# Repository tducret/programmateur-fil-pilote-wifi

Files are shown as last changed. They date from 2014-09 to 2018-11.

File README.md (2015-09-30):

Le programmateur fil pilote WiFi open source
============================================

Principe
--------
Avec de simples requêtes HTTP, vous allez pouvoir :
- **Contrôler vos chauffages électriques** (7 zones / 4 ordres fil pilote)
- **Récupérer votre consommation électrique** (et toutes les informations du compteur électrique)

Avantages :
- **Pas de serveur dédié nécessaire**
- **Intégration facile dans le tableau électrique**
- **Connexion WiFi** (pas de câble Ethernet à connecter)

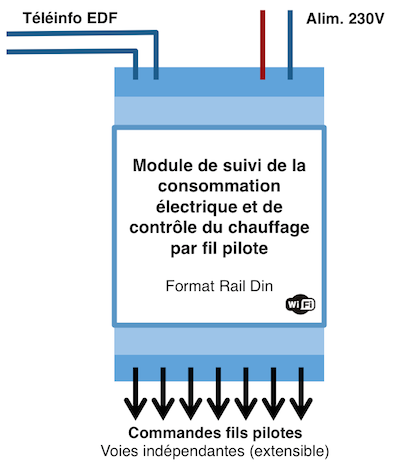
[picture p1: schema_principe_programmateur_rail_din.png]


Idées d'applications
--------------------
- Contrôle de la température de chaque pièce via votre box domotique
- Coupure du chauffage automatique en cas de consommation électrique trop importante (délestage)
- Lancement du chauffage en partant du travail à partir de votre smartphone
- Et bien d'autres...

Licence
-------
Les codes sources sont distribués sous la licence MIT
Les autres éléments sont distribués sous la licence [Creative Commons Attribution-NonCommercial-ShareAlike 4.0](https://creativecommons.org/licenses/by-nc-sa/4.0/)

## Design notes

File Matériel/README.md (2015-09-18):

Liste matériel 
==============

BOM File
--------
Vous trouverez la liste du matériel en fonction de la version à l'adresse [suivante][1] (google doc)

[1]: https://docs.google.com/spreadsheets/d/1HEebySHMIzUFYeRYVwTHakMmaWHZ26DxMvw0GtgDD7c

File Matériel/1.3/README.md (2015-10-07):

Version matérielle 1.3
=======================

Modifications
-------------
Cette version reprend toutes les caractéristiques de la version [initiale][1] en y ajoutant les fonctionnalités suivantes :

- Ajout d'un contrôleur d'entrées sortie I2C [MCP23017][10] pour libérer les I/O du Spark Core
- Possibilité de mettre deux types de relais dont un [avec contact NO + NF][5]
- Possibilité de mettre un emetteur récepteur sans fil de type [RFM12B][6], [RFM69CW][7], [RFM69HW][8] ou [RFM69CW][9] 433Mhz ou 868MHz
- Possibilité de mettre un [récepteur 433MHz][4] pour récupérer par exemple les trames des capteurs de température Orégon Scientific
- Ajout d'un connecteur I2C ET SPI pour des afficheurs OLED de type [I2C][2] ou [SPI][3]
- Ajout d'un connecteur de type Grove I2C
- Ajout d'une LED 3mm (déportable ou non) sur le boitier 
- Ajout de pin out disponibles sur toutes les pattes du Spark Core

Changements apportés dans la révision 1.3 vs 1.2 
- Ajout d'un étage a MOSFET pour la téléinfo, pour une meilleure compatibilité di signal téléinfo
- Ajout d'une RGB LED pour ESP8266
- Ajout d'un pont diviseur sur le recepteur 433MHZ pour transformer sa sortie 5V en 3V3 pour l'ESP8266
- Possibilité de mettre une base ESP8266 (NodeMCU) via cet [adaptateur][11]

Description Détaillée
=====================

**Schematic**  
schematic

**Boards**  
board&nbsp;
top&nbsp;
bottom

[1]: https://github.com/thibdct/programmateur-fil-pilote-wifi/blob/master/README.md
[2]: http://www.ebay.com/itm/291216700457
[3]: http://www.ebay.com/itm/141371873602
[4]: http://www.ebay.com/itm/290935235157
[5]: http://www.seeedstudio.com/depot/index.php?main_page=opl_info&opl_id=136

[6]: http://www.anarduino.com/details.jsp?pid=142
[7]: http://www.anarduino.com/details.jsp?pid=145
[8]: http://www.anarduino.com/details.jsp?pid=136
[9]: http://www.anarduino.com/details.jsp?pid=122
[10]: http://www.adafruit.com/product/732
[11]: https://github.com/hallard/Particle2NodeMCU

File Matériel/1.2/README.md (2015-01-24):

Version matérielle 1.2c
=======================

Modifications
-------------
Cette version reprend toutes les caractéristiques de la version [initiale][1] en y ajoutant les fonctionnalités suivantes :

- Ajout d'un contrôleur d'entrées sortie I2C [MCP23017][10] pour libérer les I/O du Spark Core
- Possibilité de mettre deux types de relais dont un [avec contact NO + NF][5]
- Possibilité de mettre un emetteur récepteur sans fil de type [RFM12B][6], [RFM69CW][7], [RFM69HW][8] ou [RFM69CW][9] 433Mhz ou 868MHz
- Possibilité de mettre un [récepteur 433MHz][4] pour récupérer par exemple les trames des capteurs de température Orégon Scientific
- Ajout d'un connecteur I2C ET SPI pour des afficheurs OLED de type [I2C][2] ou [SPI][3]
- Ajout d'un connecteur de type Grove I2C
- Ajout d'une LED 3mm (déportable ou non) sur le boitier 
- Ajout de pin out disponibles sur toutes les pattes du Spark Core

Changements apportés dans la révision 1.2c 
- Correction informations du silk au niveau du connecteur grove
- Déplacement connecteur grove pour ne pas géner en cas d'insertion un module grove
- Déplacement de la LED pour qu'elle ne soit plus située sous le LCD
- Agrandissement des PAD des optos pour une soudure plus aisée
- Inversion des plots 3.3V et GND afin de pouvoir souder un double plot uniquement (5V+GND), les triples étant moins facile à trouver et je suis pas certain que le 3.3V soit utilisé (mais il reste disponible)

Attention, deux erreurs étaient présentes sur le PCB 1.2 original (corrigées dans la revision 1.2c) :
- le dessin sur le PCB du connecteur grove est inversé, donc si vous souhaitez le souder, il faut le faire dans le sens inversé par rapport au dessin du PCB (mais toujours à souder sur le dessus).
- la diode D14 est inversée, il faut donc la souder dans le sens inverse de ce qui est indiqué sur le PCB

Description Détaillée
=====================

**Schematic**  
schematic

**Boards**  
board&nbsp;
top&nbsp;
bottom

[1]: https://github.com/thibdct/programmateur-fil-pilote-wifi/blob/master/README.md
[2]: http://www.ebay.com/itm/291216700457
[3]: http://www.ebay.com/itm/141371873602
[4]: http://www.ebay.com/itm/290935235157
[5]: http://www.seeedstudio.com/depot/index.php?main_page=opl_info&opl_id=136

[6]: http://www.anarduino.com/details.jsp?pid=142
[7]: http://www.anarduino.com/details.jsp?pid=145
[8]: http://www.anarduino.com/details.jsp?pid=136
[9]: http://www.anarduino.com/details.jsp?pid=122
[10]: http://www.adafruit.com/product/732

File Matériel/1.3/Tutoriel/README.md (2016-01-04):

# Tutoriel d'assemblage de Remora v1.3

<!--Liste de toutes les images utilisées-->
[Schéma implantation]: ../ProgrammateurFilPilote_1.3_Schematic.png
[PCB face avant]: ../ProgrammateurFilPilote_1.3_Recto.png
[PCB face arrière]: ../ProgrammateurFilPilote_1.3_Verso.png
[Le contenu du kit]: Images/Le_contenu_du_kit.jpg
[Outillage]: Images/Outillage.jpg

## Remora

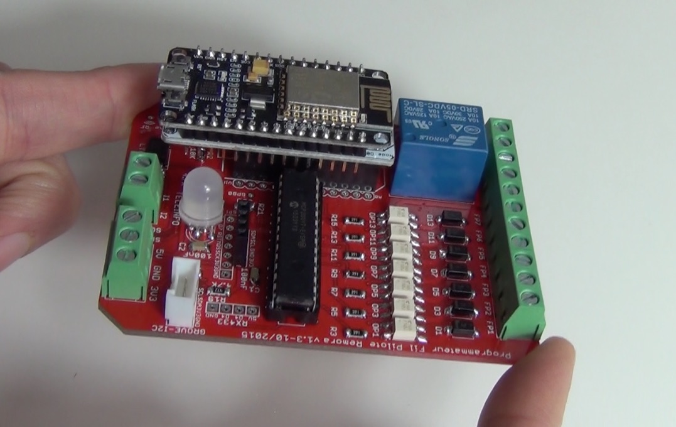
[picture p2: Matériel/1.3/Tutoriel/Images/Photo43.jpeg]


Remora, c'est un programmateur de chauffages par fils pilotes.

- Il peut contrôler 7 zones et un chauffe-eau (via 1 relais)
- Il se commande via des requêtes HTTP en WiFi
- Il est open source et open hardware

## Contenu du kit
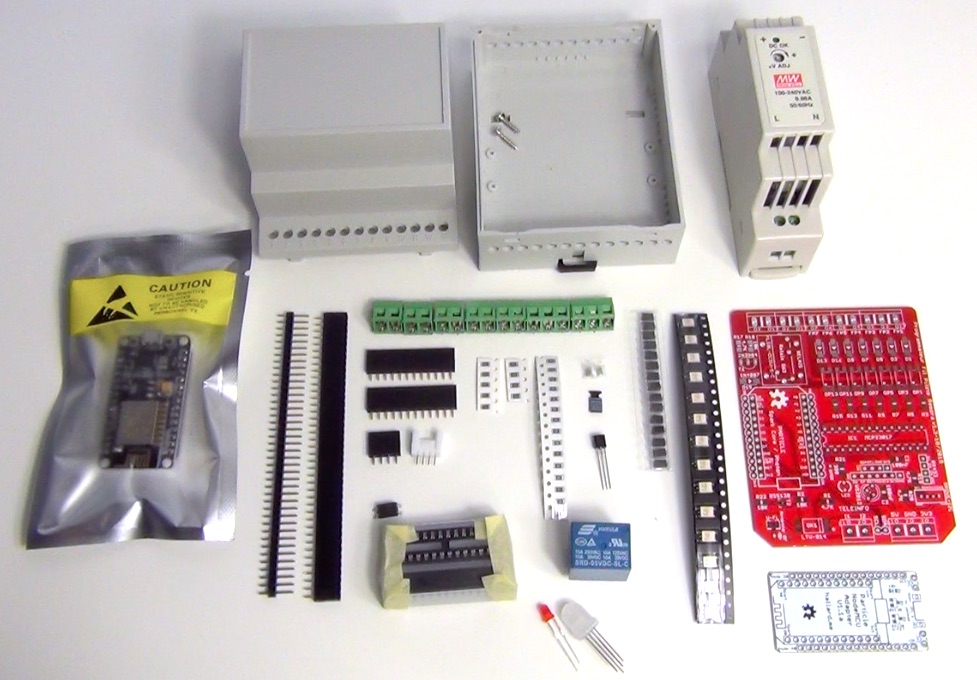
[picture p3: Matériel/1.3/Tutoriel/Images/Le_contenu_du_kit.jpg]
Le contenu du kit


- 1 NodeMCU
- 1 Boîtier RAIL DIN (4U : 71 x 90 x 58 mm)
- 1 Circuit imprimé Remora (v1.3)
- 1 Circuit imprimé Adaptateur NodeMCU->Remora (v1.1a)
- 1 Alimentation 5V RAIL DIN (1U - 12W)
- 14 Optotriacs
- 15 Diodes
- 1 MCP23017
- 1 Support MCP23017
- 2 Connecteur 1x12pt femelle Remora->NodeMCU
- 1 Barrette 40 pins male
- 1 Barrette 40 pins femelle
- 1 LED rouge 3mm
- 1 Transistors NPN
- 1 Led RGB 5mm
- 1 Relais
- 2 Borniers 3pts
- 5 Borniers 2 pts
- 1 Optocoupleur Teleinfo
- 1 Transistor BSS138
- 4 Resistance 10KΩ (format 1206)
- 5 Resistance 4.7KΩ (format 1206)
- 15 Resistance 390Ω (format 1206)
- 2 Condensateur 100nF (format 1206)
- 1 Connecteur 1x4pt OLED femelle
- 1 Connecteur Grove

## Outillage

Pour réaliser le module, vous aurez besoin de :

- 1 Fer à souder à pointe fine [^1]
[^1]: J'utilise un Antex XS25.
- 1 Bobine de fil d'étain (de préférence 0,5 mm)
- 1 Multimètre (pour vérifier les soudures)
- 1 Pince coupante
- 1 Petite pince (ou brucelle)
- 1 troisième main (facultatif mais bien utile) 

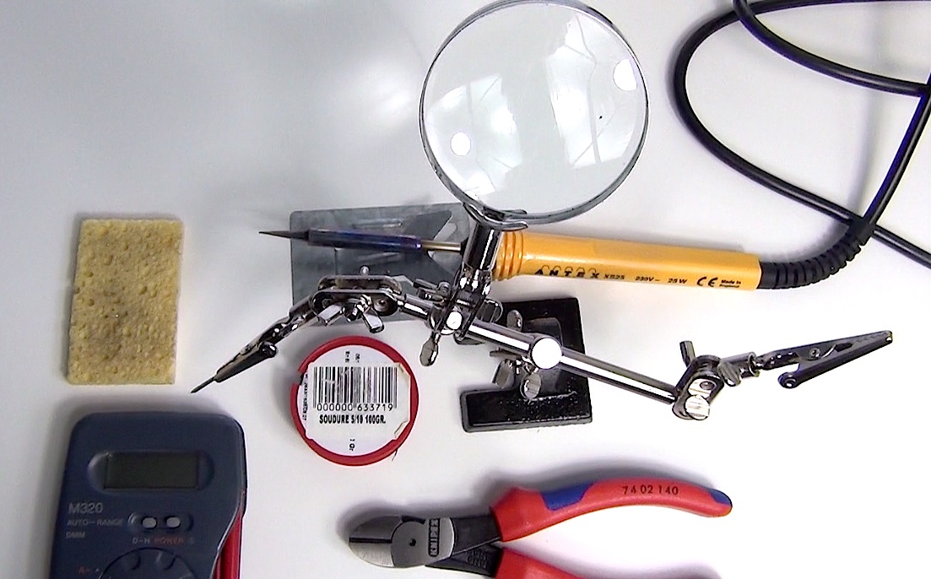
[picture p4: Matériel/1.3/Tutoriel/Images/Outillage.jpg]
Outillage


## Schéma d'implantation

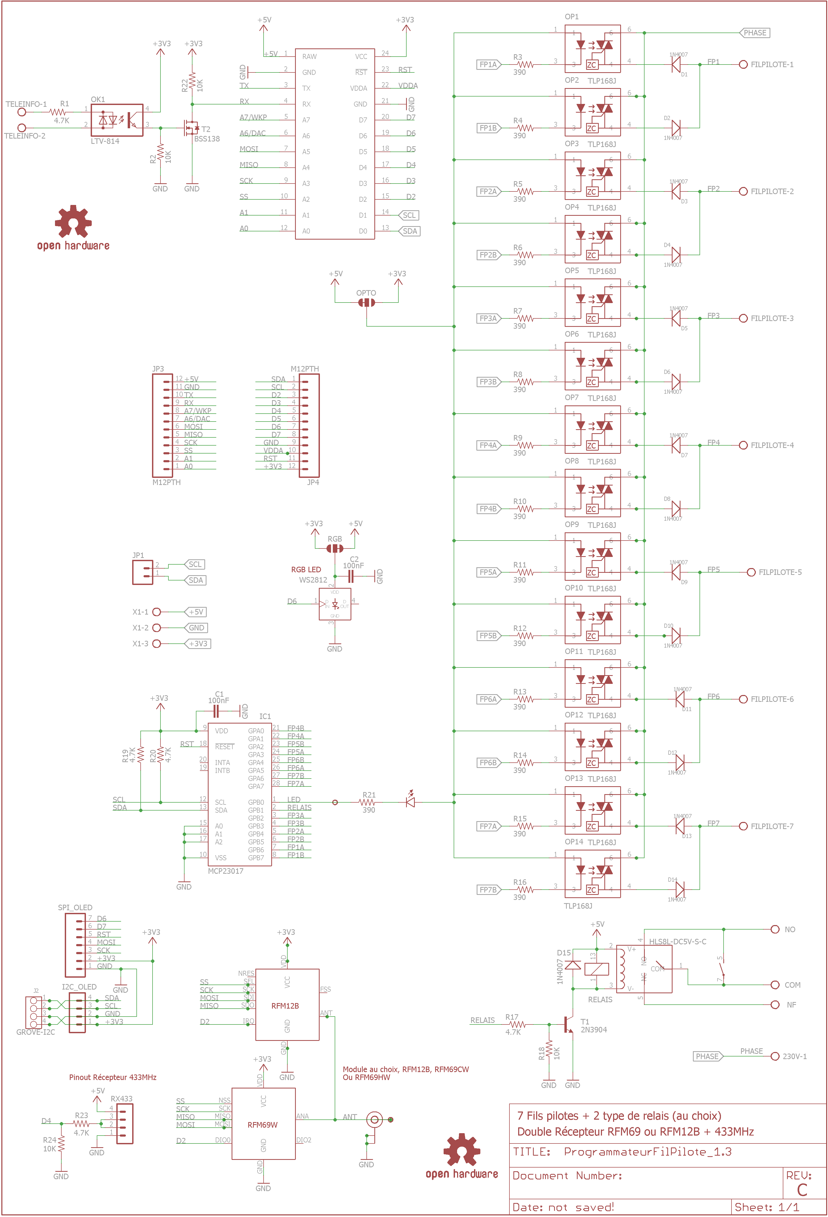
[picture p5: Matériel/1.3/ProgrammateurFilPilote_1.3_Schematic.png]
Schéma implantation


*Nota : Il est bien utile d'avoir un exemplaire imprimé du schéma d'implantation près de soi lorsque l'on fait les soudures*

## Le circuit imprimé

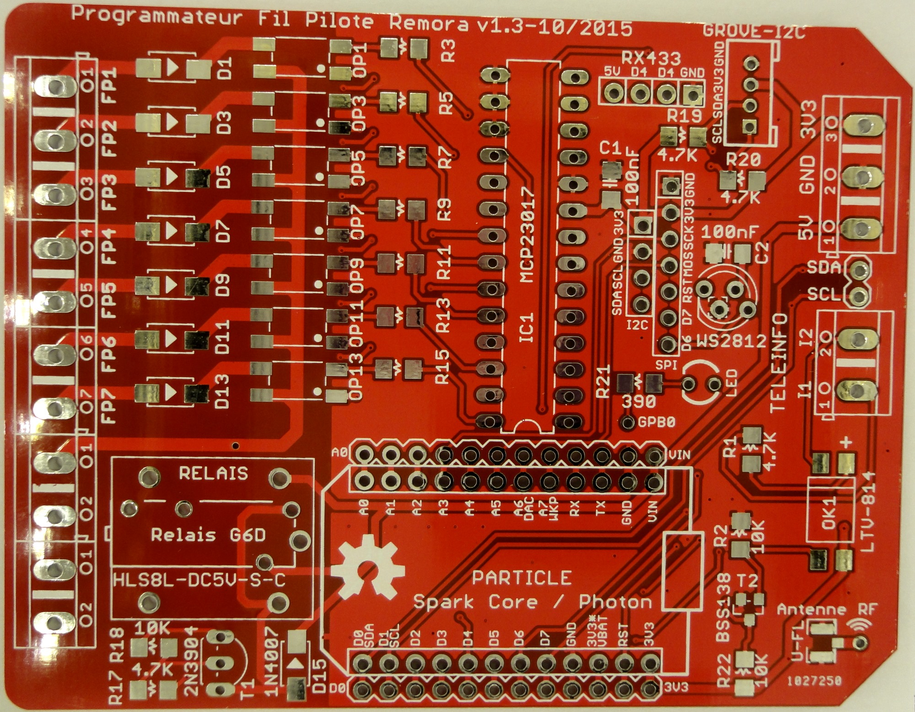
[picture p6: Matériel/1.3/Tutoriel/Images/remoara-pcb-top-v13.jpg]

**Face avant**

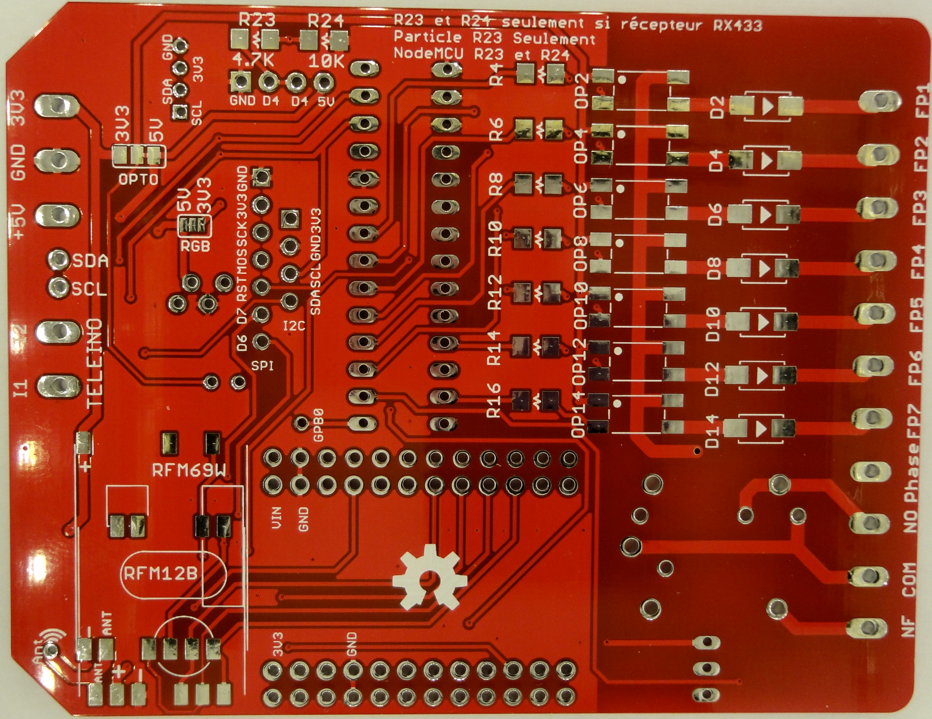
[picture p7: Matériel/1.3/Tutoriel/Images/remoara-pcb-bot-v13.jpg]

**Face arrière**

Identifiant du composant	| Description
--------------------------	| -----------------------------
R1, R17, R19, R20			| Résistance de 4,7KΩ
R2, R18, R22				| Résistances de 10KΩ
R3 à R16, R21				| Résistances de 390Ω
D1 à D15					| Diodes de redressement
T1							| Transistor NPN (2N3904)
T2							| Transistor Opto BSS138
OP1 à OP14					| Optotriacs
C1, C2						| Condesateurs 100nF
IC1							| MCP23017
OK1							| Optocoupleur LTV-814S

Non utilisés dans le kit : R23, R24

## Soudure

L'objectif est de souder les composants dans un ordre nous permettant de ne pas être gêné.  
La stratégie est simple : **on va souder les petits composants avant les gros, en commençant par la face avant, puis la face arrière.**

### Face avant

----------

##### Soudure des diodes D1, D3, D5, D7, D9, D11 et D13
'M7' est indiqué sur chacune des diodes. La barre à gauche du 'M' indique la cathode.  
**Il faut souder chaque diode de cette face en mettant la barre du côté de D1, D3...**
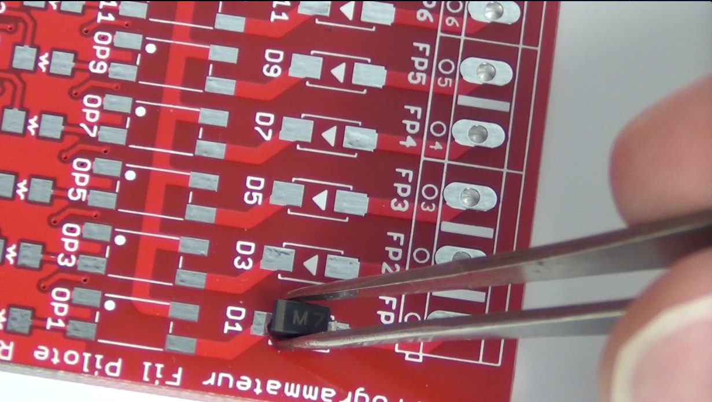
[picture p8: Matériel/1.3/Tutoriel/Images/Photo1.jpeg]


**Astuce de soudure CMS**
J'utilise ma "troisième main" et une simple pointe pour maintenir les composants de petite taille
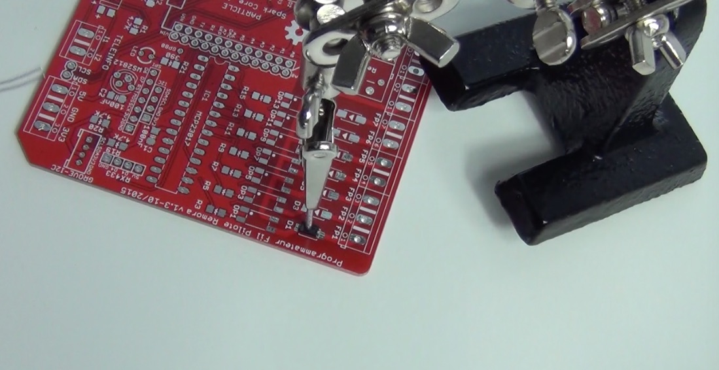
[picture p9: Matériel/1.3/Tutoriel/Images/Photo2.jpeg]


*Autre astuce, la favorite de Charles qui n'a pas de 3eme main*
Regardez cette [video][3] à 1M50 c'est beaucoup plus clair que mes explications (pas besoin de flux au pinceau, pas d'inquiètude) et très bien détaillé. 
Attenton contraitement à la vidéo, pour souder le 2eme pad il vaut mieux chauffer le pad plutôt que mettre la soudure sur la panne du fer (sauf si vous avez du flux).

Donc en résumé :
- Soudure dans une main, fer dans l'autre et on met un peu de soudure sur une pastille du PCB de chaque composant à placer
- Pince + composant dans une main, fer dans l'autre et on les place en chauffaut la soudure dejà placée
- Soudure dans une main, fer dans l'autre et on soude les autres pastilles des composants déjà placés.

Voici ce que ça donne de plus près, retour à la méthode de Thibault
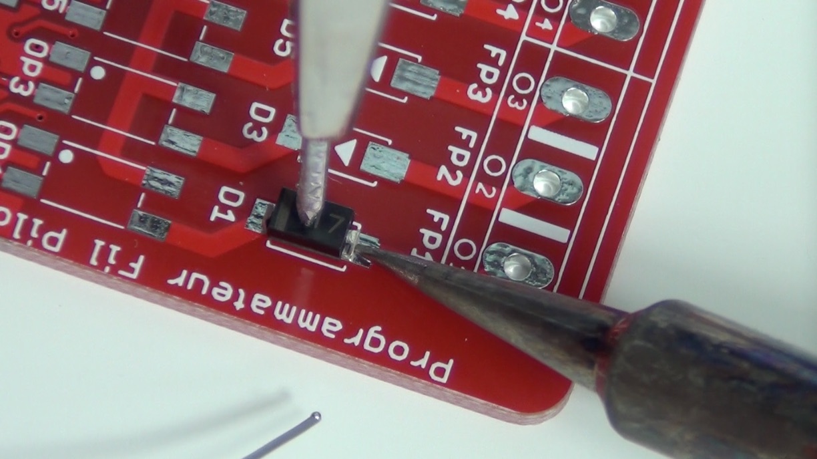
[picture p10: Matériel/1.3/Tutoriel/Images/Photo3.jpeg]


Et une fois les 7 diodes terminées

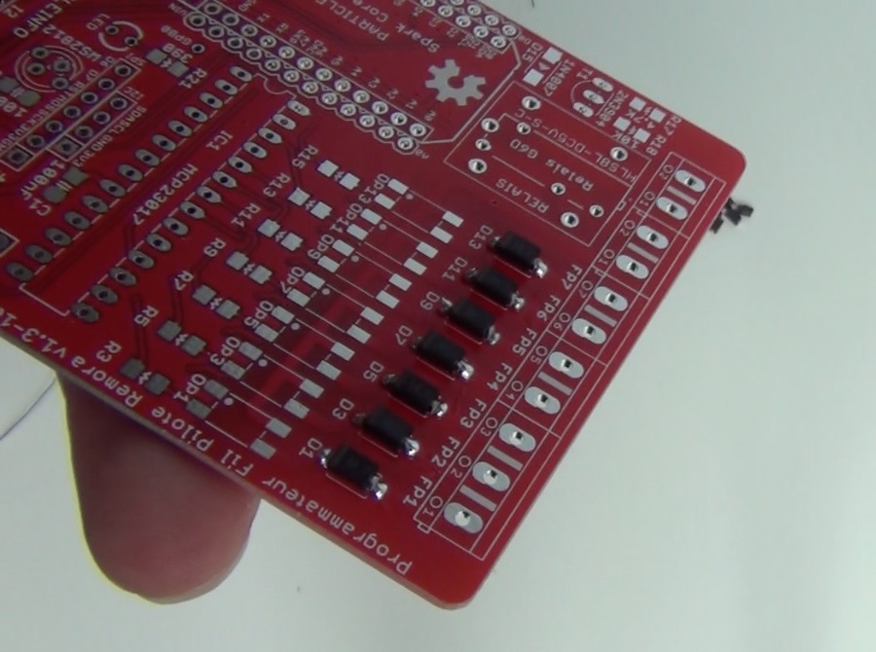
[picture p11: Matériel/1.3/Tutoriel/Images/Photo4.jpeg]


----------

##### Soudure des optotriacs OP1, OP3, OP5, OP7, OP9, OP11 et OP13
Il existe 2 sortes d'optotriacs. Leur fonctionnement et soudure sont indentiques.

Vous verrez 'P168J' (le composant est jaune)
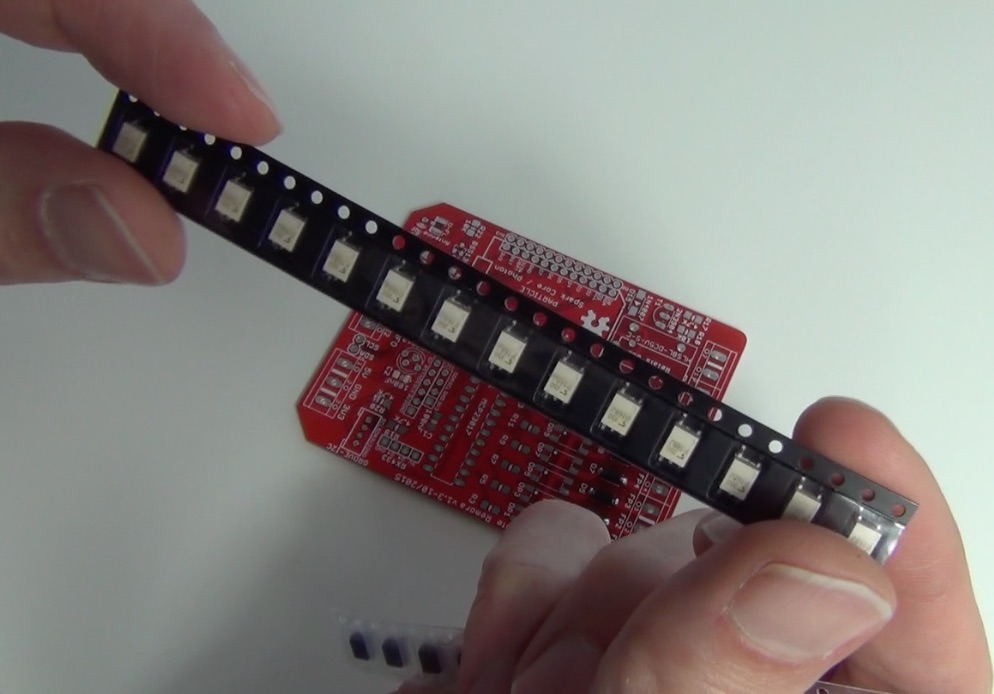
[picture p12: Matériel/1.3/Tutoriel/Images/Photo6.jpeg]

ou 'SF22S4' (le composant est noir)
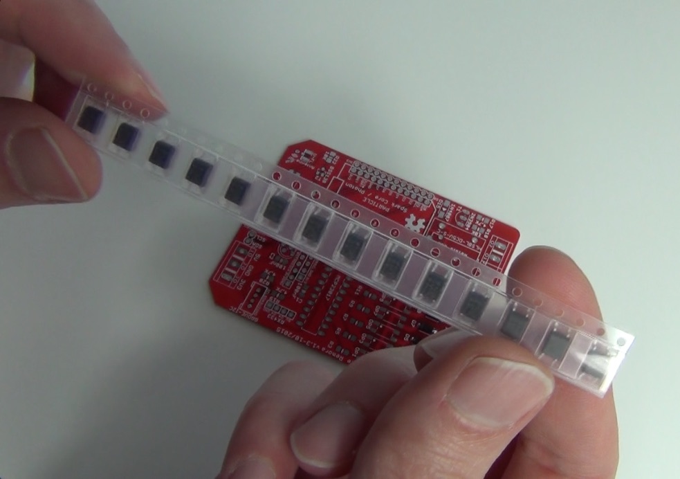
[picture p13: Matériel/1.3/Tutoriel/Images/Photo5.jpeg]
.

Pour les 2 sortes, un point est présent sur le coin en bas à gauche du composant.  
**Il faut bien s'assurer que le point du composant correspond au point sur le circuit imprimé**

On procède à la soudure comme précédemment
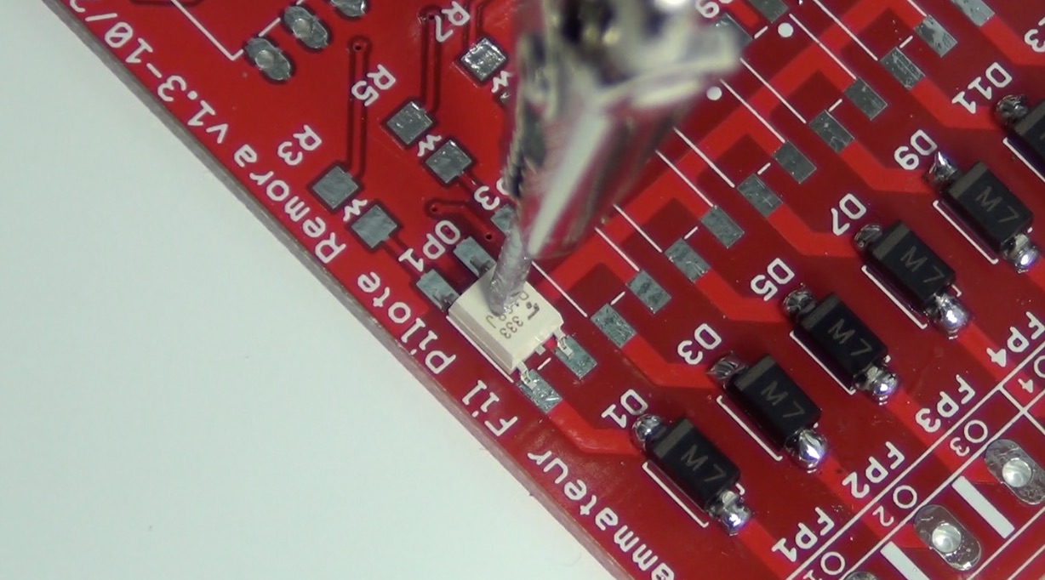
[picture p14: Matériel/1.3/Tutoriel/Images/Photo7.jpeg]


Ce qui nous donne
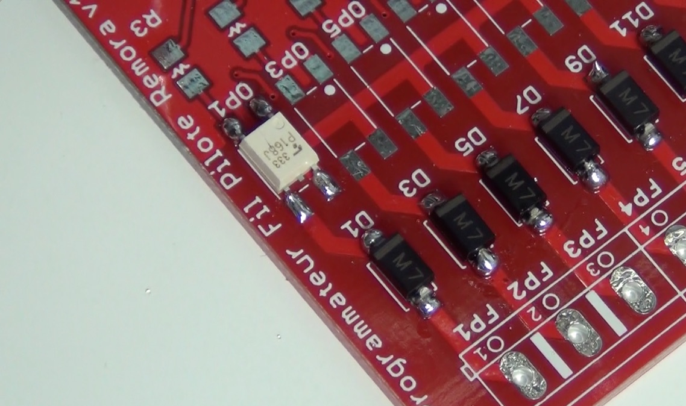
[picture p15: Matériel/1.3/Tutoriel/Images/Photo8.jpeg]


Et une fois les 7 optotriacs terminés
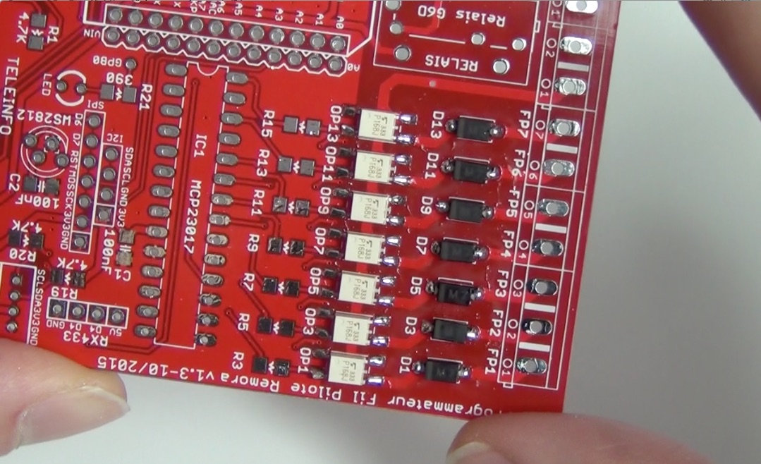
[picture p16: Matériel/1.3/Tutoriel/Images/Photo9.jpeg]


----------

##### Soudure des résistances R3, R5, R7, R9, R11, R13 et R15 (390Ω)
Il est indiqué '391' dessus (comme 39x10^1=390Ω). Pas de sens à respecter.
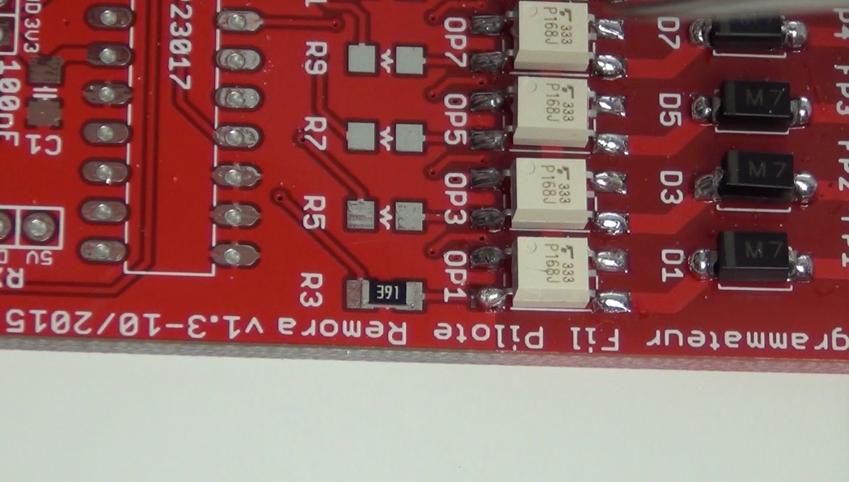
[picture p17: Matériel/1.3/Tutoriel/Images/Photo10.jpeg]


Et une fois les 7 résistances terminées
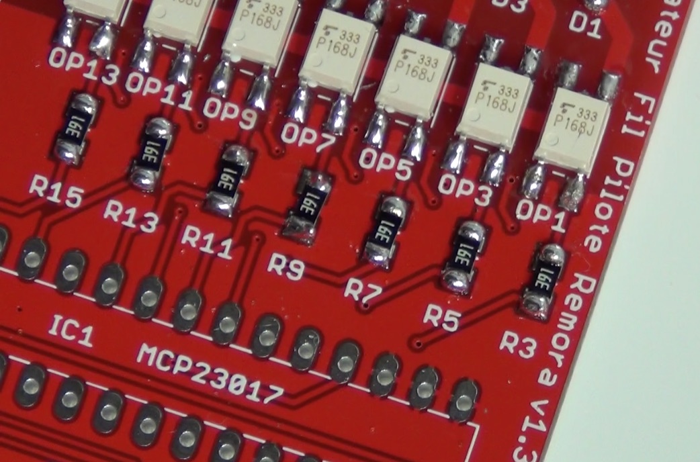
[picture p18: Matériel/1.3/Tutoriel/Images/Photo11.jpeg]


----------

De la même manière, procédez aux soudures suivantes :

Soudure de la résistance R18 (10KΩ) : Il est indiqué '103' dessus 

Soudure de la résistance R17 (4,7KΩ) : Il est indiqué '472' dessus 

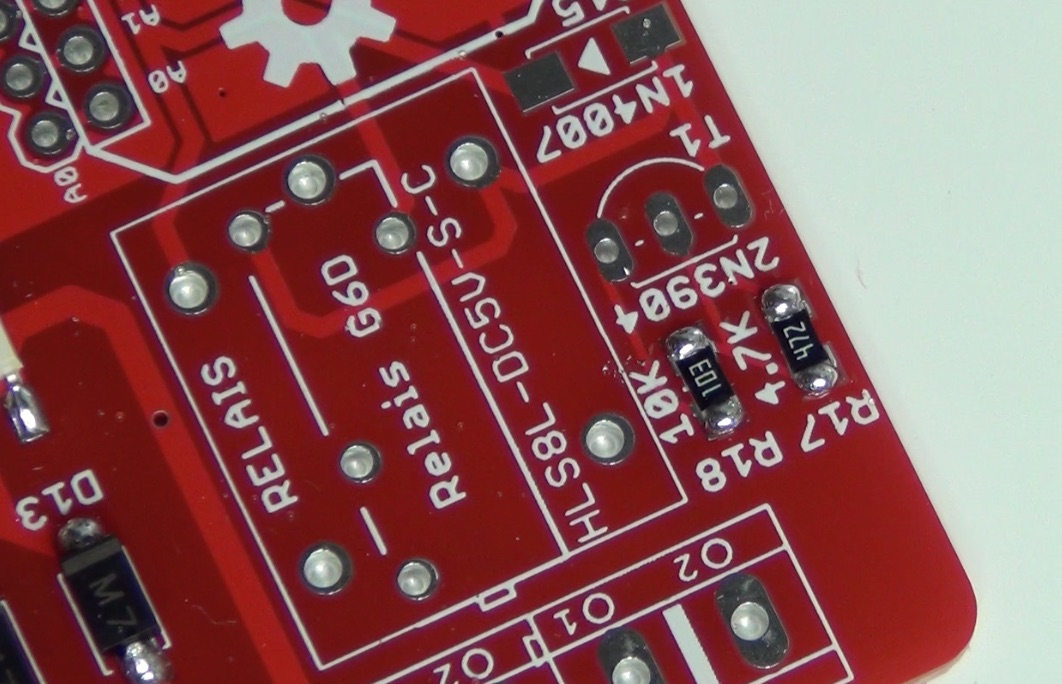
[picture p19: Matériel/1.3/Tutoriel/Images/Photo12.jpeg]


----------

##### Soudure de la diode D15
'M7' est indiqué dessus. La barre à gauche du 'M' indique la cathode.  
**Il faut souder la diode en mettant la barre du côté du '7' de '1N4007**
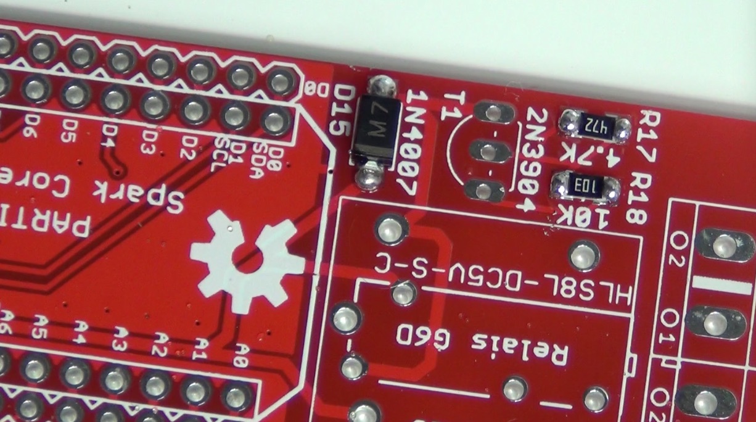
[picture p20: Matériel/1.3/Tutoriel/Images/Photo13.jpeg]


----------

Soudure de la résistance R2 (10KΩ) : Il est indiqué '103' dessus

Soudure du transistor T2 (**Très petit. Attention de bien mettre ses pattes sur la carte**)

Soudure de la résistance R22 (10KΩ) : Il est indiqué '103' dessus 

Soudure de la résistance R1 (4,7KΩ) : Il est indiqué '472' dessus 

Soudure de la résistance R21 (390Ω) : Il est indiqué '391' dessus
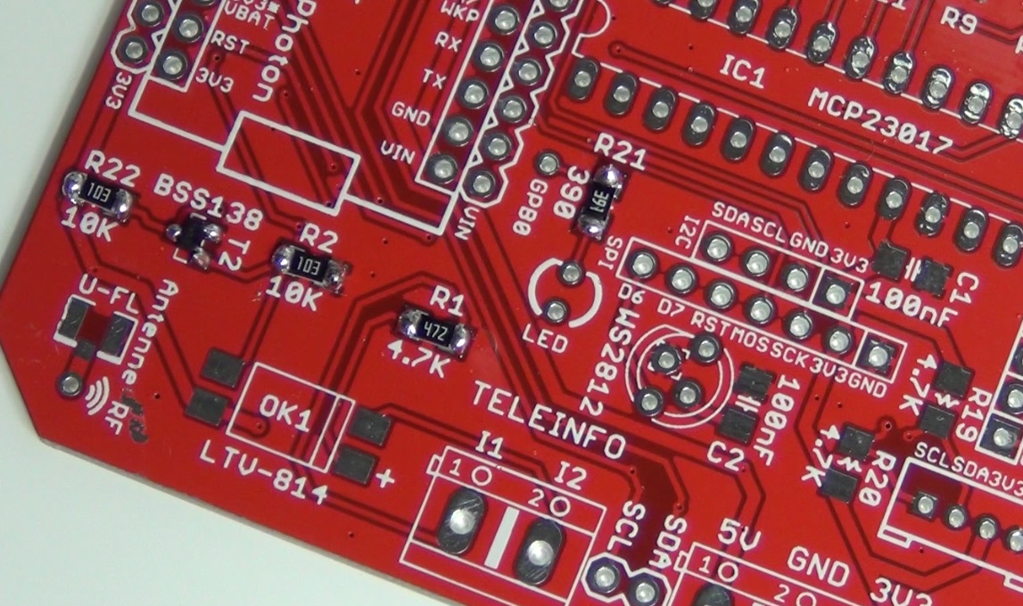
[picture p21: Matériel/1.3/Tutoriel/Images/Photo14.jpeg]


----------

Soudure des condensateurs C1 et C2 : Pas de sens particulier
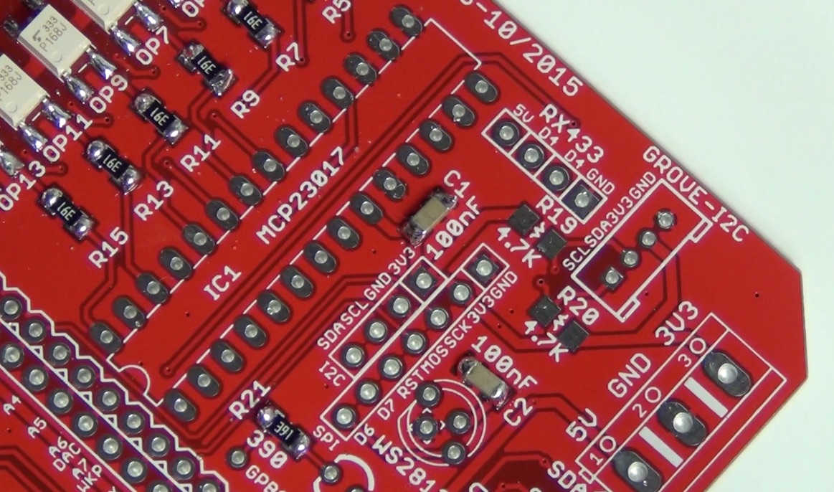
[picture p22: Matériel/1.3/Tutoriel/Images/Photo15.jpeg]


----------

Soudure des résistances R19 et R20 (4,7KΩ) : Il est indiqué '472' dessus  
*Pas de photo*

### Face arrière

##### Soudure des diodes D2, D4, D6, D8, D10, D12, D14  
'M7' est indiqué sur chacune des diodes. La barre à gauche du 'M' indique la cathode. **Attention : Pour cette face, il faut souder chaque diode en mettant la barre du côté des borniers FP1, FP2...**

##### Soudure des optotriacs OP2, OP4, OP6, OP8, OP10, OP12, OP14 
**Il faut bien s'assurer que le point du composant correspond au point sur le circuit imprimé**

Soudure des résistances R4, R6, R8, R10, R12, R14, R16 (390Ω) : Il est indiqué '391' dessus 
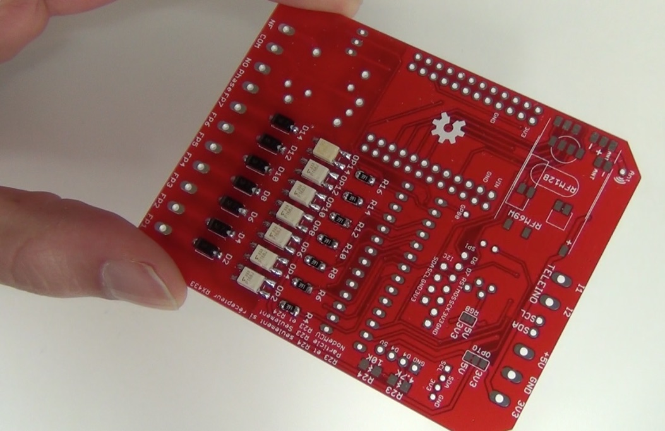
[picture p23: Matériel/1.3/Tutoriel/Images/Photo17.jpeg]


----------

Soudure du support pour IC1
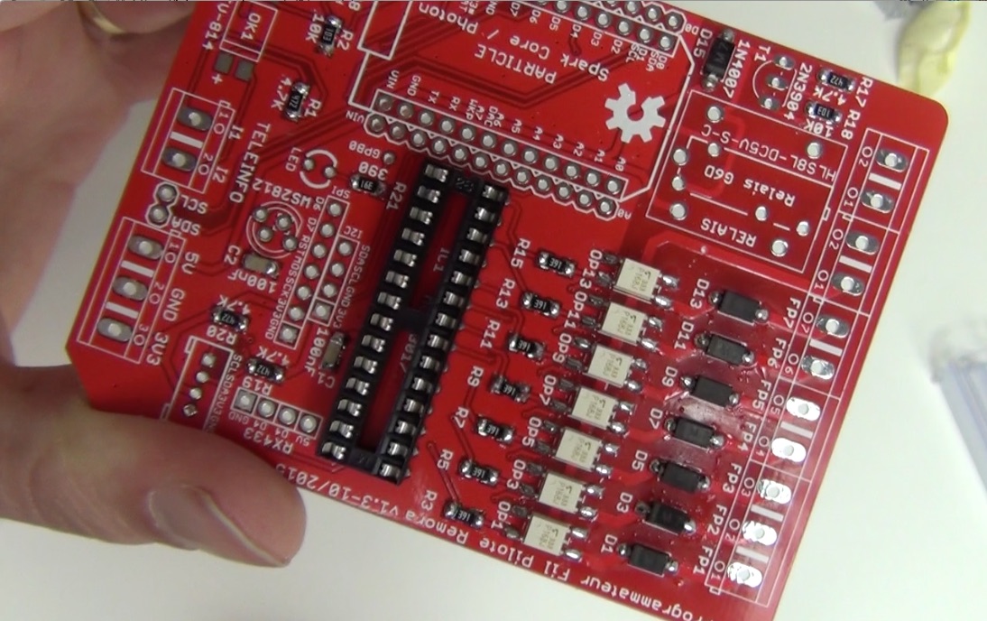
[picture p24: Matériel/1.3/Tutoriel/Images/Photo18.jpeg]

Et de l'autre côté
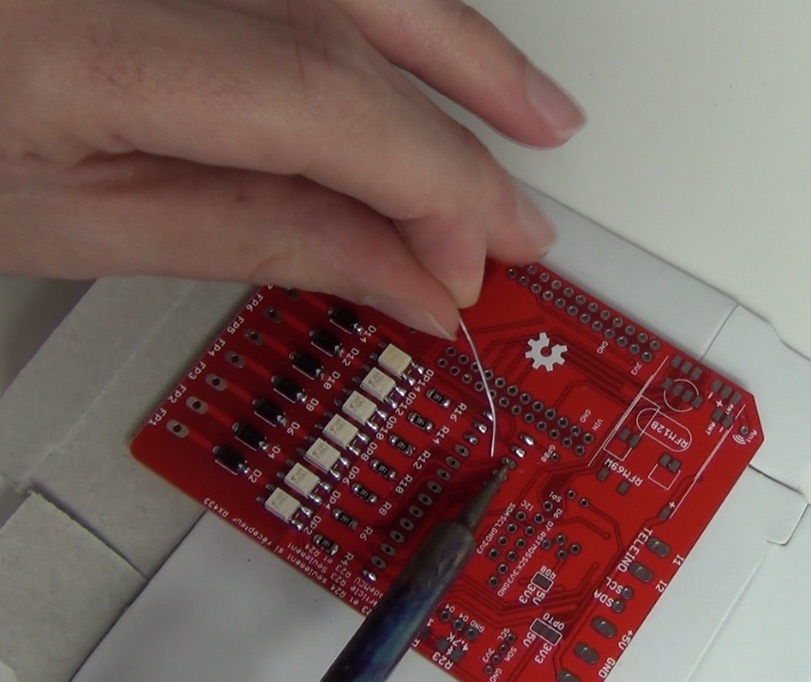
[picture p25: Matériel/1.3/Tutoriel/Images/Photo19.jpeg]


----------

Soudure du transistor T1 (** Attention à la polarité : il faut repérer la forme arrondie du composant **)


On soude les pattes du transistor de l'autre côté, puis on coupe les bouts qui dépassent. 

**On garde un bout de patte pour la suite**

### Zoom sur l'adaptateur NodeMCU vers Particle Photon/Spark Core

On soude le bout de patte de transistor coupé pour faire un pont sur JP2


On découpe un bout de barrette male pour faire 2 barrettes de 12 pins chacune.  
Puis, on les insère dans les barrettes femelles de 12 pins.


On insère ces barrettes dans l'adaptateur (**En veillant au côté de l'adaptateur choisi**)


On insère le tout sur la carte Remora


On soude les 24 pins


Pui, on retourne la carte avec précaution


Et on soude les 24 pins du dessous


Une fois les soudures sèches, on retire l'adaptateur de la carte Remora.  
On insère le NodeMCU sur l'adaptateur


On retourne l'adaptateur


On soude les 32 pins


### Retour sur la carte Remora

Soudure du connecteur OLED


----------

Soudure du connecteur Grove


----------

On assemble 1 bornier de 3 points + 4 borniers de 2 points


Puis on les soude



On soude ensuite le bornier de 3 points (5V, GND, 3V3) ainsi que le bornier de 2 points (I1, I2)

----------

Soudure du relais


----------

Soudure de la petite LED rouge (**Observez bien le sens : la patte la plus longue est du côté des borniers I1, I2**)


----------

Soudure de la grosse LED RGB (multicolore)
** Faire bien attention aux pins de cette LED **


On coupe ensuite les pattes qui dépassent des 2 LEDs


### Retour sur la face avant

Soudure de l'optocoupleur OK1 (**Attention à la polarité : le point sur le composant est en face du + sur la carte **)


## Rendu final

### Face avant


### Face arrière


### Test des soudures

### Montage dans le tableau électrique

TODO

## Programmation du NodeMCU

Le logiciel à flasher dans le NodeMCU se trouve sur ce [repo github][1], c'est maintenant le nouveau repo officiel, l'ancien est toujours [disponible][2] pour historique.

## Test du module complet

Si vous recontrez des soucis de commande des fils pilotes (tout est ok mais l'état du radiateur ne correspond pas à l'état indiqué dans le logiciel) avec des Optocoupleurs blancs voici la [procédure][4] pour les passer en 3.3V.

TODO

[1]: https://github.com/hallard/remora_soft
[2]: https://github.com/thibdct/programmateur-fil-pilote-wifi/tree/master/Logiciel/remora
[3]: http://youtu.be/3NN7UGWYmBY
[4]: https://community.hallard.me/topic/103/

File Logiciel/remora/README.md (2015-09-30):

Version Logicielle pour toutes les versions du matériel
=======================================================

Cette version logicielle est compatible avec la version matérielle [1.2][1] ainsi que les anciennes versions des cartes electroniques. Elle est aussi compatible avec les cartes à base d'ESP8266 via un [adaptateur][5]

Installation (Particle)
-----------------------

- Télécharger l'environnement de développement [Particle-Dev][2] puis lancer l'IDE.
- Télécharger l'archive du repo logiciel [github][3] et le copier sur votre disque dur puis le décompresser
- Une fois l'IDE ouvert, menu File/Open et ouvrir le dossier programmateur-fil-pilote-wifi-master\Logiciel\remora
- Dans le menu Particle/Log in to Particle Cloud, entrez vos identifiants Particle pour vous connecter
- Dans le menu Particle/Select Device selectionnez votre Spark Core ou Particle Photon
- Ouvrir ensuite depuis l'IDE les fichers remora.ino et remora.h
- Selectionner la version de carte utilisé dans le fichier remora.h (les defines REMORA_BOARD_Vxx)
- Selectionner les modules utilisés dans le fichier remora.h (les defines MOD_xxxx)
- Selectionner l'onglet remora.ino
- Lancer la compilation+upload (icone éclair en haut à gauche)
- Si vous avez une erreur de type "App code was invalid" durant la compilation, supprimer le ficher README.md du dossier

Installation (Arduino ESP8266)
------------------------------

- Suivre la procédure détaillée [ici](https://github.com/esp8266/Arduino)
- Ouvrir ensuite depuis l'IDE le ficher remora.ino
- Selectionner la version de carte utilisé dans le fichier remora.h (les defines REMORA_BOARD_Vxx)
- Selectionner les modules utilisés dans le fichier remora.h (les defines MOD_xxxx)
- choisir la carte NodeMCU 1.0 (ESP12E-Module) ainsi que le bon serial port
- Lancer la compilation + upload 
- La procédure OTA sera détaillée ultérieurement

API Exposée
-----------

Description complète bientôt

A faire
-------

- Mettre des icones plus sympas sur l'afficheur
- Gérer les retour de sondes RF, pour le moment seules les trames sont affichées sur la serial, rien n'est encore fait
- Gérer le RF des sondes Oregon Scientific
- pour le moment seul les [OLED][4] I2C sont gérés
- tout autre idée est bienvenue

Historiques des Modifications
-----------------------------
16/02/2015 : Ajout délestage cascadocyclique / Possibilité de ne récupérer l'état que d'un seul fil pilote

14/04/2015 : Ajout d'une variable spark pour la teleinfo. Passage en un seul appel pour script jeedom. Les variables d'origine restent utilisables.

30/09/2015 : voir le post [dédié][6].   

Exemple
-------

Pour les photos la téléinfo n'était pas branchée sur la carte, c'est pour celà que les compteurs et le bargraphe sont à 0

Top&nbsp;
Bottom
<br>

Avec la téléinfo branchée sur la carte, le bargraph indique la puissance instantanée par rapport au contrat souscrit, ici soit 11% car on consomme 5A sur un contrat de 45A. Nous sommes en heures pleines (affichage sur fond blanc)
Bottom

[1]: https://github.com/thibdct/programmateur-fil-pilote-wifi/tree/master/Mat%C3%A9riel/1.2
[2]: https://www.particle.io/dev
[3]: https://github.com/thibdct/programmateur-fil-pilote-wifi/archive/master.zip
[4]: http://www.ebay.com/itm/291216700457
[5]: https://github.com/hallard/Particle2NodeMCU/blob/master/README.md
[6]: https://community.hallard.me/topic/92/nouvelle-version-remora-compatible-esp8266

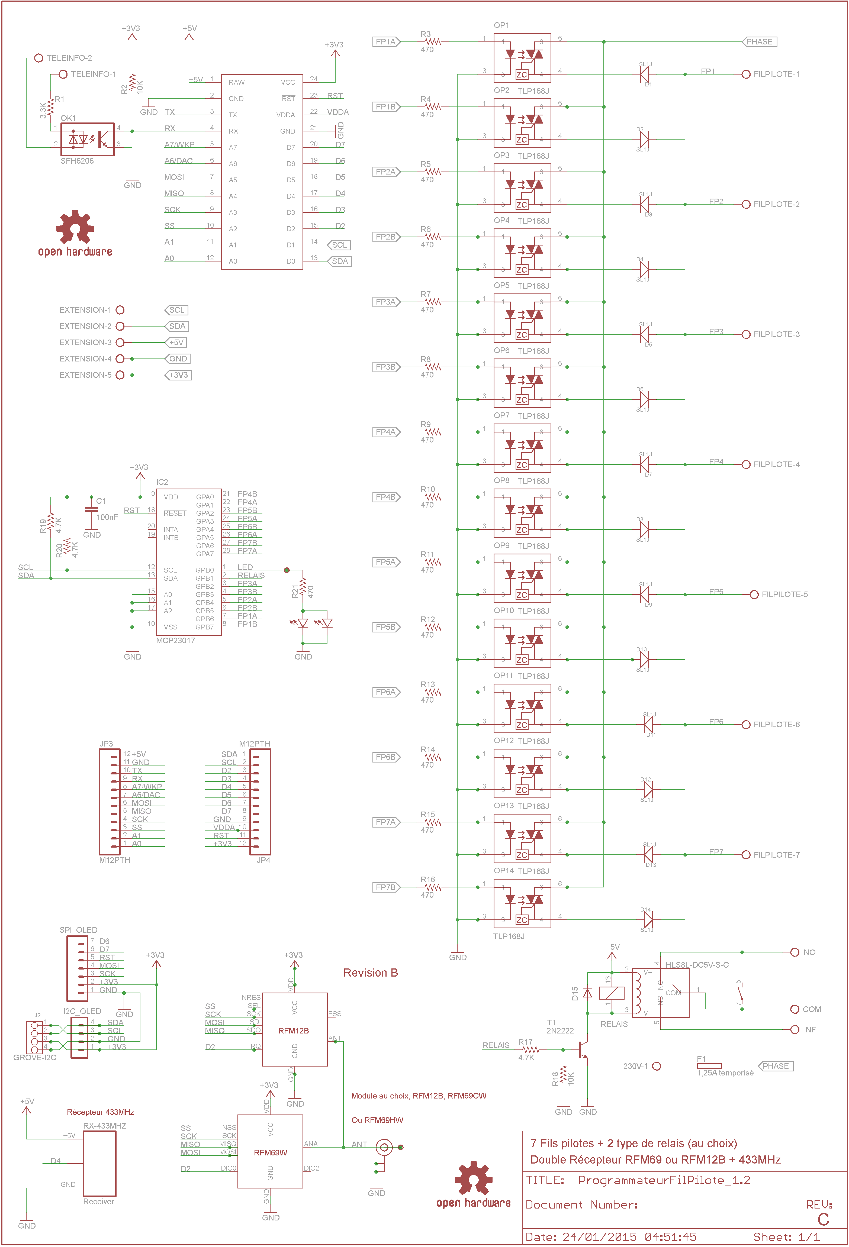
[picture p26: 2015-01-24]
Matériel/1.2/ProgrammateurFilPilote_1.2_Schematic.png

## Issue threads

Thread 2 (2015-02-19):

Amélioration

Vebryn, 2015-02-19:
Bonsoir,

Excellent projet ! Bravo !

Un transistor NPN pour la commande des optocoupleurs sécuriserait les ports GPIO du MIC, je sais pas ce que t'en pense ?

Vebryn

hallard, 2015-02-19:
Bonjour Vebryn,

Dans la version Hard 1.2, les optos sont commandés par un MCP23017, le courant de commande est d'environ (3.3V-1.4V) soit 1.9V / 470 ohm soit 4 mA
les ports du MCP sont limités à 25mA/port avec une conso maximale du MCP limité à 125mA
Si les 14 optos sont actifs nous sommes a 56mA donc largement dans la plage de fonctionnement.
Je viens dans le doute de vérifier sur la Version 1, les pins du core sont au max 20mA/pin et un total de 150mA pour le core, donc pour moi aucun soucis.
Ceci dit, j'ai peut-être raté quelque chose, si c'est le cas je veux bien savoir, au contraire.

Vebryn, 2015-02-19:
Autant pour moi, merci pour tes lumières! Je réfléchi à adapter ton bébé à un Raspberry Pi. L'essentiel est là!

hallard, 2015-02-19:
Rendons à César ce qui est à César, ce n'est pas mon bébé mais celui de Thibault ;-)
J'ai juste participé aux nouvelles fonctionnalités de la V1.2

Ceci dit tu n'es pas le 1er à vouloir commander les fils pilotes avec un Pi.
- Soit il faut développer un shield spécifique
- Soit tu attaques le Remora avec des requêtes HTTP depuis un Pi, comme çà toute l'interface est gérée par le PI (ce qui serait une excellente idée pour l'IHM). En plus si t'as un PI tu peux se passer du cloud Spark et tout faire en cloud local avec le Pi (in premise comment ils disent) ;-)

Closed 2015-02-19.

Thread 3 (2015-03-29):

Compilation impossible sur V1.1.1

ooii, 2015-03-29:
Bonjour,

J'ai la version 1.1.1 du programmateur. J'essaie de compiler le code en utilisant l'IDE Spark mais je rencontre l'erreur suivante :
`pilotes.cpp: FP7 was not declared in this scope`
En effet, quand je regarde `pilotes.h`, il semblerait que FP7 ne soit déclaré que pour la version 1.0. Est-ce vraiment le cas ?
Merci encore pour ce projet et merci d'avance pour vos réponses.

thibdct, 2015-03-29:
Bonjour,
Pour la v1.1.1, on suppose que le relais est utilisé plutôt que le FP7. Le
code peut être modifié si besoin.

Le dim. 29 mars 2015 11:32, ooii <notifications@github.com> a écrit :

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

ooii, 2015-03-29:
OK, merci.
J'ai donc commenté la partie qui teste si c'est la 1.0 pour setter le FP7 et je le sette à A0,A1. C'est bien ça ?
Merci encore.

ooii, 2015-03-30:
Tout marche parfaitement. Merci encore.

Closed 2015-03-30.

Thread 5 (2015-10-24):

Y aurait-il une quelconque interface ?

ooii, 2015-10-24:
Bonjour à tous,

À part Jeedom (que je n'ai pas), je n'ai rien trouvé pour contrôler facilement mes chauffages en utilisant le boîtier. J'ai bien fait une petite page web mais elle est moche :)

thibdct, 2015-10-24:
Salut!

J'ai pas mal utilisé http://jflasher.github.io/spark-helper/ pour commencer.

A+

ooii, 2015-10-24:
Merci.
Mais c'est pas pratique à utiliser tous les jours pour allumer et éteindre telle ou telle zone.
J'ai fait quelque chose qui ressemble à ça et je cherche quelque chose dans le même esprit mais plus performant et un peu plus esthétique ;)
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

hallard, 2015-10-24:
@ooii
Je cherche depuis des lustres une interface WEB de programmation de thermostat simple, jolie, efficace, j'avoue que je n'ai jamais rien trouvé de satisfaisant

J'étais tombé sur ça à une époque, qui ressemblait à peut prêt à mes besoins
https://harizanov.com/2015/02/wifi-thermostat-with-weekly-scheduler/

ooii, 2015-10-24:
Merci beaucoup. Je vais y jeter un oeil. Je suis en train de voir si je peux faire une petite interface plus sympa que ce que j'avais (et qui marche très bien pour l'instant).

hallard, 2015-10-24:
Je la trouve cool ton interface :-)

ooii, 2015-10-28:
Bon, j'ai dû apprendre à utiliser Bootstrap et handlebars ces derniers jours pour faire une petite appli en nodejs. Elle est dispo là : https://github.com/ooii/Chauffage-nodejs/blob/nodejs/Server.js
On peut la merger au projet si ça vous intéresse.

@hallard Je viens de voir ton message. Sinon, je n'aurais pas passé du temps à faire une nouvelle version (plus rapide et un peu plus esthétique) ;)

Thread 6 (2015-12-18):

Conseils pour montage non centralisé

gabriel-robert, 2015-12-18:
Bonjour,

Je suis dans un logement équipé de radiateurs électriques récents, mais malheureusement non cablés avec un fil pilote. L'ancienneté des gaines ne me permet pas sans risques d'en faire passer un. Néanmoins je souhaite pouvoir les contrôler via leur entrée fil pilote ( soit un contrôleur par radiateur ).

J'ai actuellement pensé utiliser un arduino et son ESP8266 ( voir un Adafruit Feather Huzzah ) pour programmer la chauffe. Mon soucis est que je ne suis pas sûr de moi quand il s'agit de manipuler de telles tensions.

En regardant votre montage je me dit qu'il y a moyen de bricoler quelque chose de sympa à base d'optotriacs.

J'ai un doute sur la manière dont je devrais relier tout ça : prendre en dérivation l'arrivée 220v de mon radiateur et de le faire passer dans ce circuit? Avec une protection par fusible? Ne serait-ce pas plus simple pour moi d'utiliser un relais, voir un un double relais afin de gérer les 6 ordres?

Merci d'avance, et bravo pour ce montage très propre!

thibdct, 2016-01-01:
Bonjour,

Un NodeMCU par radiateur paraît peut-être surdimensionné. Néanmoins, il pourrait être sympa de créer un petit module spécifique. Basé sur la techno sans fil ULPNode par exemple. Bonne idée Charles @hallard ?

En attendant, as-tu pensé aux Qubino? (http://www.maison-et-domotique.com/50104-piloter-son-radiateur-electrique-fil-pilote-avec-un-module-z-wave-qubino-zmnhja2/)?

gabriel-robert, 2016-01-05:
C'est surdimensionné mais malheureusement, pas trop le choix.
Une autre solution, c'est le courant porteur, mais rien du tout pour les hobbyist... bien trop cher.

J'ai regardé les Qubino et consorts, mais la facture grimpe vite, car il faut également rajouter un boîtier de commande pour tout ça. L'avantage d'un module Wifi, au delà du coup dérisoire de nos jours, c'est que j'ai déjà du matériel qui tourne pour pouvoir le contrôler. Et ça rajoute un côté DIY qui m'intéresse vachement.

Le hic dans tout ça, c'est que je pars du principe que si je ne suis pas sûr de ce que je fais en touchant au 220v ( et à la sécurité de ma maison et de ses occupants ), je ne fais rien.

Ou sinon il me reste les WeMo switch avec un firmware cracké..

sosandroid, 2016-01-05:
Hello

Effectivement pas beaucoup de choix pour ce cas. Il faut déporter la
génération des signaux de fil pilote à partir de l'alim des radiateurs.

Le NodeMCU/Huzzah est un option wifi (attention lors d'un changement de
fournisseur d'accès. Il faudra tous les reprogrammer pour assurer la
connexion.
     - Avantage : on gère tout depuis le réseau TCP/IP
     - Aucun mode autonome puisque tout passe par le "serveur"

Une autre option est le Moteino qui fonctionne sur du 433 ou 868 MHz.
C'est donc hors Wifi. Il faut donc ajouter une "passerelle" ethernet
vers radio pour assurer le contrôle.
     - un mode autonome est possible puisque la "passerelle" peut
écouter et émettre. Les capteurs peuvent donc lui parler directement
     - en cas de panne wifi, cela continue donc à fonctionner et c'est
indépendant du provider de box (ethernet)
     - Un peu plus cher à mettre en oeuvre

Pour le 230v, cela se manipule avec des optitriacs ou des relais comme
Remora. Faut juste un boitier correct pour mettre tout cela en sécurité
et un fusible en entrée de 0,5A (largement suffisant normalement)

gabriel-robert, 2016-01-07:
Merci pour les conseils. Je vais regarder de près les schematics et me lancer !
Je vous tiendrais au courant du montage.

frco9, 2016-01-24:
Bonjour
Je suis également très intéressé par un montage décentralisé, avez-vous pu avancer sur le sujet @gabriel-robert  ?

gabriel-robert, 2016-01-27:
Bonjour @frco9
Non pas pour le moment, le temps de faire des travaux d'isolation plus urgents! Je me penche plus sérieusement sur le sujet courant février, je ne manquerais pas de vous tenir au courant!

Closed 2016-01-07.

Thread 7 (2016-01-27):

Mesure de la consommation électrique

GrmpCerber, 2016-01-27:
Petite idée d'amélioration : mesurer la consommation électrique du circuit du cumulus.

Autre amélioration possible, mais qui nécessiterai une évolution majeure du câblage, mesurer la consommation électrique des 7 lignes dédiées au chauffage (ce qui nécessiterai donc de brancher leurs phases en plus de leur FP.

fab33, 2016-05-26:
Peu utile à mon avis. Une carte openenergymonitor (emontx ou shield) permet de faire cela. De plus pour parler de mon cas je n'ai que 3 départs de chauffage pour 5 radiateurs.

Azema, 2016-05-27:
Salut @GrmpCerber,

En tant qu'électricien professionnel, je conseille de ne pas brancher directement le cumulus sur le relais de la carte Remora. Il vaut mieux passer par un contacteur modulaire.

Pour la consommation, tu as déjà la puissance apparente remontée par la télé-information (PAPP). Sinon, pour permettre de remonter les consommations pour chaque zone, ainsi que pour le relais, je pense que le mieux serait de pouvoir renseigner la puissance de chacun. Ensuite, il serait possible de retourner la consommation instantanée.
Mais le Remora ne dispose pas de mémoire pour stocker des informations, du moins pas pour des écritures répétées.

hallard, 2016-05-27:
Ah oui je confirme le relais de la carte c'est pas fait pour piloter les grosses charges genre cumulus, sinon il va pas aimer !!!!

fab33, 2016-05-27:
D'une part il ne va pas aimer et d'autre part il faut tout de même s'assurer de la présence d'un disjoncteur adapté sur la ligne. Le contacteur me semble obligatoire. Il faudrait ajouter un schéma de câblage car j'ai l'impression que l'erreur est courante.

Azema, 2016-05-28:
Allez, parce que vous êtes sympa, je vous ai fait un joli petit dessin :-)

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

GrmpCerber, 2016-05-28:
Bonjour à tous et merci de vos réponses !

Un peu de contexte : mon chauffe eau est un 1650W et mon installation de chauffage est électrique.
Donc utiliser la PAPP ne m'est pas d'un grand secours quand les chauffages sont en marche, d'où ma question sur une mesure de conso.
Concernant la carte openenergymonitor elle est relativement chère, se base sur des pinces qui fournissent une mesure grossière et ... elle m'oblige à "éventrer" mon tableau électrique pour glisser les pinces au milieu des cables.
Pour ma part je penchais plus vers un composant (ou un ensemble de composant) tel le [LTC2945](http://cds.linear.com/docs/en/datasheet/2945fb.pdf) qui permet de récupérer en I²C la conso d'un circuit ... 80V :( (je n'ai pas trouvé d'équivalent 250V et je n'arrive pas à trouver la puissance max tolérée par le LTC2945)

Concernant la présence d'un disjoncteur adapté (== dont la puissance max est inférieure à la capacité du circuit), je n'aurais pas fait sans ;)
Maintenant sur le circuit, 1650W=6.6A sous 250VAC et, si je ne me trompe pas ( @Azema ? ), 7.7A sous 220VAC (pire hypothèse).
Donc pour être en sécurité j'ajoute 10% ==> il me faut un circuit qui "coupe" à 8.5A.
Concernant le disjoncteur adapté ça va être difficile de trouver du 8.5A donc je pousse ma marge de sécurité à 10A.
La BOM pointe un relais [Omron](http://www.conrad.fr/ce/fr/product/503893/Relais-pour-circuits-imprims-Omron-G6D-1A-ASI-5DC-5-VDC-5-A-1-NO-T-1-pcs/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;43857;390&gclid=CjwKEAjwg6W6BRDn6v__7vzN9QkSJAC9l9C3PRAhiMjyKMdZ8HqBF9BJZ8oLUpdnkEX7JNu56MmZBxoCv8Pw_wcB) dont le maximum est 5A, ce n'est donc pas un bon candidat.
D'après le schéma du Remora (et c'est peut être là la source d'erreur de lecture) la board supporte un autre type de relai : le [HLS8L-DC5V-S-C](http://www.seeedstudio.com/depot/images/opl/datasheet/315030000.pdf) qui lui tolère les 10A.

NB je suis embêté par le manque de marge de sécurité entre les 10A du disjoncteur et les 10A du relais. Ma seule "sécurité" est donc le wattage max de mon cumulus actuel...
@Azema @hallard Y-a-t-il une erreur dans mon raisonnement ? cette solution est-elle viable ?

Azema, 2016-05-28:
As-tu déjà un contacteur jour/nuit dans ton tableau électrique, car tu peux le piloter avec le relais.
Pour le calibrage du disjoncteur, tu es bon avec un 10A.
Le Remora est la partie commande du système, pas la partie puissance. C'est pourquoi il faut passer par un contacteur. Cela permettra de ne pas fragiliser ton relais, car le cumulus va tirer dur et pendant un long moment.

fab33, 2016-05-28:
le pinces de mesure de courant ne sont pas imprécise mais au contraire très précises après calibration (à peine 2% par rapport au compteur). On trouve des sketch qui font même la différence entre puissance active/réactive et qui font du monitoring continu et non pas échantillonnage. Concernant le prix, le shield pour UNO ne coute que 11 livres ce qui ne me semble pas excessif. En prenant les pinces dur aliexpress on doit s'en sortir à un prix correct.
Pour le reste, laisser 7A dans un relais 10A pendant plusieurs heures, c'est pas top. Enfin sur le schéma il faut rajouter un disjoncteur 2A pour protéger le circuit de commande de la bobine et non pas la reprendre sur le 16A

Azema, 2016-05-28:
Effectivement, tu as raison @fab33, mais j'étais un peu flemmard ce matin, car c'est ce que je fais dans mes tableaux.

fab33, 2016-05-28:
tip top. Voila un bon schéma de référence !

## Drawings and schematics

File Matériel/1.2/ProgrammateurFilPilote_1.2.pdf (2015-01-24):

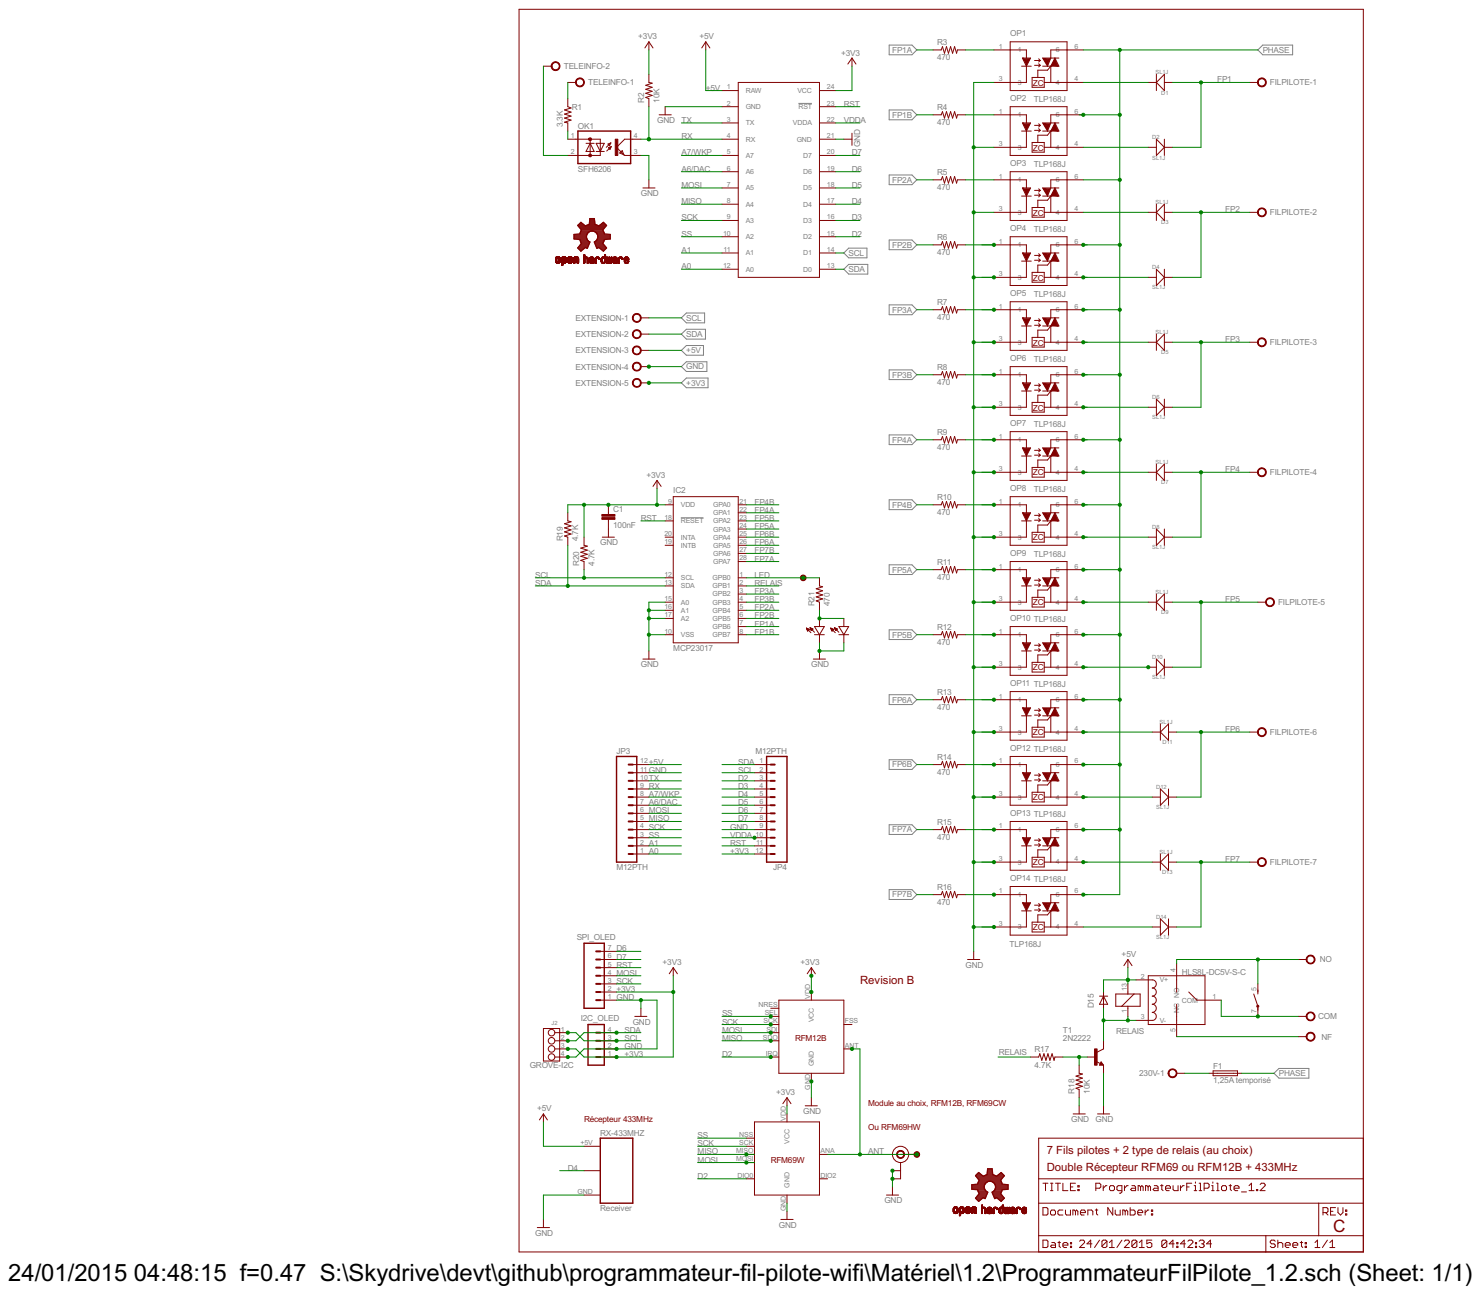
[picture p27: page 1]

EXTENSION-1 EXTENSION-2 EXTENSION-3 EXTENSION-4 EXTENSION-5

MISO MOSI SCK NSS

7 Fils pilotes + 2 type de relais (au choix)

24/01/2015 04:48:15 f=0.47 S:\Skydrive\devt\github\programmateur-fil-pilote-wifi\Matériel\1.2\ProgrammateurFilPilote_1.2.sch (Sheet: 1/1)

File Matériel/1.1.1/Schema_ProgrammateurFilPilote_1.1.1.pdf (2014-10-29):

OP11

OP21

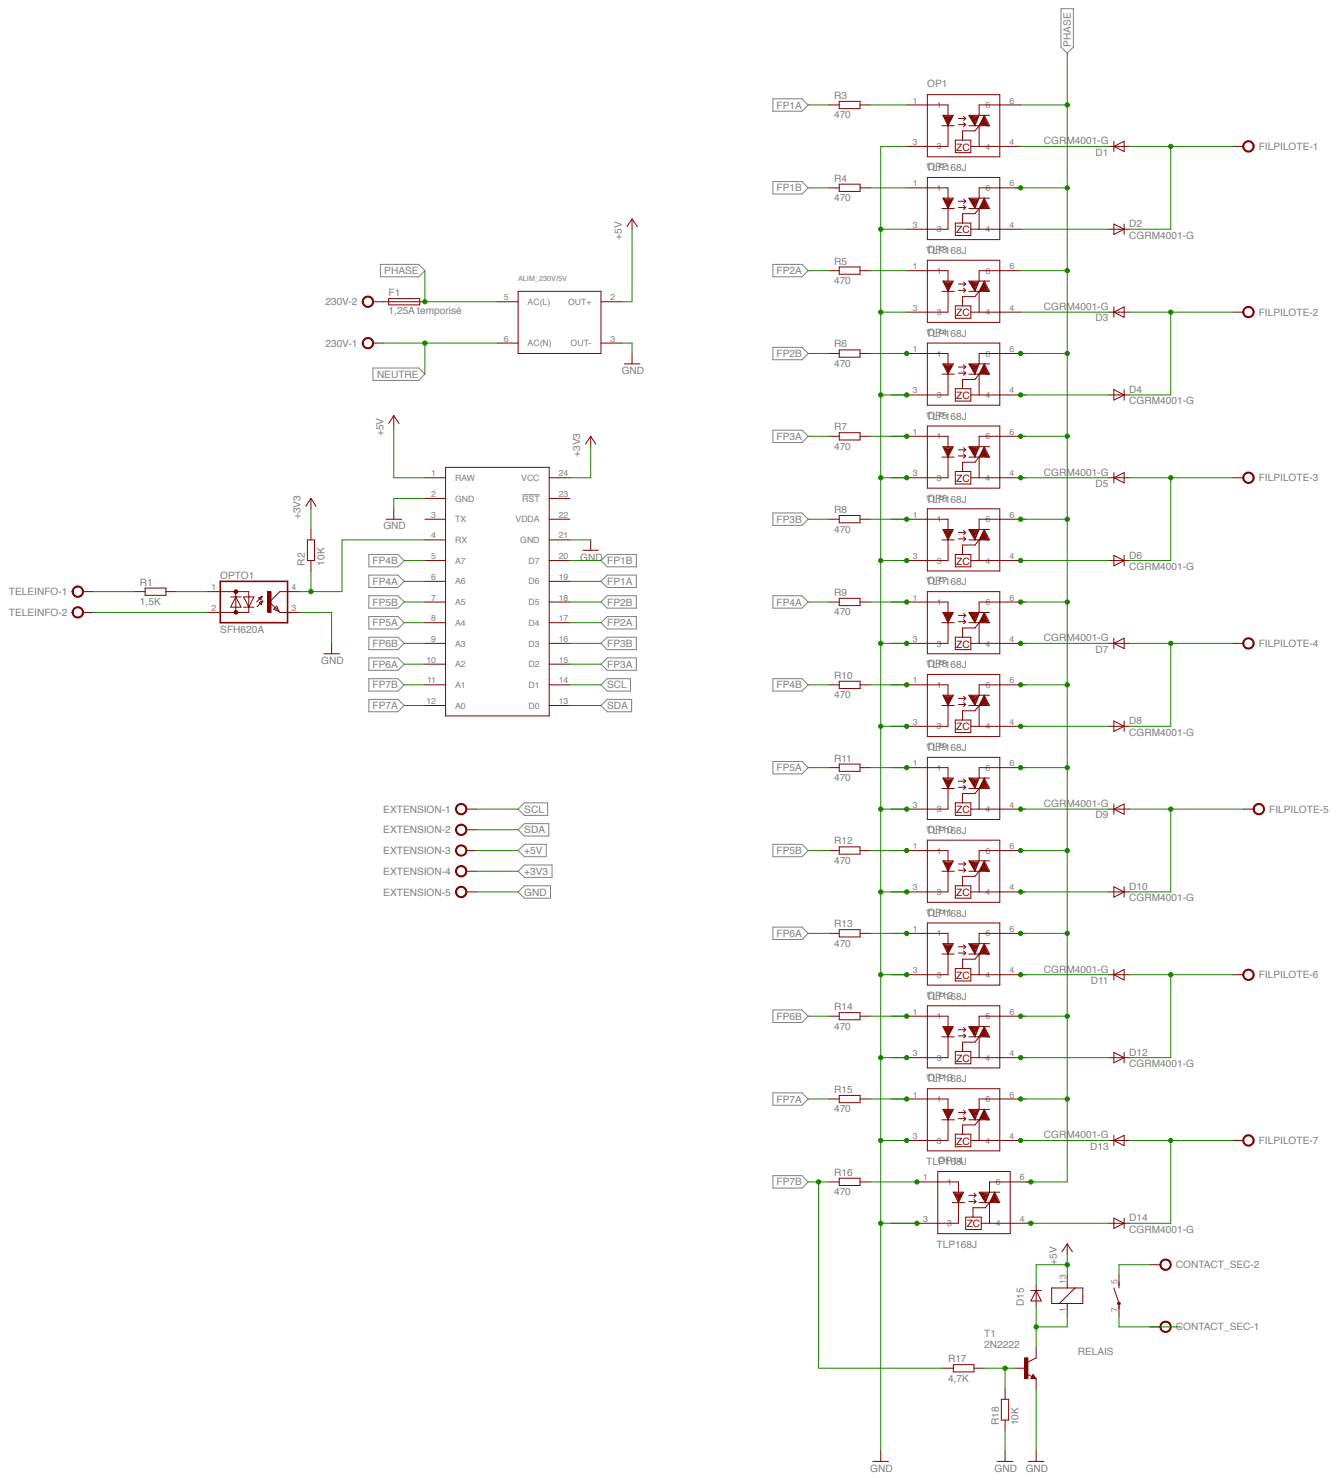
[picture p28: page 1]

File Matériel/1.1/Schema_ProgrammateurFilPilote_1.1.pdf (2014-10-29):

OP11

OP21

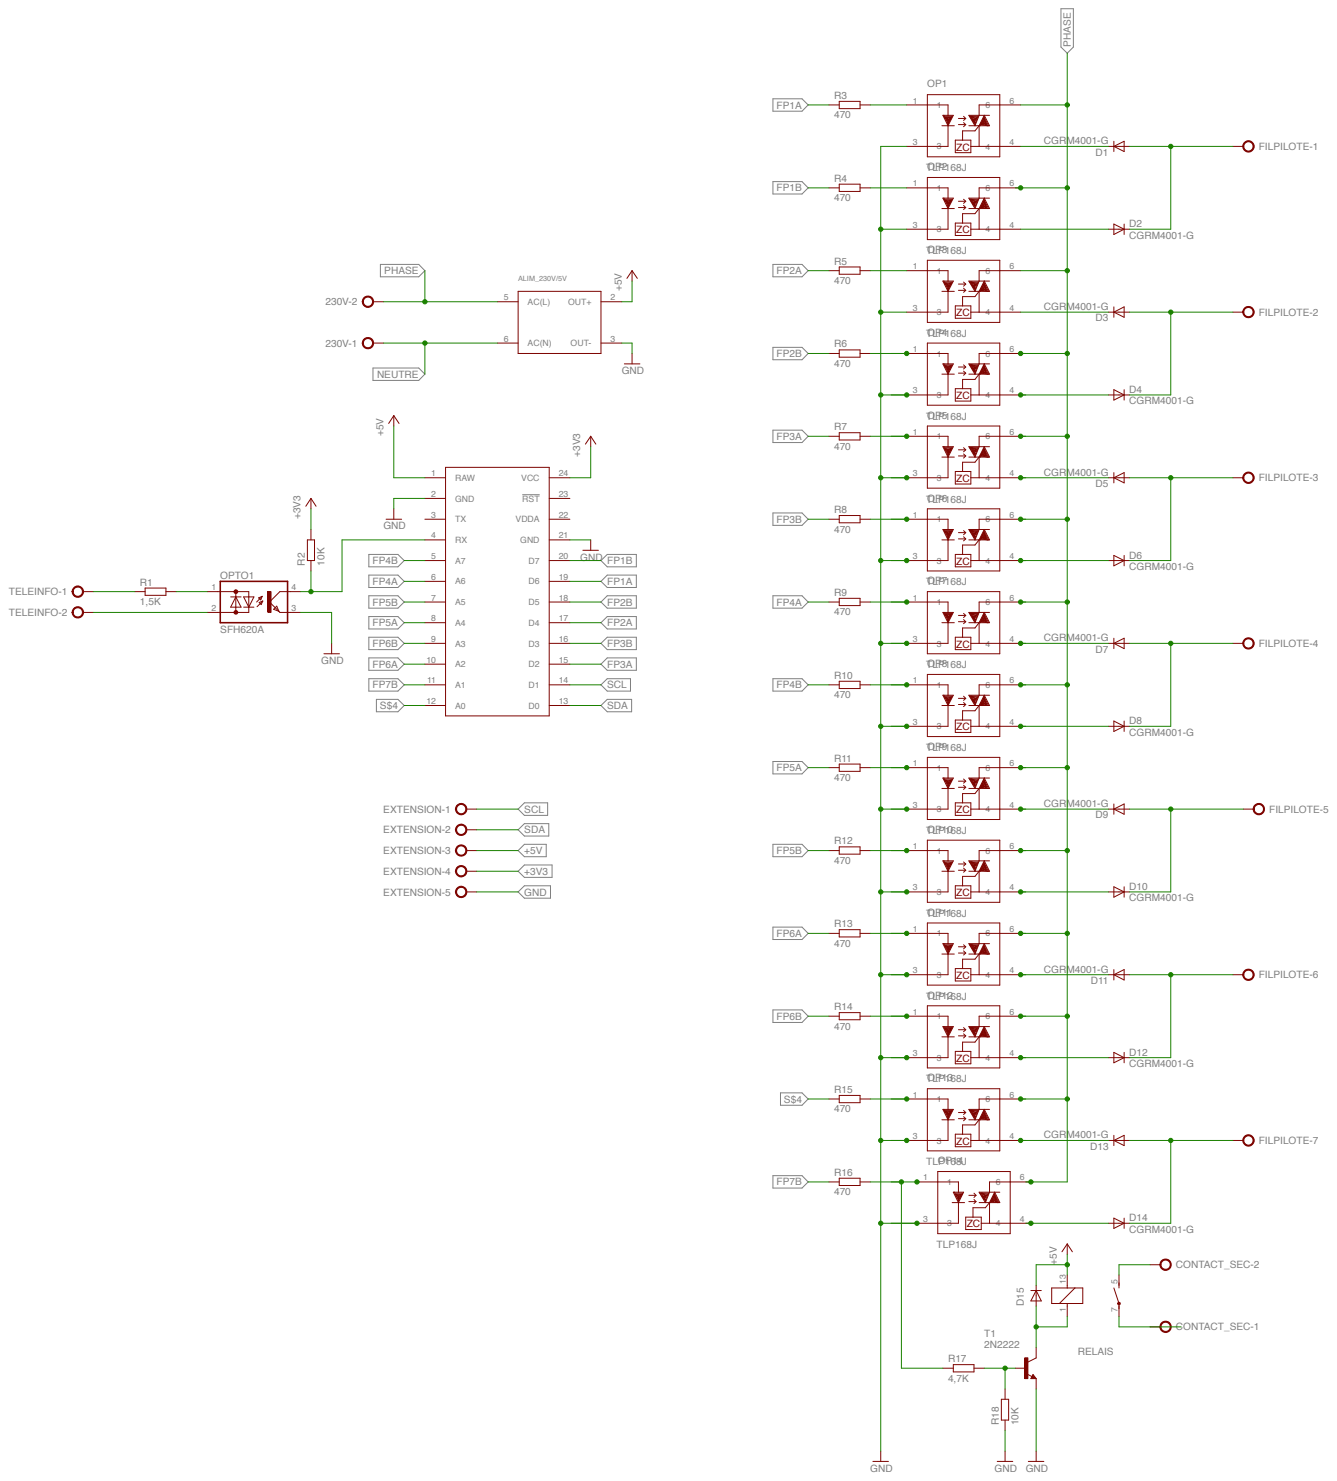
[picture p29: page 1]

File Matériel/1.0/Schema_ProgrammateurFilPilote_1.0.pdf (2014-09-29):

OP11

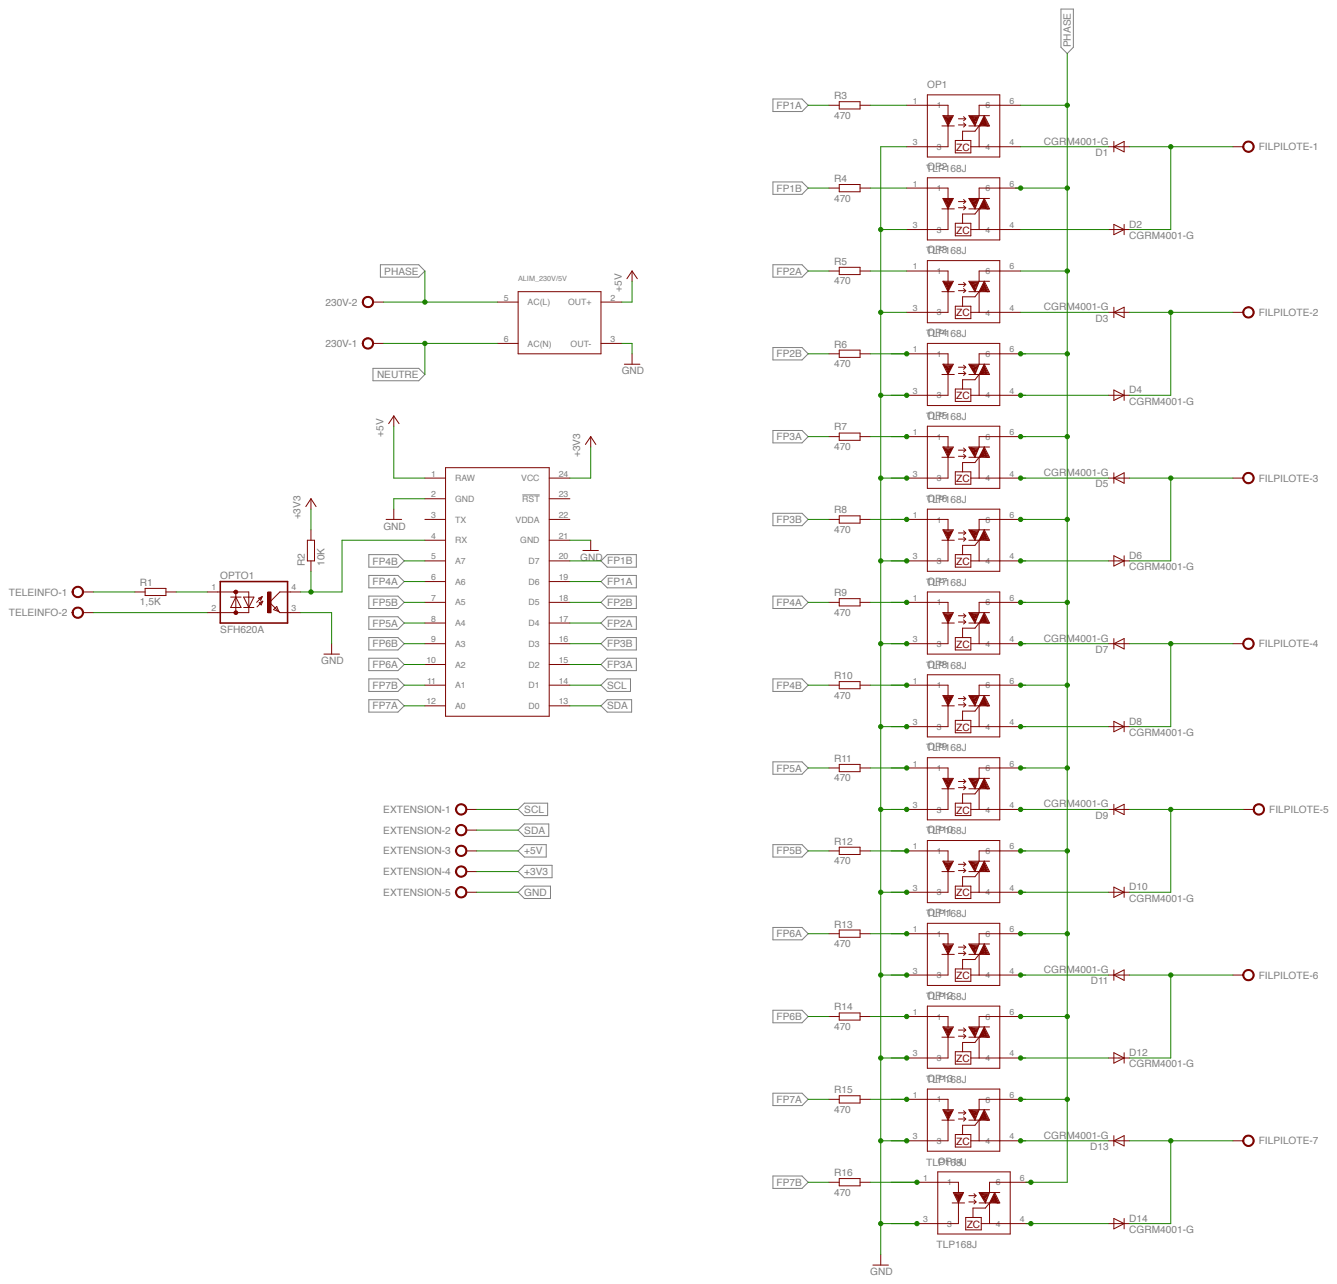
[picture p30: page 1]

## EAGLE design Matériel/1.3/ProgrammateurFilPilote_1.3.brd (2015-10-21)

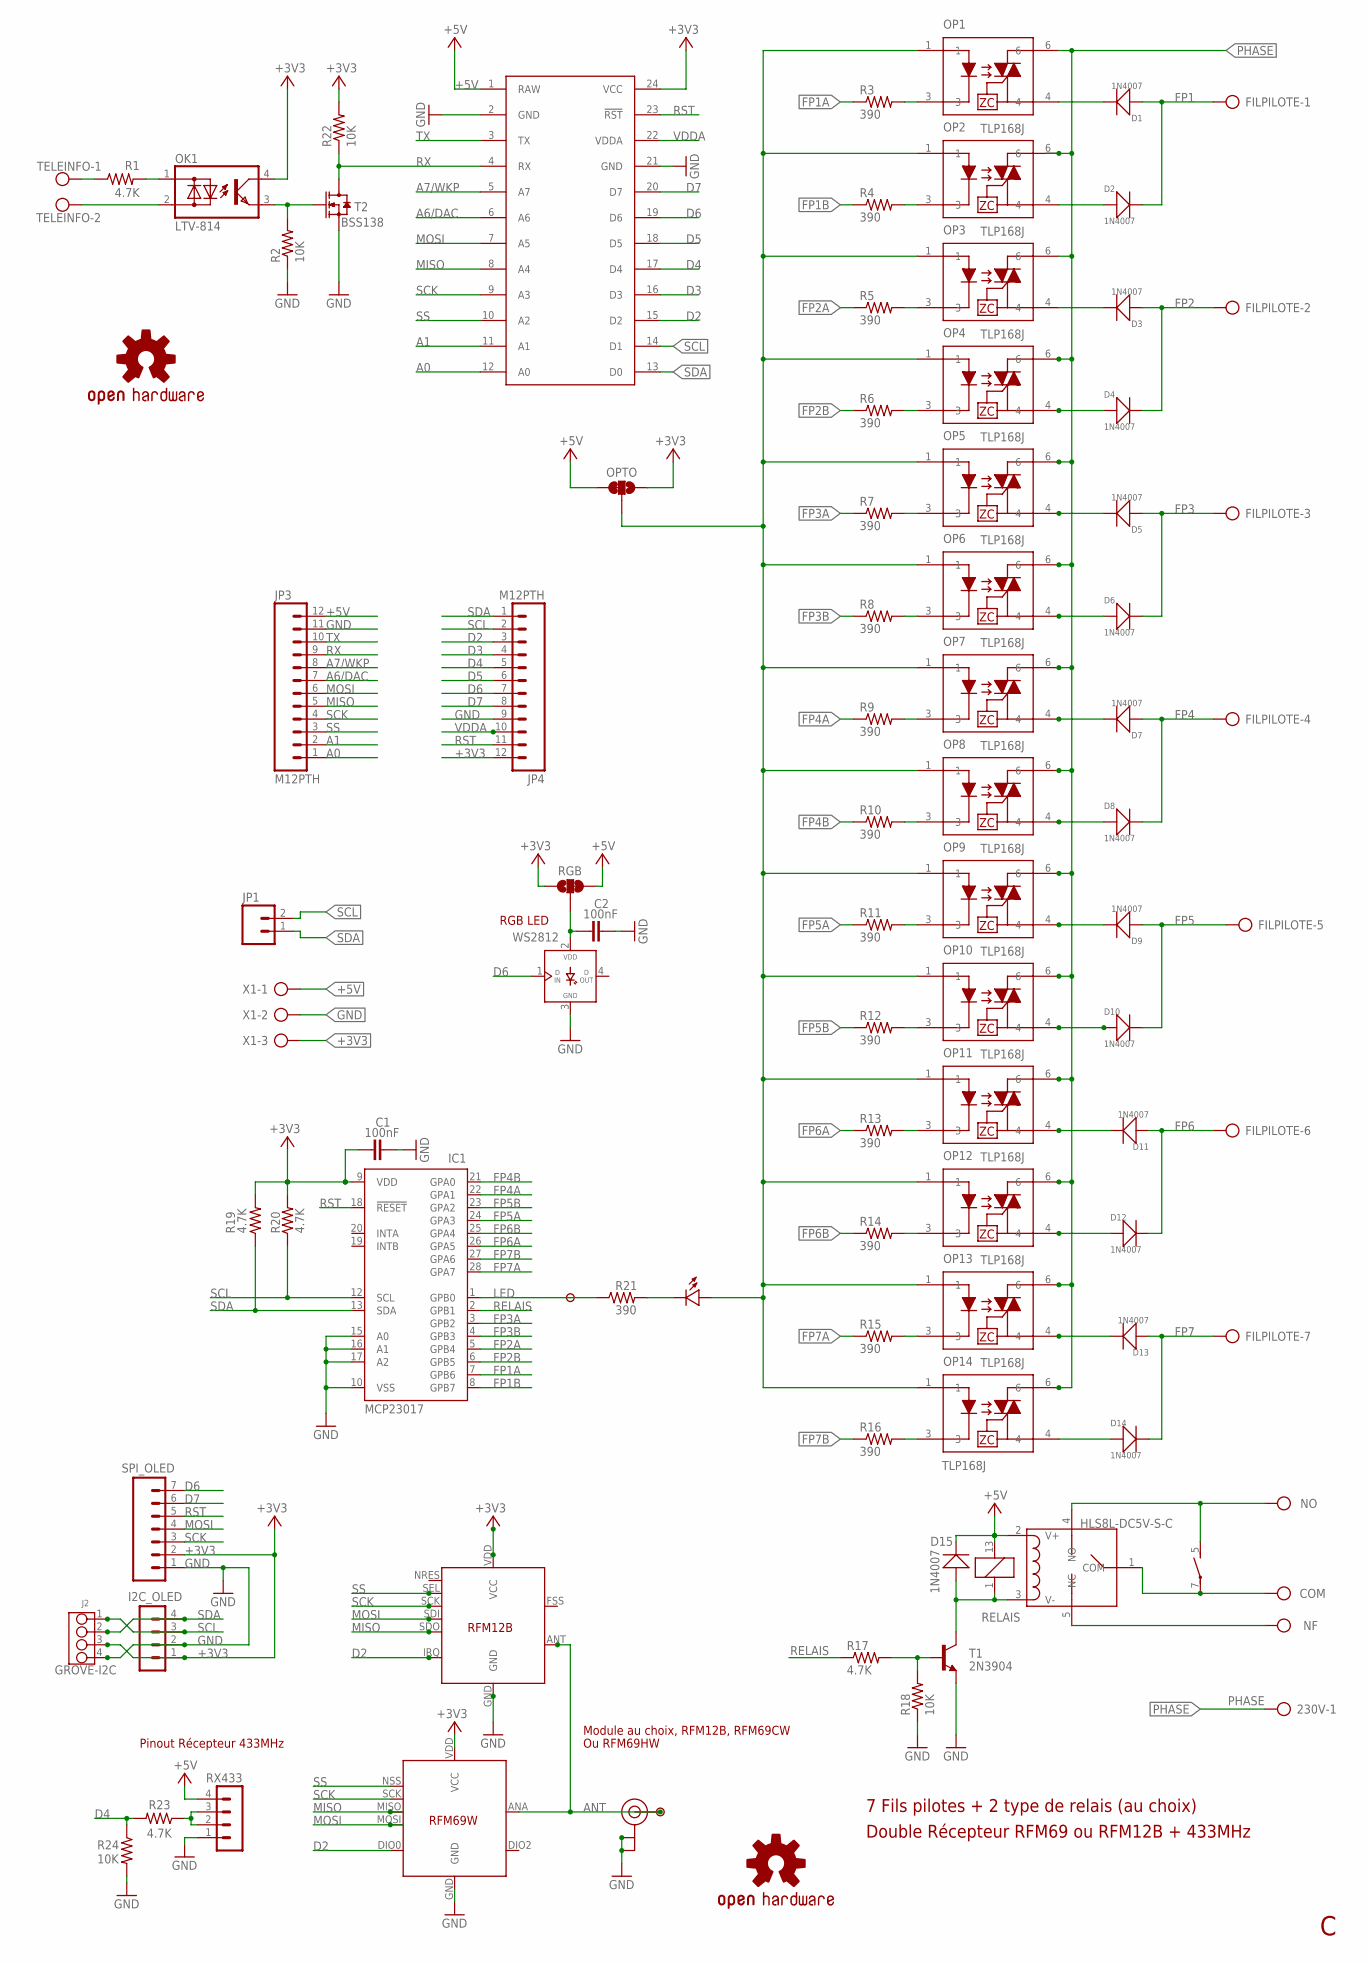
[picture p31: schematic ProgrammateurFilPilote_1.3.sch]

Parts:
230V: AK500/2
C1, C2: 100nF; 1206-CAP
D1, D2, D3, D4, D5, D6, D7, D8, D9, D10, D11, D12, D13, D14, D15: 1N4007; DO-214AC
FILPILOTE: AK500/7
I2C_OLED: CON_HEADER_1X04'SMALL''; M1X4
IC1: MCP23017; DIL28-3
J2: GROVE-I2C; 4P-2.0
JP1: M02PTH; 1X02
JP3, JP4: M12PTH; 1X12-SMALL-PADS
LED: LED3MM
LOGO1, LOGO2: OSHW-LOGOL; OSHW-LOGO-L
OK1: LTV-814; DIL4-SMD
OP1, OP2, OP3, OP4, OP5, OP6, OP7, OP8, OP9, OP10, OP11, OP12, OP13, OP14: TLP168J; MFSOP-4-HANDSOLDER
OPTO: JUMPER-PAD-3-2OF3_NC_BY_TRACE_LARGE; PAD-JUMPER-3-2OF3_NC_BY_TRACE_YES_SILK_LARGE
P1, P2: PADSMALL; PAD-SMALL
PARTICLE: Spark/Photon; SPARK_CORE
R1, R17, R19, R20, R23: 4.7K; 1206-RES
R2, R18, R22, R24: 10K; 1206-RES
R3, R4, R5, R6, R7, R8, R9, R10, R11, R12, R13, R14, R15, R16, R21: 390; 1206-RES
RELAIS: Relais G6D; G6D
RGB: JUMPER-PAD-3-2OF3_NC_BY_TRACE_SMALL; PAD-JUMPER-3-2OF3_NC_BY_TRACE_YES_SILK_FULL_BOX
RL: AK500/2
RX433: CON_HEADER_1X04'NO_LOCK'; 1X04_NO_LOCK
SPI_OLED: CON_HEADER_1X07'SMALL'; M1X7
SW1: HLS8L-DC5V-S-C; 5P-L19.0XW15.0XH15.0MM
T1: 2N3904; TO92-EBC
T2: BSS138; SOT23
TELEINFO: AK500/2
U$2: RFM12B; RFM12B-MINPADS
U$3: RFM69W; RFM69W-MINPADS
U-FL: U.FL
WS2812: RGB LED; WS2812-PTH
X1: AK500/3

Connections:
+3V3: C1.1, I2C_OLED.1, IC1.9 (VDD), J2.3, JP4.12, OK1.4 (C), OPTO.1, PARTICLE.24 (VCC), R19.2, R20.2, R22.2, RGB.1, SPI_OLED.2, U$2.VDD (VCC), U$3.VDD (VCC), X1.3
+5V: D15.2 (-), JP3.12, OPTO.3, PARTICLE.1 (RAW), RELAIS.13 (2), RGB.3, RX433.4, SW1.2 (V+), X1.1
A0: JP3.1, PARTICLE.12 (A0)
A1: JP3.2, PARTICLE.11 (A1)
A6/DAC: JP3.7, PARTICLE.6 (A6)
A7/WKP: JP3.8, PARTICLE.5 (A7)
ANT: P1.1, U$2.ANT, U$3.ANA (ANT), U-FL.3 (SIGNAL)
COM: RELAIS.7, RL.1, SW1.1 (COM)
D2: JP4.3, PARTICLE.15 (D2), U$2.IRQ, U$3.DIO0
D3: JP4.4, PARTICLE.16 (D3)
D4: JP4.5, PARTICLE.17 (D4), R23.2, R24.1
D5: JP4.6, PARTICLE.18 (D5)
D6: JP4.7, PARTICLE.19 (D6), SPI_OLED.7, WS2812.1 (DIN)
D7: JP4.8, PARTICLE.20 (D7), SPI_OLED.6
FP1: D1.1 (+), D2.2 (-), FILPILOTE.1
FP1A: IC1.7 (GPB6), R3.1
FP1B: IC1.8 (GPB7), R4.1
FP2: D3.1 (+), D4.2 (-), FILPILOTE.2
FP2A: IC1.5 (GPB4), R5.1
FP2B: IC1.6 (GPB5), R6.1
FP3: D5.1 (+), D6.2 (-), FILPILOTE.3
FP3A: IC1.3 (GPB2), R7.1
FP3B: IC1.4 (GPB3), R8.1
FP4: D7.1 (+), D8.2 (-), FILPILOTE.4
FP4A: IC1.22 (GPA1), R9.1
FP4B: IC1.21 (GPA0), R10.1
FP5: D9.1 (+), D10.2 (-), FILPILOTE.5
FP5A: IC1.24 (GPA3), R11.1
FP5B: IC1.23 (GPA2), R12.1
FP6: D11.1 (+), D12.2 (-), FILPILOTE.6
FP6A: IC1.26 (GPA5), R13.1
FP6B: IC1.25 (GPA4), R14.1
FP7: D13.1 (+), D14.2 (-), FILPILOTE.7
FP7A: IC1.28 (GPA7), R15.1
FP7B: IC1.27 (GPA6), R16.1
GND: C1.2, C2.2, I2C_OLED.2, IC1.10 (VSS), IC1.15 (A0), IC1.16 (A1), IC1.17 (A2), J2.4, JP3.11, JP4.9, PARTICLE.2 (GND), PARTICLE.21 (GND), R2.1, R18.1, R24.2, RX433.1, SPI_OLED.1, T1.E, T2.2 (S), U$2.GND, U$3.GND, U-FL.1 (GND), U-FL.2 (GND), WS2812.3 (GND), X1.2
LED: IC1.1 (GPB0), P2.1, R21.1
MISO: JP3.5, PARTICLE.8 (A4), U$2.SDO, U$3.MISO
MOSI: JP3.6, PARTICLE.7 (A5), SPI_OLED.4, U$2.SDI, U$3.MOSI
unnamed: D1.2 (-), OP1.4
unnamed: D2.1 (+), OP2.4
unnamed: OK1.2 (AC2), TELEINFO.2
unnamed: OK1.1 (AC1), R1.2
unnamed: R1.1, TELEINFO.1
unnamed: LED.MINUS, R21.2
unnamed: OP1.3, R3.2
unnamed: OP2.3, R4.2
unnamed: OP3.3, R5.2
unnamed: OP4.3, R6.2
unnamed: OP5.3, R7.2
unnamed: OP6.3, R8.2
unnamed: OP7.3, R9.2
unnamed: OP8.3, R10.2
unnamed: D15.1 (+), RELAIS.1, SW1.3 (V-), T1.C
unnamed: C2.1, RGB.2, WS2812.2 (VDD)
unnamed: OK1.3 (E), R2.2, T2.1 (G)
unnamed: OP9.3, R11.2
unnamed: LED.PLUS, OP1.1, OP2.1, OP3.1, OP4.1, OP5.1, OP6.1, OP7.1, OP8.1, OP9.1, OP10.1, OP11.1, OP12.1, OP13.1, OP14.1, OPTO.2
unnamed: R17.2, R18.2, T1.B
unnamed: D3.2 (-), OP3.4
unnamed: D5.2 (-), OP5.4
unnamed: D4.1 (+), OP4.4
unnamed: D7.2 (-), OP7.4
unnamed: D6.1 (+), OP6.4
unnamed: D8.1 (+), OP8.4
unnamed: OP10.3, R12.2
unnamed: OP14.3, R16.2
unnamed: D9.2 (-), OP9.4
unnamed: OP11.3, R13.2
unnamed: OP12.3, R14.2
unnamed: D10.1 (+), OP10.4
unnamed: D12.1 (+), OP12.4
NF: RL.2, SW1.5 (NC)
NO: 230V.2, RELAIS.5 (S), SW1.4 (NO)
PHASE: 230V.1, OP1.6, OP2.6, OP3.6, OP4.6, OP5.6, OP6.6, OP7.6, OP8.6, OP9.6, OP10.6, OP11.6, OP12.6, OP13.6, OP14.6
RELAIS: IC1.2 (GPB1), R17.1
RST: IC1.18 (!RESET), JP4.11, PARTICLE.23 (!RST), SPI_OLED.5
RX: JP3.9, PARTICLE.4 (RX), R22.1, T2.3 (D)
RX433: R23.1, RX433.2, RX433.3
S$1: D11.2 (-), OP11.4
S$3: D13.2 (-), OP13.4
S$5: OP13.3, R15.2
S$11: D14.1 (+), OP14.4
SCK: JP3.4, PARTICLE.9 (A3), SPI_OLED.3, U$2.SCK, U$3.SCK
SCL: I2C_OLED.3, IC1.12 (SCL), J2.1, JP1.2, JP4.2, PARTICLE.14 (D1), R20.1
SDA: I2C_OLED.4, IC1.13 (SDA), J2.2, JP1.1, JP4.1, PARTICLE.13 (D0), R19.1
SS: JP3.3, PARTICLE.10 (A2), U$2.SEL, U$3.NSS (SEL)
TX: JP3.10, PARTICLE.3 (TX)
VDDA: JP4.10, PARTICLE.22 (VDDA)

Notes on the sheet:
7 Fils pilotes + 2 type de relais (au choix)
Module au choix, RFM12B, RFM69CW
Ou RFM69HW
Pinout Récepteur 433MHz
Double Récepteur RFM69 ou RFM12B + 433MHz
RGB LED

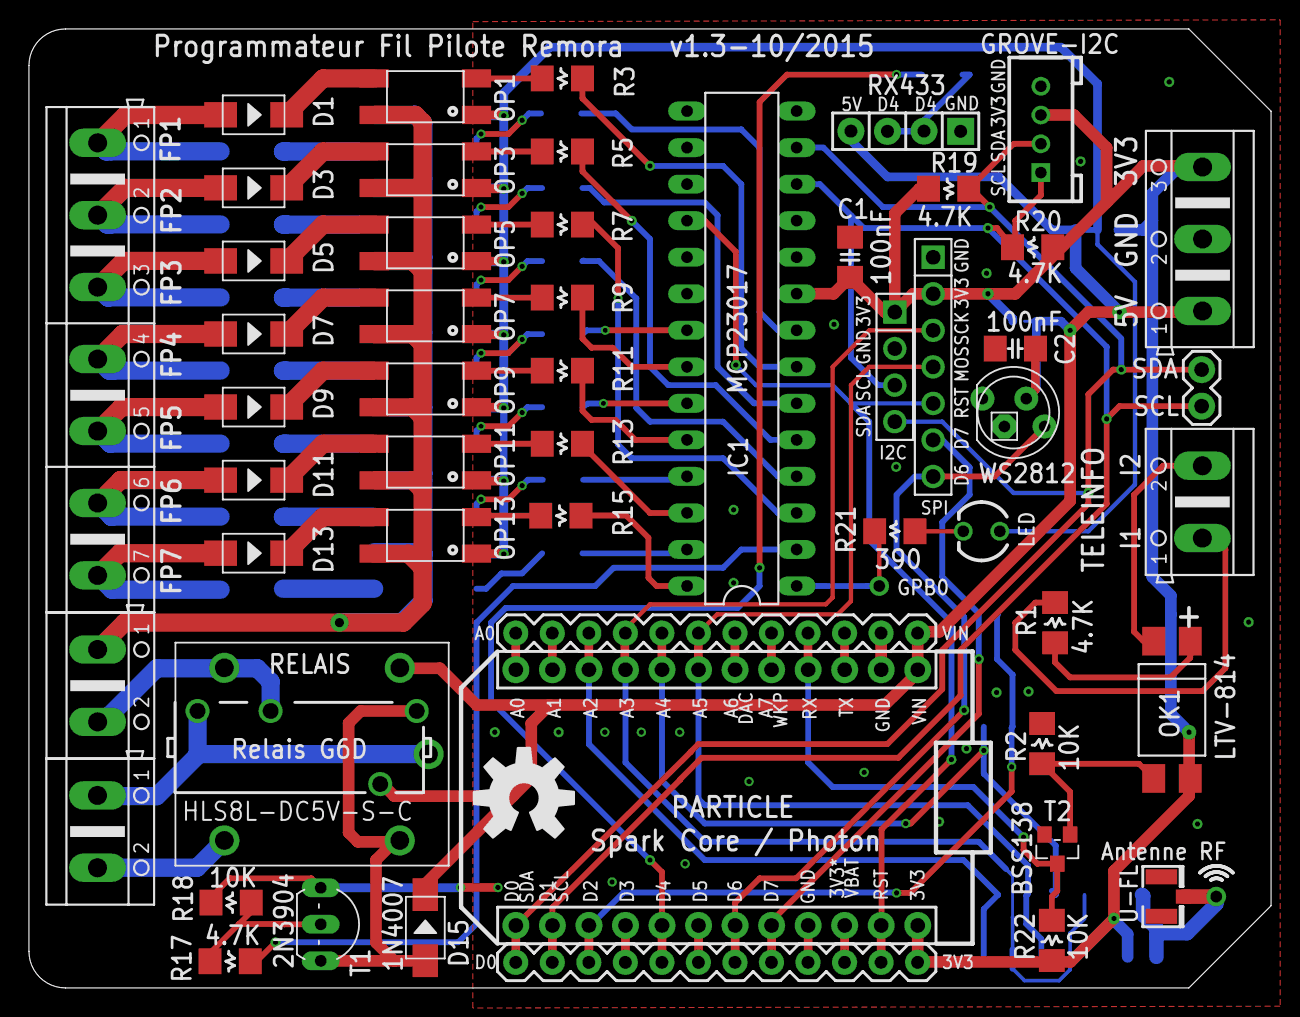
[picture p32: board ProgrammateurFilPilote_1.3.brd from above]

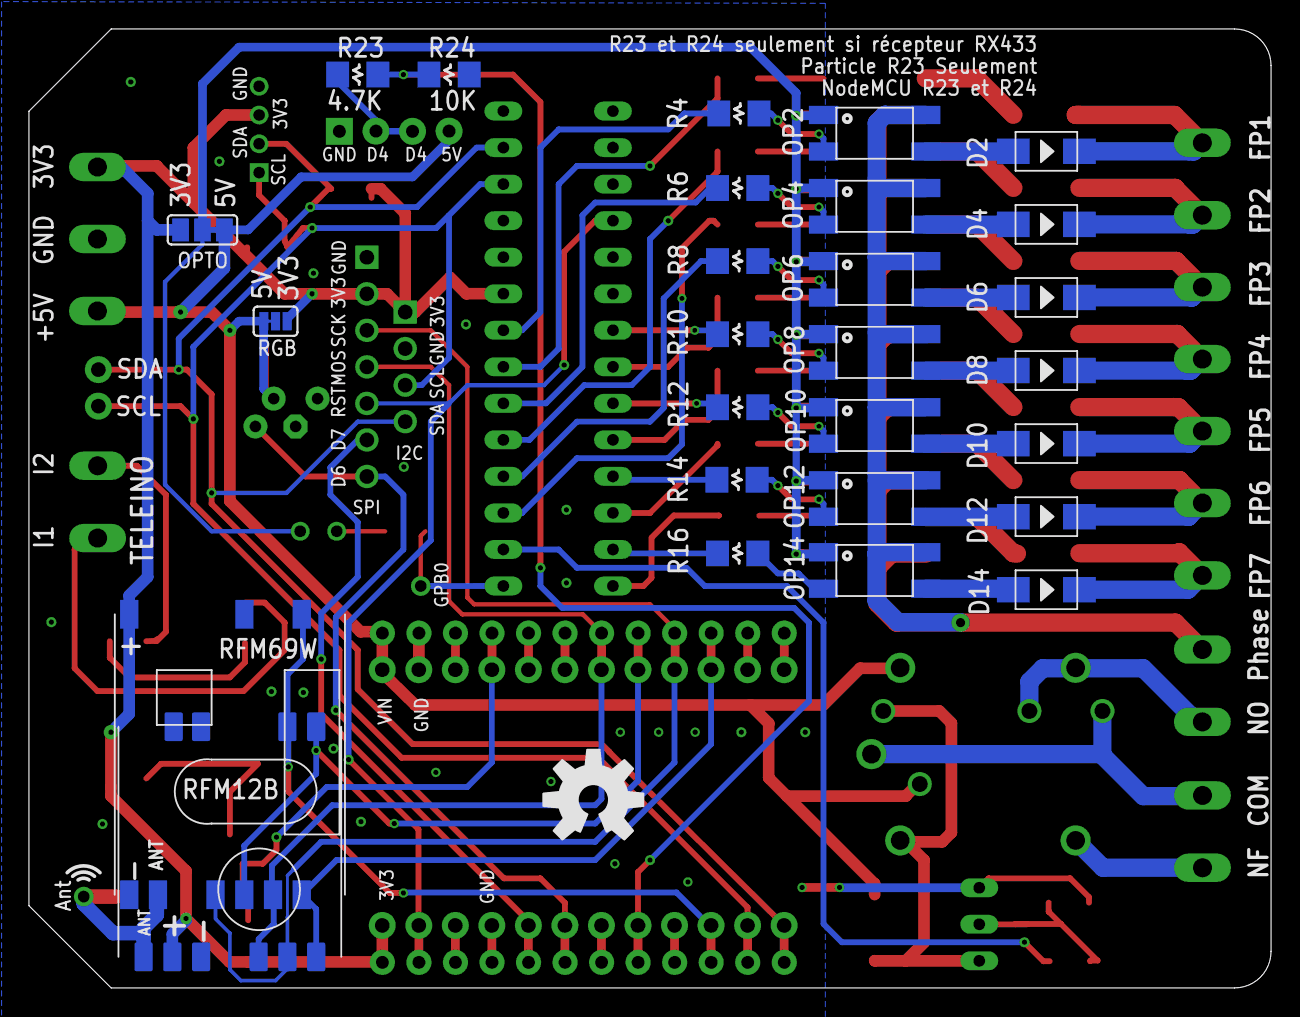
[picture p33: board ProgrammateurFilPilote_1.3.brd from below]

Board: 2 copper layers, 86.4 x 66.7 mm, 85 parts (28 on the bottom side), 89 nets.

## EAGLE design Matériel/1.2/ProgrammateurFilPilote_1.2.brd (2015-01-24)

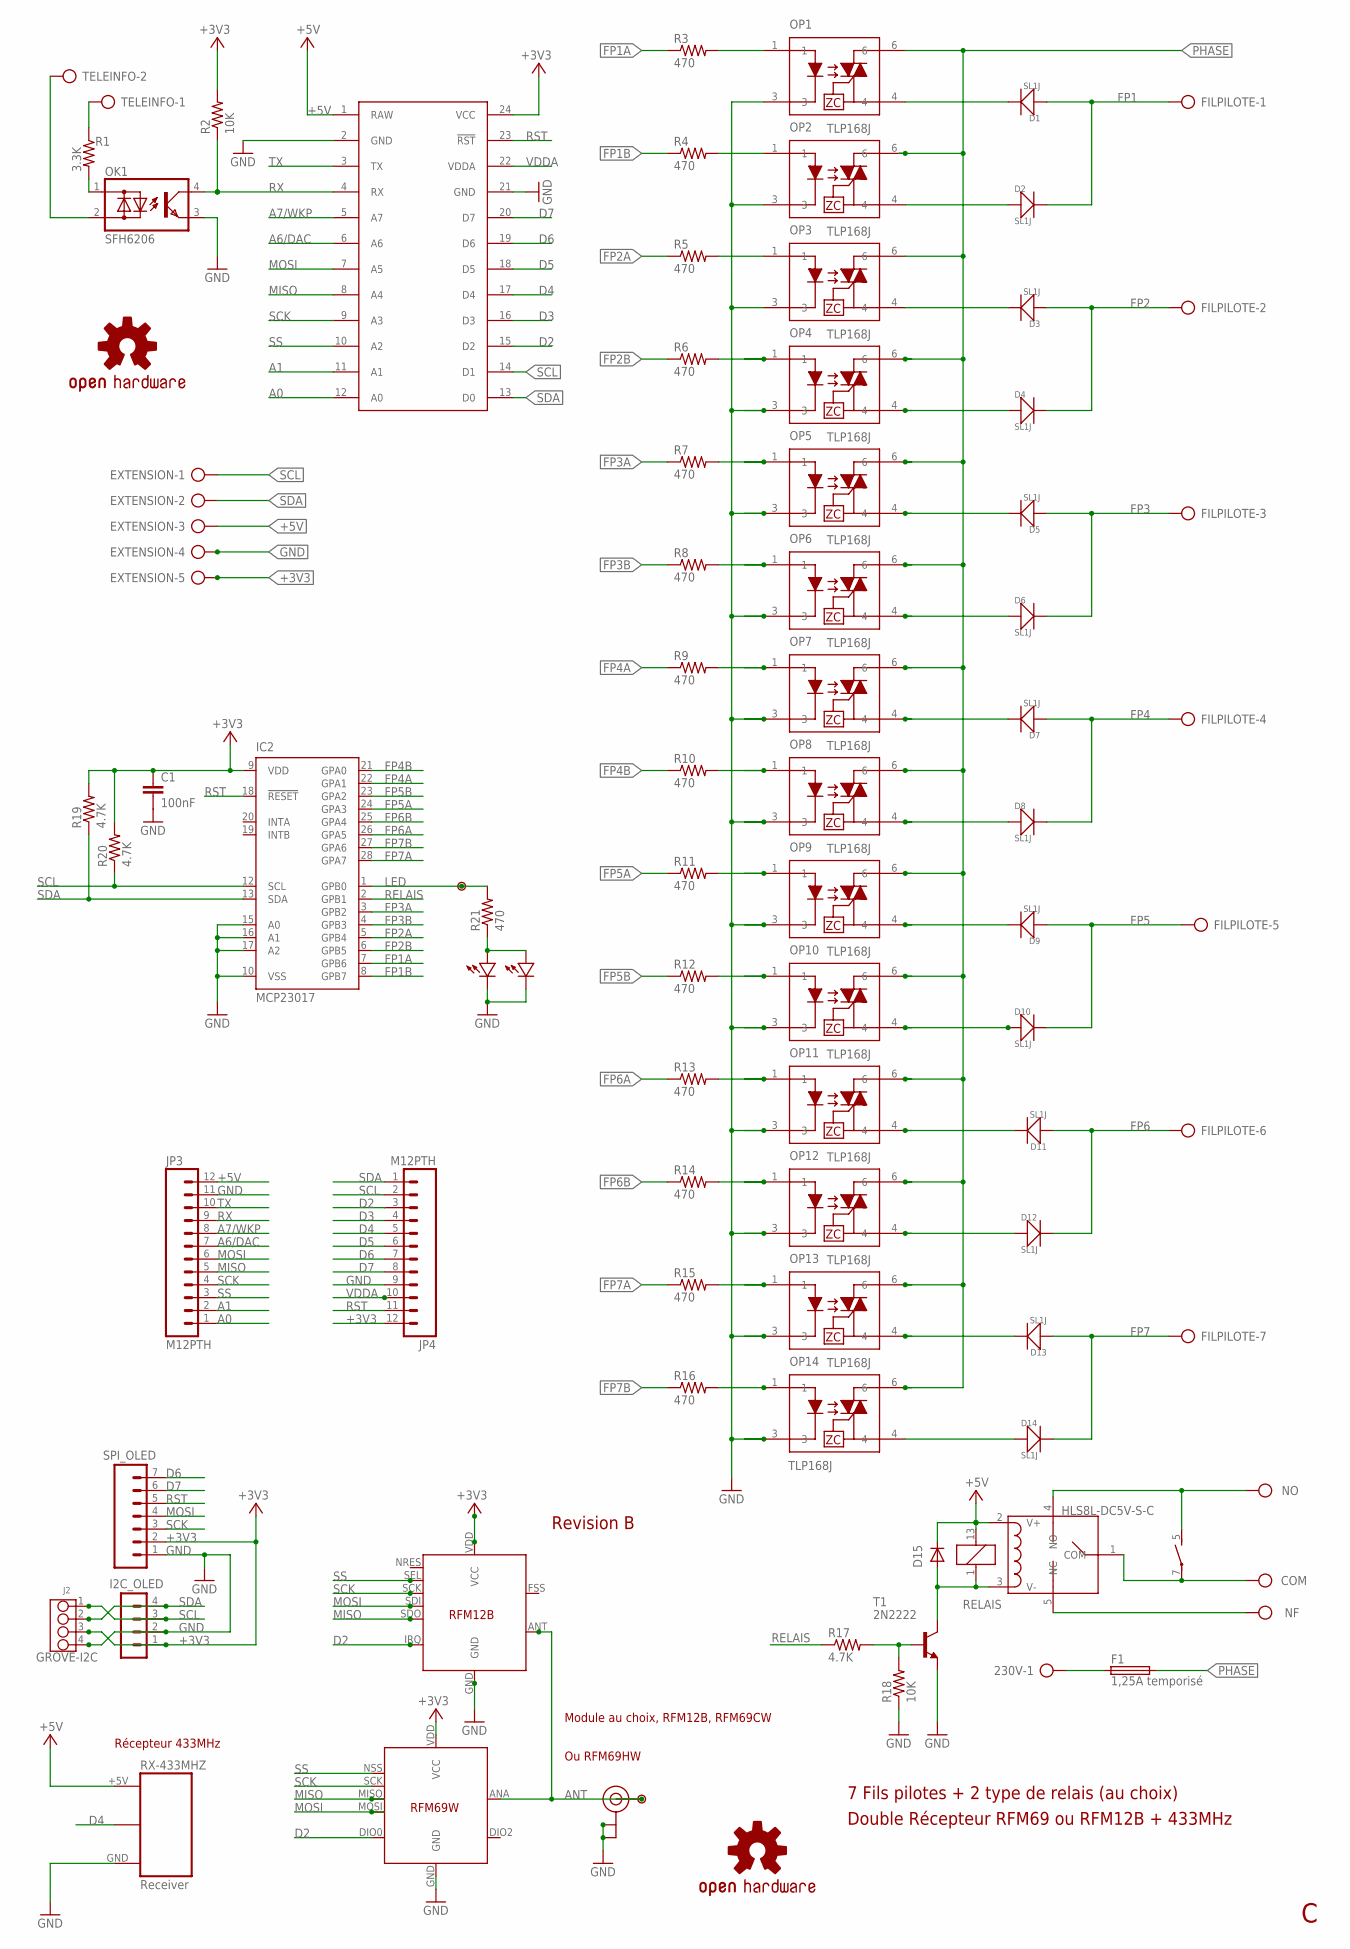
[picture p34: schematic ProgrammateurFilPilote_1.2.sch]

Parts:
230V: AK500/2
C1: 100nF; 1206-CAP
D1, D2, D3, D4, D5, D6, D7, D8, D9, D10, D11, D12, D13, D14: SL1J; DO-214AC
D15: CGRM4001-G; SOD-123_MINI-SMA
EXTENSION: AK500/5
F1: 1,25A temporisé; TE5
FILPILOTE: AK500/7
I2C_OLED: CON_HEADER_1X04'SMALL''; M1X4
IC2: MCP23017; DIL28-3
J2: GROVE-I2C; 4P-2.0
JP3, JP4: M12PTH; 1X12-SMALL-PADS
L: LED0805-LARGE; 0805-LED-LARGEPADS
LED: LED3MMNOSILK; LED3MM_NOSILK
LOGO1, LOGO2: OSHW-LOGOL; OSHW-LOGO-L
OK1: SFH6206; DIL4-SMD
OP1, OP2, OP3, OP4, OP5, OP6, OP7, OP8, OP9, OP10, OP11, OP12, OP13, OP14: TLP168J; MFSOP-4-HANDSOLDER
P1, P2: PADSMALL; PAD-SMALL
R1: 3.3K; 1206-RES
R2, R18: 10K; 1206-RES
R3, R4, R5, R6, R7, R8, R9, R10, R11, R12, R13, R14, R15, R16, R21: 470; 1206-RES
R17, R19, R20: 4.7K; 1206-RES
RELAIS: Relais G6D; G6D
RL: AK500/2
RX-433MHZ: Receiver; RF-LINK_RX
SPARKCORE: SPARK_CORECORE; SPARK_CORE
SPI_OLED: CON_HEADER_1X07'SMALL'; M1X7
SW1: HLS8L-DC5V-S-C; 5P-L19.0XW15.0XH15.0MM
T1: 2N2222; TO92-EBC
TELEINFO: AK500/2
U$2: RFM12B; RFM12B-MINPADS
U$3: RFM69W; RFM69W-MINPADS
U-FL: U.FL

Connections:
+3V3: C1.1, EXTENSION.5, I2C_OLED.1, IC2.9 (VDD), J2.3, JP4.12, R2.2, R19.2, R20.2, SPARKCORE.24 (VCC), SPI_OLED.2, U$2.VDD (VCC), U$3.VDD (VCC)
+5V: D15.C, EXTENSION.3, JP3.12, RELAIS.13 (2), RX-433MHZ.+5V, SPARKCORE.1 (RAW), SW1.2 (V+)
A0: JP3.1, SPARKCORE.12 (A0)
A1: JP3.2, SPARKCORE.11 (A1)
A6/DAC: JP3.7, SPARKCORE.6 (A6)
A7/WKP: JP3.8, SPARKCORE.5 (A7)
ANT: P1.1, U$2.ANT, U$3.ANA (ANT), U-FL.3 (SIGNAL)
COM: RELAIS.7, RL.1, SW1.1 (COM)
D2: JP4.3, SPARKCORE.15 (D2), U$2.IRQ, U$3.DIO0
D3: JP4.4, SPARKCORE.16 (D3)
D4: JP4.5, RX-433MHZ.DATA@1 (DATA), RX-433MHZ.DATA@2 (DATA), SPARKCORE.17 (D4)
D5: JP4.6, SPARKCORE.18 (D5)
D6: JP4.7, SPARKCORE.19 (D6), SPI_OLED.7
D7: JP4.8, SPARKCORE.20 (D7), SPI_OLED.6
FP1: D1.1 (+), D2.2 (-), FILPILOTE.1
FP1A: IC2.7 (GPB6), R3.1
FP1B: IC2.8 (GPB7), R4.1
FP2: D3.1 (+), D4.2 (-), FILPILOTE.2
FP2A: IC2.5 (GPB4), R5.1
FP2B: IC2.6 (GPB5), R6.1
FP3: D5.1 (+), D6.2 (-), FILPILOTE.3
FP3A: IC2.3 (GPB2), R7.1
FP3B: IC2.4 (GPB3), R8.1
FP4: D7.1 (+), D8.2 (-), FILPILOTE.4
FP4A: IC2.22 (GPA1), R9.1
FP4B: IC2.21 (GPA0), R10.1
FP5: D9.1 (+), D10.2 (-), FILPILOTE.5
FP5A: IC2.24 (GPA3), R11.1
FP5B: IC2.23 (GPA2), R12.1
FP6: D11.1 (+), D12.2 (-), FILPILOTE.6
FP6A: IC2.26 (GPA5), R13.1
FP6B: IC2.25 (GPA4), R14.1
FP7: D13.1 (+), D14.2 (-), FILPILOTE.7
FP7A: IC2.28 (GPA7), R15.1
FP7B: IC2.27 (GPA6), R16.1
GND: C1.2, EXTENSION.4, I2C_OLED.2, IC2.10 (VSS), IC2.15 (A0), IC2.16 (A1), IC2.17 (A2), J2.4, JP3.11, JP4.9, L.MINUS, LED.MINUS, OK1.3 (E), OP1.3, OP2.3, OP3.3, OP4.3, OP5.3, OP6.3, OP7.3, OP8.3, OP9.3, OP10.3, OP11.3, OP12.3, OP13.3, OP14.3, R18.1, RX-433MHZ.GND, SPARKCORE.2 (GND), SPARKCORE.21 (GND), SPI_OLED.1, T1.E, U$2.GND, U$3.GND, U-FL.1 (GND), U-FL.2 (GND)
LED: IC2.1 (GPB0), P2.1, R21.2
MISO: JP3.5, SPARKCORE.8 (A4), U$2.SDO, U$3.MISO
MOSI: JP3.6, SPARKCORE.7 (A5), SPI_OLED.4, U$2.SDI, U$3.MOSI
unnamed: D1.2 (-), OP1.4
unnamed: D2.1 (+), OP2.4
unnamed: OK1.2 (AC2), TELEINFO.2
unnamed: OK1.1 (AC1), R1.2
unnamed: R1.1, TELEINFO.1
unnamed: L.PLUS, LED.PLUS, R21.1
unnamed: OP1.1, R3.2
unnamed: OP2.1, R4.2
unnamed: OP3.1, R5.2
unnamed: OP4.1, R6.2
unnamed: OP5.1, R7.2
unnamed: OP6.1, R8.2
unnamed: OP7.1, R9.2
unnamed: OP8.1, R10.2
unnamed: D15.A, RELAIS.1, SW1.3 (V-), T1.C
unnamed: 230V.1, F1.1
unnamed: OP9.1, R11.2
unnamed: R17.2, R18.2, T1.B
unnamed: D3.2 (-), OP3.4
unnamed: D5.2 (-), OP5.4
unnamed: D4.1 (+), OP4.4
unnamed: D7.2 (-), OP7.4
unnamed: D6.1 (+), OP6.4
unnamed: D8.1 (+), OP8.4
unnamed: OP10.1, R12.2
unnamed: OP14.1, R16.2
unnamed: D9.2 (-), OP9.4
unnamed: OP11.1, R13.2
unnamed: OP12.1, R14.2
unnamed: D10.1 (+), OP10.4
unnamed: D12.1 (+), OP12.4
NF: RL.2, SW1.5 (NC)
NO: 230V.2, RELAIS.5 (S), SW1.4 (NO)
PHASE: F1.2, OP1.6, OP2.6, OP3.6, OP4.6, OP5.6, OP6.6, OP7.6, OP8.6, OP9.6, OP10.6, OP11.6, OP12.6, OP13.6, OP14.6
RELAIS: IC2.2 (GPB1), R17.1
RST: IC2.18 (!RESET), JP4.11, SPARKCORE.23 (!RST), SPI_OLED.5
RX: JP3.9, OK1.4 (C), R2.1, SPARKCORE.4 (RX)
S$1: D11.2 (-), OP11.4
S$3: D13.2 (-), OP13.4
S$5: OP13.1, R15.2
S$11: D14.1 (+), OP14.4
SCK: JP3.4, SPARKCORE.9 (A3), SPI_OLED.3, U$2.SCK, U$3.SCK
SCL: EXTENSION.1, I2C_OLED.3, IC2.12 (SCL), J2.1, JP4.2, R20.1, SPARKCORE.14 (D1)
SDA: EXTENSION.2, I2C_OLED.4, IC2.13 (SDA), J2.2, JP4.1, R19.1, SPARKCORE.13 (D0)
SS: JP3.3, SPARKCORE.10 (A2), U$2.SEL, U$3.NSS (SEL)
TX: JP3.10, SPARKCORE.3 (TX)
VDDA: JP4.10, SPARKCORE.22 (VDDA)

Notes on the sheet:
7 Fils pilotes + 2 type de relais (au choix)
Module au choix, RFM12B, RFM69CW
Ou RFM69HW
Récepteur 433MHz
Double Récepteur RFM69 ou RFM12B + 433MHz
Revision B

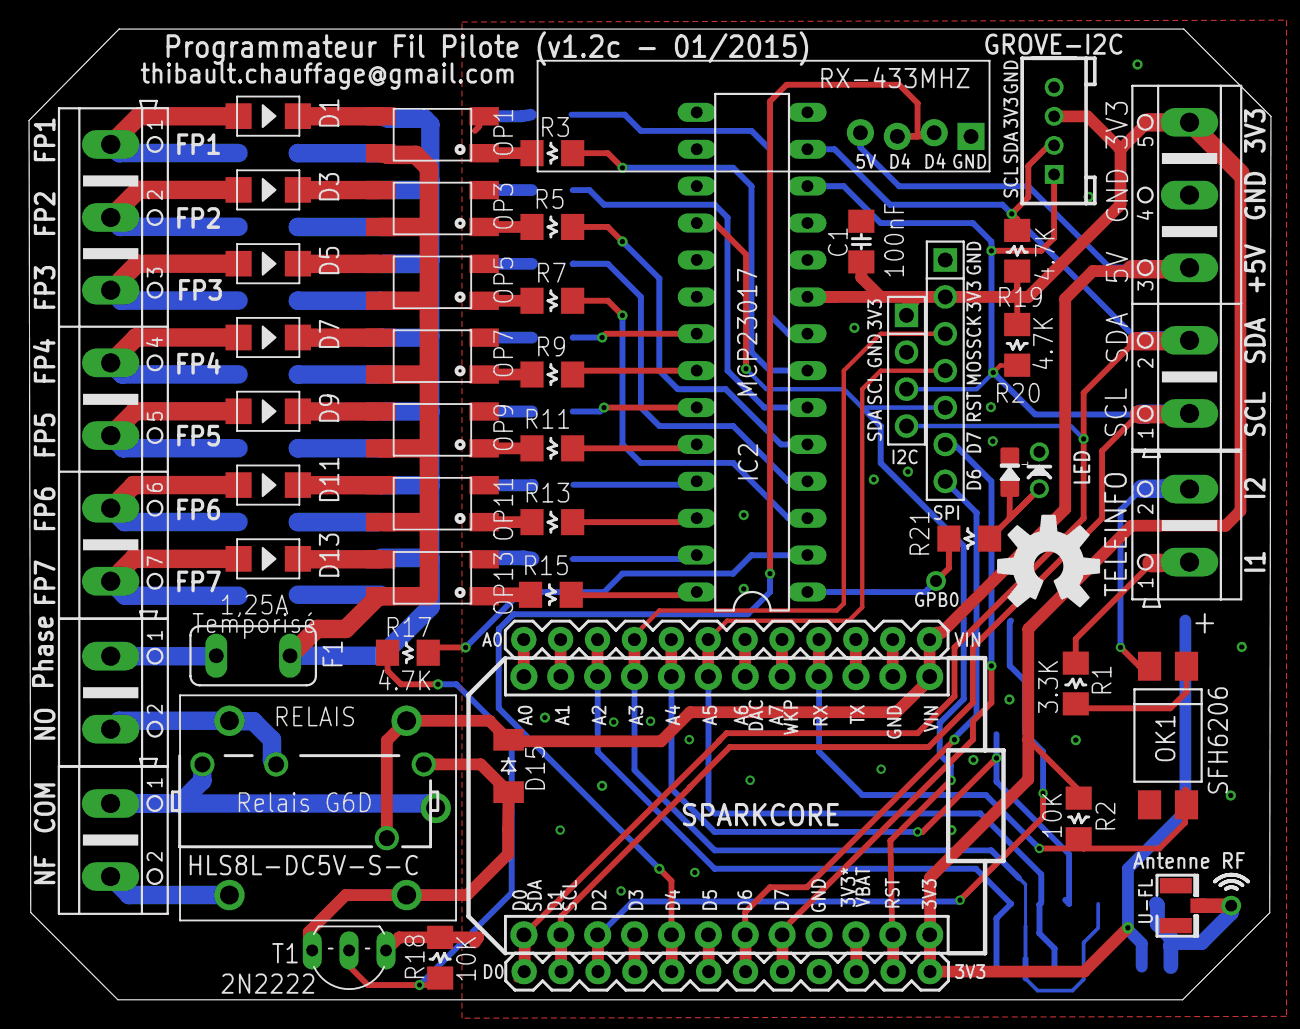
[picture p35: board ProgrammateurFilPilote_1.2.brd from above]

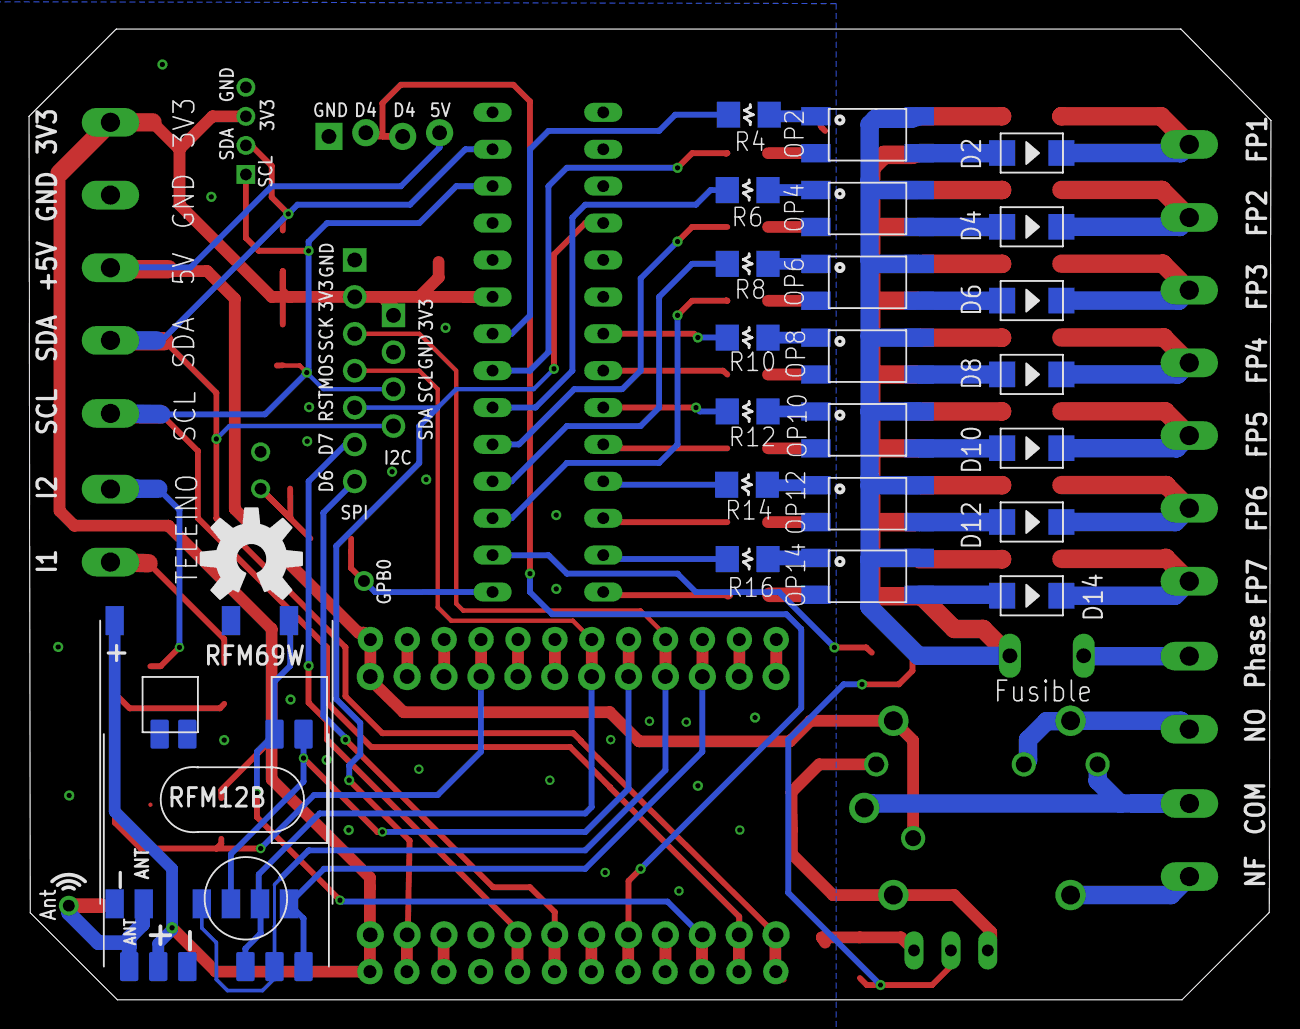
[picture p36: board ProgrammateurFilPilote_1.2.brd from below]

Board: 2 copper layers, 85.5 x 66.8 mm, 78 parts (24 on the bottom side), 86 nets.

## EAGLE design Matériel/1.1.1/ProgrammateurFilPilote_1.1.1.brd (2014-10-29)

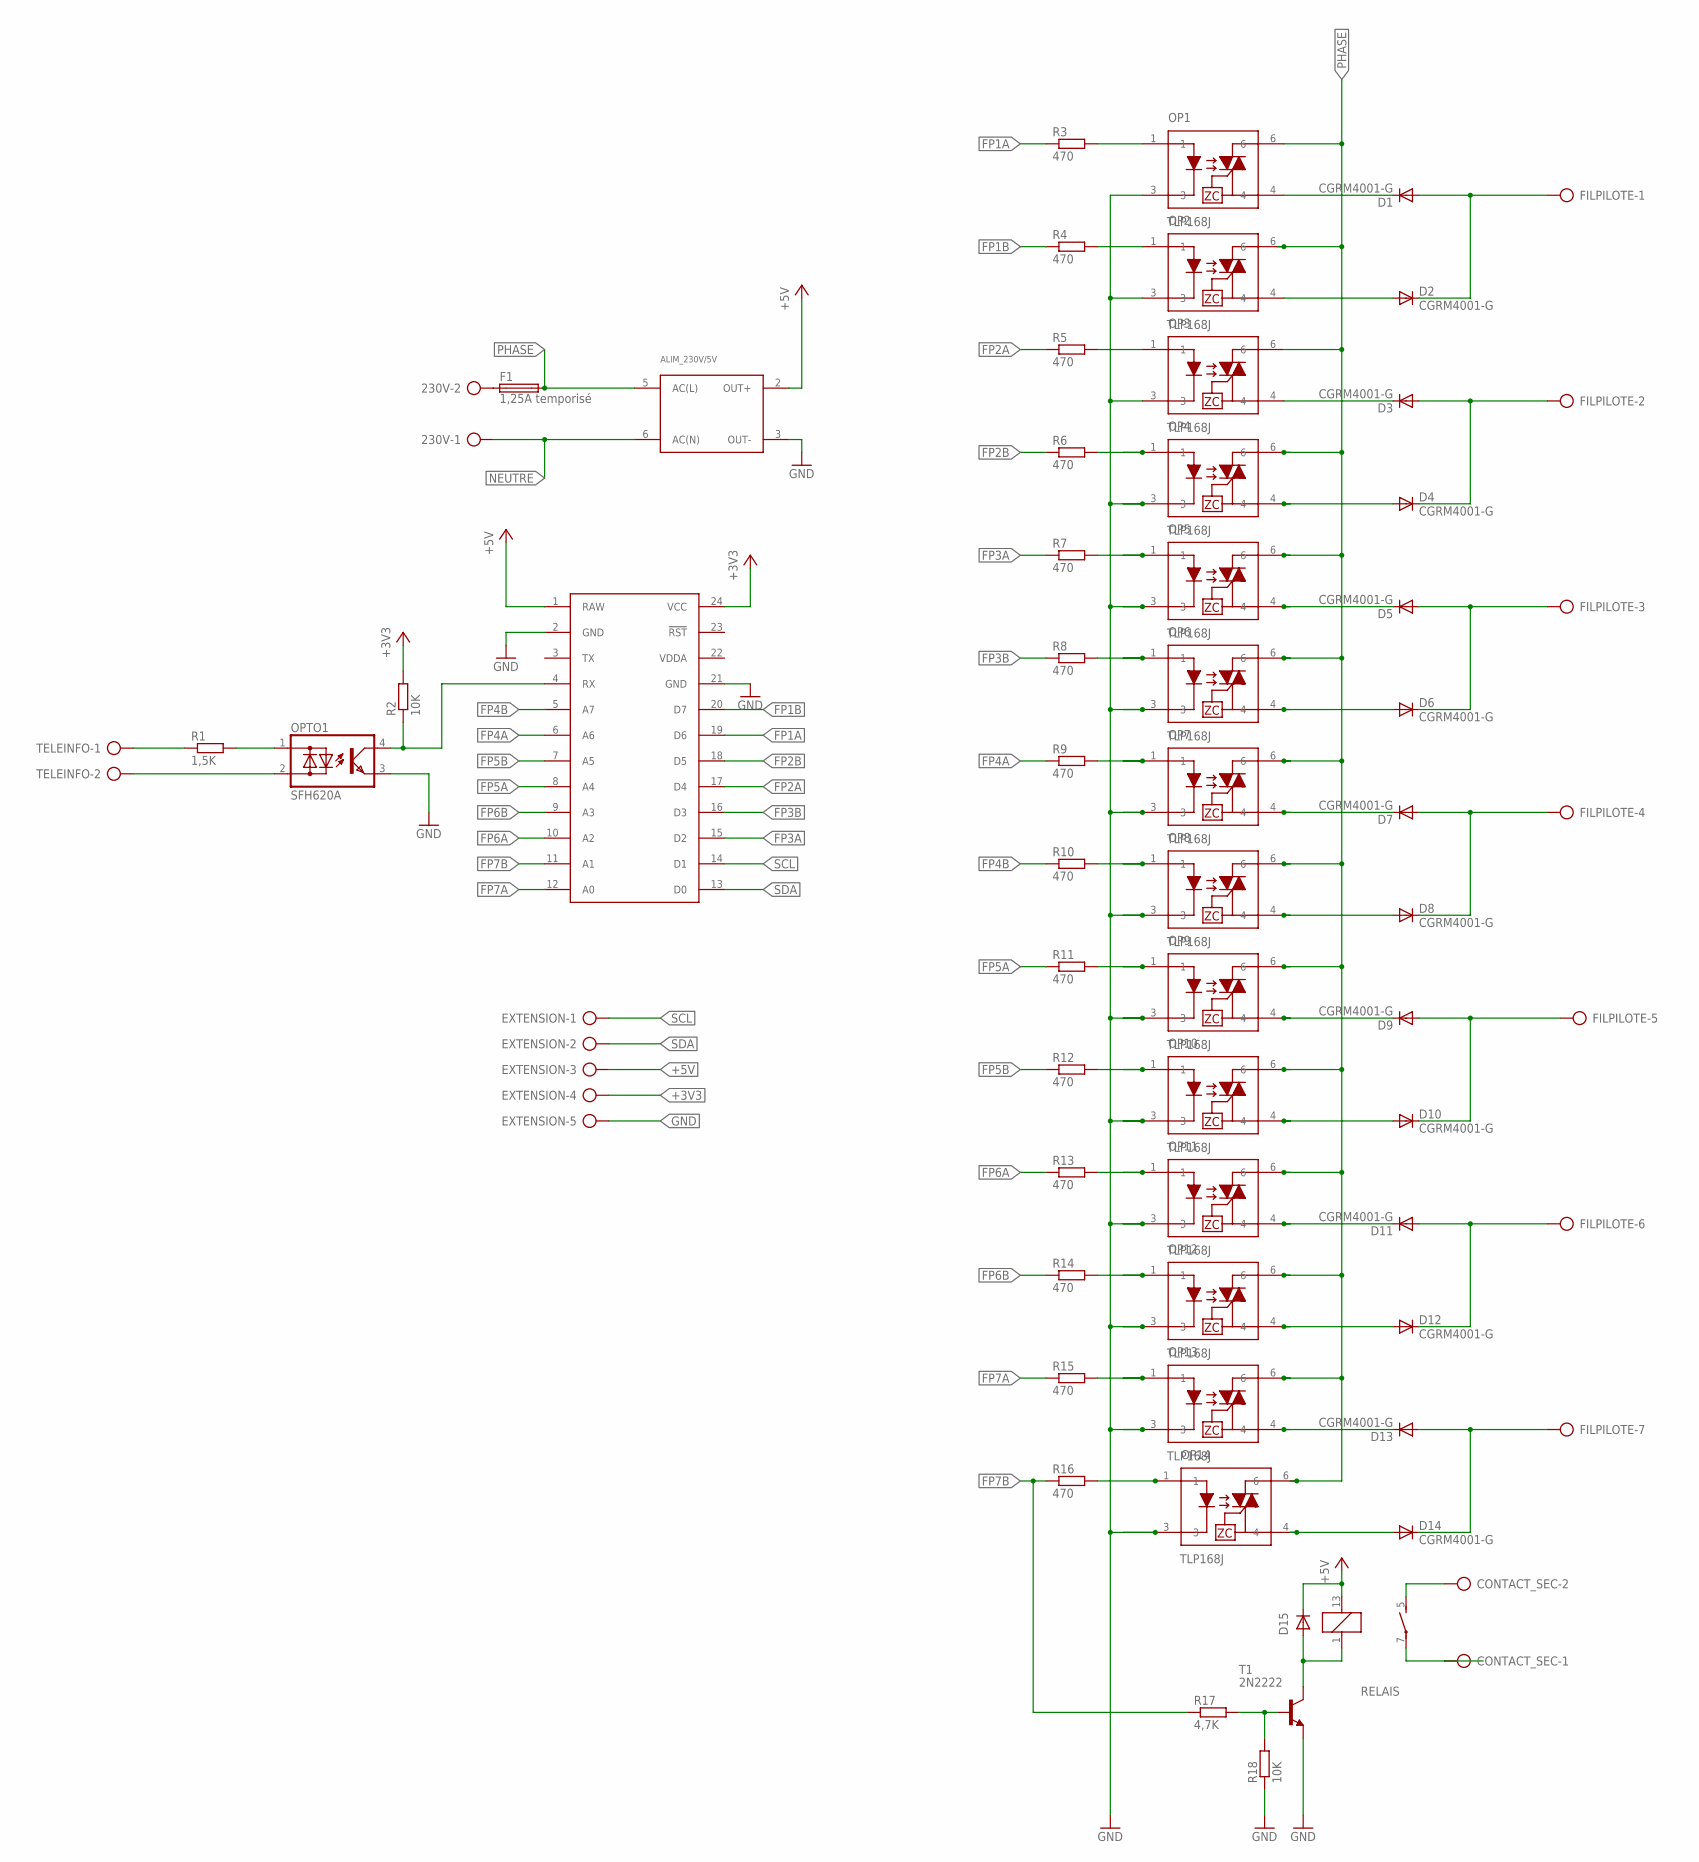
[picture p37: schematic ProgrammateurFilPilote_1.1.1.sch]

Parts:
230V: AK500/2
ALIM_230V/5V: TMLM04-SINGLE; TMLM04
CONTACT_SEC: AK500/2
D1, D2, D3, D4, D5, D6, D7, D8, D9, D10, D11, D12, D13, D14, D15: CGRM4001-G; SOD-123_MINI-SMA
EXTENSION: AK500/5
F1: 1,25A temporisé; TE5
FILPILOTE: AK500/7
OP1, OP2, OP3, OP4, OP5, OP6, OP7, OP8, OP9, OP10, OP11, OP12, OP13, OP14: TLP168J; MFSOP-4
OPTO1: SFH620A; DIL04
R1: 1,5K; R1206
R2, R18: 10K; R1206
R3, R4, R5, R6, R7, R8, R9, R10, R11, R12, R13, R14, R15, R16: 470; R1206
R17: 4,7K; R1206
RELAIS: Relais G6D; G6D
SPARKCORE: SPARK_CORECORE; SPARK_CORE
T1: 2N2222; TO92-EBC
TELEINFO: AK500/2

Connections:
+3V3: EXTENSION.4, R2.2, SPARKCORE.24 (VCC)
+5V: ALIM_230V/5V.2 (OUT+), D15.C, EXTENSION.3, RELAIS.13 (2), SPARKCORE.1 (RAW)
FP1A: R3.1, SPARKCORE.19 (D6)
FP1B: R4.1, SPARKCORE.20 (D7)
FP2A: R5.1, SPARKCORE.17 (D4)
FP2B: R6.1, SPARKCORE.18 (D5)
FP3A: R7.1, SPARKCORE.15 (D2)
FP3B: R8.1, SPARKCORE.16 (D3)
FP4A: R9.1, SPARKCORE.6 (A6)
FP4B: R10.1, SPARKCORE.5 (A7)
FP5A: R11.1, SPARKCORE.8 (A4)
FP5B: R12.1, SPARKCORE.7 (A5)
FP6A: R13.1, SPARKCORE.10 (A2)
FP6B: R14.1, SPARKCORE.9 (A3)
FP7A: R15.1, SPARKCORE.12 (A0)
FP7B: R16.1, R17.1, SPARKCORE.11 (A1)
GND: ALIM_230V/5V.3 (OUT-), EXTENSION.5, OP1.3, OP2.3, OP3.3, OP4.3, OP5.3, OP6.3, OP7.3, OP8.3, OP9.3, OP10.3, OP11.3, OP12.3, OP13.3, OP14.3, OPTO1.3 (E), R18.1, SPARKCORE.2 (GND), SPARKCORE.21 (GND), T1.E
unnamed: D1.C, OP1.4
unnamed: D2.A, OP2.4
unnamed: OPTO1.2 (AC2), TELEINFO.2
unnamed: OPTO1.1 (AC1), R1.2
unnamed: R1.1, TELEINFO.1
unnamed: OPTO1.4 (C), R2.1, SPARKCORE.4 (RX)
unnamed: OP1.1, R3.2
unnamed: OP2.1, R4.2
unnamed: OP3.1, R5.2
unnamed: OP4.1, R6.2
unnamed: OP5.1, R7.2
unnamed: OP6.1, R8.2
unnamed: OP7.1, R9.2
unnamed: OP8.1, R10.2
unnamed: D15.A, RELAIS.1, T1.C
unnamed: 230V.2, F1.1
unnamed: CONTACT_SEC.2, RELAIS.5 (S)
unnamed: OP9.1, R11.2
unnamed: CONTACT_SEC.1, RELAIS.7
unnamed: R17.2, R18.2, T1.B
unnamed: D3.C, OP3.4
unnamed: D3.A, D4.C, FILPILOTE.2
unnamed: D5.C, OP5.4
unnamed: D4.A, OP4.4
unnamed: D7.C, OP7.4
unnamed: D5.A, D6.C, FILPILOTE.3
unnamed: D1.A, D2.C, FILPILOTE.1
unnamed: D6.A, OP6.4
unnamed: D7.A, D8.C, FILPILOTE.4
unnamed: D8.A, OP8.4
unnamed: OP10.1, R12.2
unnamed: OP14.1, R16.2
unnamed: D9.C, OP9.4
unnamed: D9.A, D10.C, FILPILOTE.5
unnamed: OP11.1, R13.2
unnamed: OP12.1, R14.2
unnamed: D10.A, OP10.4
unnamed: D11.A, D12.C, FILPILOTE.6
unnamed: D12.A, OP12.4
NEUTRE: 230V.1, ALIM_230V/5V.6 (AC(N))
PHASE: ALIM_230V/5V.5 (AC(L)), F1.2, OP1.6, OP2.6, OP3.6, OP4.6, OP5.6, OP6.6, OP7.6, OP8.6, OP9.6, OP10.6, OP11.6, OP12.6, OP13.6, OP14.6
S$1: D11.C, OP11.4
S$3: D13.C, OP13.4
S$5: OP13.1, R15.2
S$6: D13.A, D14.C, FILPILOTE.7
S$11: D14.A, OP14.4
SCL: EXTENSION.1, SPARKCORE.14 (D1)
SDA: EXTENSION.2, SPARKCORE.13 (D0)
VDDA: SPARKCORE.22 (VDDA)

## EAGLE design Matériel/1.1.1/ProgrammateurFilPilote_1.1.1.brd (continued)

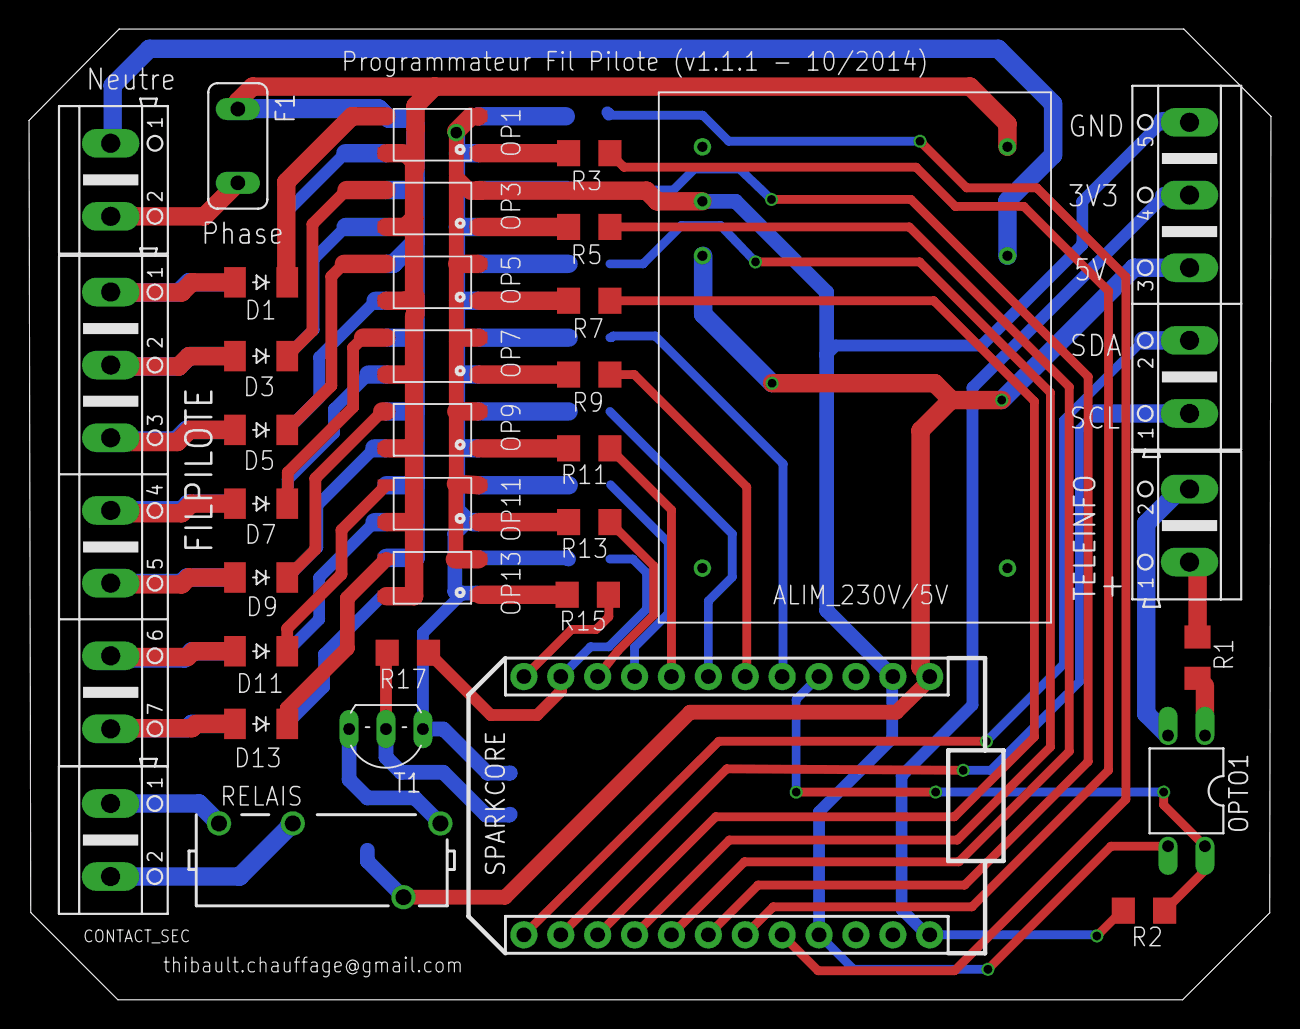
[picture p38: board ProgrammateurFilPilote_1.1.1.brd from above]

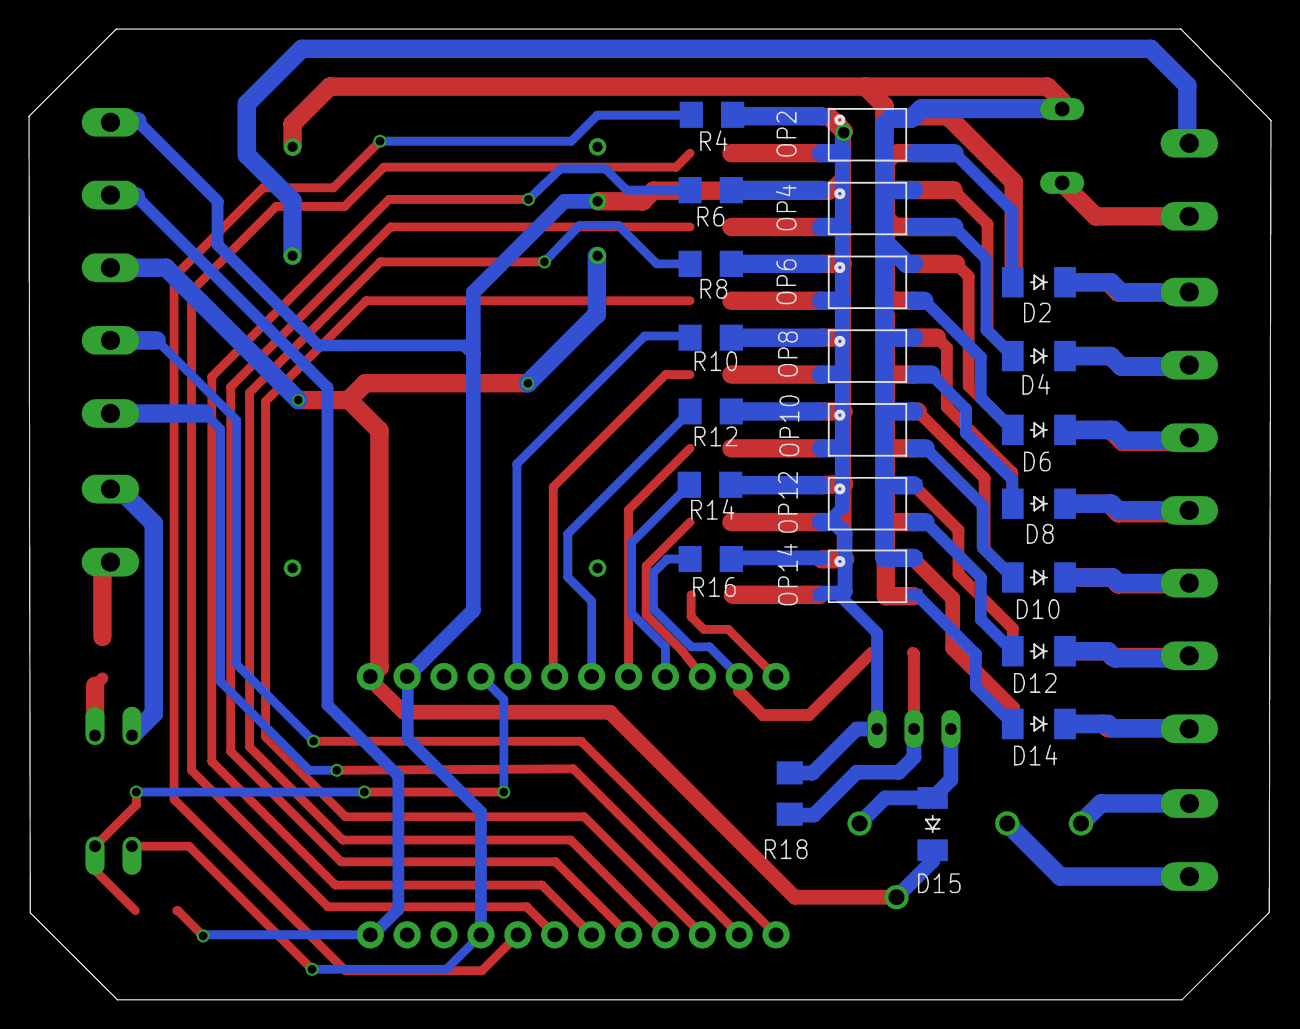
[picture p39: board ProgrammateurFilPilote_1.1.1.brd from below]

Board: 2 copper layers, 85.5 x 66.8 mm, 58 parts (23 on the bottom side), 65 nets.

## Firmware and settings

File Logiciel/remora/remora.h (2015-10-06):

// **********************************************************************************
// Programmateur Fil Pilote et Suivi Conso
// **********************************************************************************
// Copyright (C) 2014 Thibault Ducret
// Licence MIT
//
// History : 15/01/2015 Charles-Henri Hallard (http://hallard.me)
//                      Intégration de version 1.2 de la carte electronique
//            15/09/2015 Charles-Henri Hallard : Ajout compatibilité ESP8266
//
// **********************************************************************************
#ifndef REMORA_h
#define REMORA_h

// Spark Core main firmware include file
#ifdef SPARK
#include "application.h"
#endif

// Définir ici le type de carte utilsé
//#define REMORA_BOARD_V10  // Version 1.0
//#define REMORA_BOARD_V11  // Version 1.1
#define REMORA_BOARD_V12  // Version 1.2

//  Définir ici les modules utilisés sur la carte Remora
#define MOD_RF69      /* Module RF  */
#define MOD_OLED      /* Afficheur  */
#define MOD_TELEINFO  /* Teleinfo   */
//#define MOD_RF_OREGON   /* Reception des sondes orégon */

// Librairies du projet remora Pour Particle
#ifdef SPARK
  #include "MCP23017.h"
  #include "SSD1306.h"
  #include "GFX.h"
  #include "ULPNode_RF_Protocol.h"
  #include "LibTeleinfo.h"
  //#include "WebServer.h"

  #include "display.h"
  #include "i2c.h"
  #include "pilotes.h"
  #include "rfm.h"
  #include "tinfo.h"
  #include "linked_list.h"
  #include "route.h"
  #include "RadioHead.h"
  #include "RH_RF69.h"
  #include "RHDatagram.h"
  #include "RHReliableDatagram.h"

  //#include "OLED_local.h"
  //#include "mfGFX_local.h"

  #define _yield()  Particle.process()
#endif

// Librairies du projet remora Pour Particle
#ifdef ESP8266
  #if defined (REMORA_BOARD_V10) || defined (REMORA_BOARD_V11)
  #error "La version ESP8266 NodeMCU n'est pas compatible avec les cartes V1.1x"
  #endif

  // Définir ici les identifiants de
  // connexion à votre réseau Wifi
  #define DEFAULT_WIFI_SSID "************"
  #define DEFAULT_WIFI_PASS "************"
  #define DEFAULT_OTA_PORT  8266
  #define DEFAULT_HOSTNAME  "remora"
  #include "Arduino.h"
  #include "./MCP23017.h"
  //#include "./RFM69registers.h"
  //#include "./RFM69.h"
  #include "./SSD1306.h"
  #include "./GFX.h"
  #include "./ULPNode_RF_Protocol.h"
  #include "./LibTeleinfo.h"

  #define _yield()  yield()
#endif

// Includes du projets remora
#include "linked_list.h"
#include "i2c.h"
#include "rfm.h"
#include "display.h"
#include "pilotes.h"
#include "tinfo.h"

// RGB LED related MACROS
#if defined (SPARK)
  #define COLOR_RED     255,   0,   0
  #define COLOR_ORANGE  255, 127,   0
  #define COLOR_YELLOW  255, 255,   0
  #define COLOR_GREEN     0, 255,   0
  #define COLOR_CYAN      0, 255, 255
  #define COLOR_BLUE      0,   0, 255
  #define COLOR_MAGENTA 255,   0, 255

  #define LedRGBOFF() RGB.color(0,0,0)
  #define LedRGBON(x) RGB.color(x)

  // RFM69 Pin mapping
  #define RF69_CS  SS // default SPI SS Pin
  #define RF69_IRQ 2

#elif defined (ESP8266)
  #define COLOR_RED     rgb_brightness, 0, 0
  #define COLOR_ORANGE  rgb_brightness, rgb_brightness>>1, 0
  #define COLOR_YELLOW  rgb_brightness, rgb_brightness, 0
  #define COLOR_GREEN   0, rgb_brightness, 0
  #define COLOR_CYAN    0, rgb_brightness, rgb_brightness
  #define COLOR_BLUE    0, 0, rgb_brightness
  #define COLOR_MAGENTA rgb_brightness, 0, rgb_brightness

  // On ESP8266 we use NeopixelBus library to drive neopixel RGB LED
  //#define LedRGBOFF() { rgb_led.SetPixelColor(0,0,0,0); rgb_led.Show(); }
  //#define LedRGBON(x) { rgb_led.SetPixelColor(0,x); rgb_led.Show(); }
  #define LedRGBOFF() {}
  #define LedRGBON(x) {}

  // RFM69 Pin mapping
  #define RF69_CS   15
  #define RF69_IRQ  2
#endif

// Ces modules ne sont pas disponibles sur les carte 1.0 et 1.1
#if defined (REMORA_BOARD_V10) || defined (REMORA_BOARD_V11)
  #undef MOD_RF69
  #undef MOD_OLED
  #undef MOD_RF_OREGON

  // en revanche le relais l'est sur la carte 1.1
  #ifdef REMORA_BOARD_V11
    #define RELAIS_PIN A1
  #endif

  // Creation macro unique et indépendante du type de
  // carte pour le controle des I/O
  #define _digitalWrite(p,v)  digitalWrite(p,v)
  #define _pinMode(p,v)       pinMode(p,v)

// Carte 1.2+
#else
  #define LED_PIN    8
  #define RELAIS_PIN 9

  // Creation macro unique et indépendante du type de
  // carte pour le controle des I/O
  #define _digitalWrite(p,v)  mcp.digitalWrite(p,v)
  #define _pinMode(p,v)       mcp.pinMode(p,v)
#endif

// Masque de bits pour le status global de l'application
#define STATUS_MCP    0x0001 // I/O expander detecté
#define STATUS_OLED   0x0002 // Oled detecté
#define STATUS_RFM    0x0004 // RFM69  detecté
#define STATUS_TINFO  0x0008 // Trame téléinfo detecté

// Variables exported to other source file
// ========================================
// define var for whole project

// status global de l'application
extern uint16_t status;
extern unsigned long uptime ;


#ifdef SPARK
  // Particle WebServer
  //extern WebServer server("", 80);
#endif

#ifdef ESP8266
  // ESP8266 WebServer
  extern ESP8266WebServer server;
#endif


extern uint16_t status; // status global de l'application

// Function exported for other source file
// =======================================
char * timeAgo(unsigned long);

#endif

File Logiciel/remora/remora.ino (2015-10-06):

  // **********************************************************************************
// Programmateur Fil Pilote et Suivi Conso
// **********************************************************************************
// Copyright (C) 2014 Thibault Ducret
// Licence MIT
//
// History : 15/01/2015 Charles-Henri Hallard (http://hallard.me)
//                      Intégration de version 1.2 de la carte electronique
//           13/04/2015 Theju
//                      Modification des variables cloud teleinfo
//                      (passage en 1 seul appel) et liberation de variables
//           15/09/2015 Charles-Henri Hallard : Ajout compatibilité ESP8266
//
// **********************************************************************************

// Tout est inclus dans le fichier remora.h
// Pour activer des modules spécifiques ou
// changer différentes configurations il
// faut le faire dans le fichier remora.h
#include "remora.h"

#ifdef SPARK
  #include "MCP23017.h"
  #include "SSD1306.h"
  #include "GFX.h"
  #include "ULPNode_RF_Protocol.h"
  #include "LibTeleinfo.h"
  //#include "WebServer.h"
  #include "display.h"
  #include "i2c.h"
  #include "pilotes.h"
  #include "rfm.h"
  #include "tinfo.h"
  #include "linked_list.h"
  #include "route.h"
  #include "RadioHead.h"
  #include "RH_RF69.h"
  #include "RHDatagram.h"
  #include "RHReliableDatagram.h"
#endif

// Arduino IDE need include in main INO file
#ifdef ESP8266
  #include <ESP8266WiFi.h>
  #include <ESP8266WebServer.h>
  #include <ESP8266mDNS.h>
  #include <WiFiUDP.h>
  #include <Wire.h>
  #include <SPI.h>
  #include "./MCP23017.h"
  #include "./SSD1306.h"
  #include "./GFX.h"
  #include "./ULPNode_RF_Protocol.h"
  #include "./LibTeleinfo.h"
#endif

// Variables globales
// ==================
// status global de l'application
uint16_t status = 0;
unsigned long uptime = 0;
// Nombre de deconexion cloud detectée
int my_cloud_disconnect = 0;


#ifdef SPARK
  // Particle WebServer
  //WebServer server("", 80);
#endif

#ifdef ESP8266
  // ESP8266 WebServer
  ESP8266WebServer server(80);
  // Udp listener for OTA
  WiFiUDP OTA;
  // Use WiFiClient class to create a connection to WEB server
  WiFiClient client;
#endif

/* ======================================================================
Function: spark_expose_cloud
Purpose : declare et expose les variables et fonctions cloud
Input   :
Output  : -
Comments: -
====================================================================== */
#ifdef SPARK
void spark_expose_cloud(void)
{
  Serial.println("spark_expose_cloud()");

  #ifdef MOD_TELEINFO
    // Déclaration des variables "cloud" pour la téléinfo (10 variables au maximum)
    // je ne sais pas si les fonction cloud sont persistentes
    // c'est à dire en cas de deconnexion/reconnexion du wifi
    // si elles sont perdues ou pas, à tester
    // -> Theju: Chez moi elles persistes, led passe verte mais OK
    //Spark.variable("papp", &mypApp, INT);
    //Spark.variable("iinst", &myiInst, INT);
    //Spark.variable("isousc", &myisousc, INT);
    //Spark.variable("indexhc", &myindexHC, INT);
    //Spark.variable("indexhp", &myindexHP, INT);
    //Spark.variable("periode", &myPeriode, STRING); // Période tarifaire en cours (string)
    //Spark.variable("iperiode", (ptec_e *)&ptec, INT); // Période tarifaire en cours (numerique)

    // Récupération des valeurs d'étiquettes :
    Particle.variable("tinfo", mytinfo, STRING);

  #endif

  // Déclaration des fonction "cloud" (4 fonctions au maximum)
  Particle.function("fp",    fp);
  Particle.function("setfp", setfp);

  // Déclaration des variables "cloud"
  Particle.variable("nivdelest", &nivDelest, INT); // Niveau de délestage (nombre de zones délestées)
  //Spark.variable("disconnect", &cloud_disconnect, INT);
  Particle.variable("etatfp", etatFP, STRING); // Etat actuel des fils pilotes
  Particle.variable("memfp", memFP, STRING); // Etat mémorisé des fils pilotes (utile en cas de délestage)

  // relais pas disponible sur les carte 1.0
  #ifndef REMORA_BOARD_V10
    Particle.function("relais", relais);
    Particle.variable("etatrelais", &etatrelais, INT);
  #endif
}
#endif


// ====================================================
// Following are dedicated to ESP8266 Platform
// Wifi management and OTA updates
// ====================================================
#ifdef ESP8266
/* ======================================================================
Function: CheckOTAUpdate
Purpose : Check if we need to update the firmware over the Air
Input   : -
Output  : -
Comments: If upgraded, no return, perform update and reboot ESP
====================================================================== */
void CheckOTAUpdate(void)
{
  //OTA detection
  if (OTA.parsePacket()) {
    IPAddress remote = OTA.remoteIP();
    int cmd  = OTA.parseInt();
    int port = OTA.parseInt();
    int size = OTA.parseInt();

    LedRGBON(COLOR_MAGENTA);

    Serial.print(F("Update Start: ip:"));
    Serial.print(remote);
    Serial.printf(", port:%d, size:%dKB\n", port, size/1024);
    uint32_t startTime = millis();

    WiFiUDP::stopAll();

    if(!Update.begin(size)) {
      Serial.print(F("Update Begin Error"));
      return;
    }

    // Declare Wifi client connexion
    WiFiClient ota_client;

    if (ota_client.connect(remote, port)) {

      uint32_t written;
      while(!Update.isFinished()) {
        written = Update.write(ota_client);
        if(written > 0)
        {
          LedRGBOFF();
          ota_client.print(written, DEC);
          LedRGBON(COLOR_MAGENTA);
        }
      }
      LedRGBOFF();
      Serial.setDebugOutput(false);

      if(Update.end()) {
        ota_client.println("OK");
        Serial.printf("Update Success: %u\nRebooting...\n", millis() - startTime);
        ESP.restart();
      } else {
        Update.printError(ota_client);
        Update.printError(Serial);
      }
    } else {
      Serial.printf("Connect Failed: %u\n", millis() - startTime);
    }

    // Be sure to re enable it
    OTA.begin(DEFAULT_OTA_PORT);
  }
}

/* ======================================================================
Function: WifiHandleConn
Purpose : Handle Wifi connection / reconnection and OTA updates
Input   : -
Output  : state of the wifi status
Comments: -
====================================================================== */
int WifiHandleConn()
{
  int ret = WiFi.status();

  // Wait for connection if disconnected
  if ( ret != WL_CONNECTED ) {

    // Orange we're not connected anymore
    LedRGBON(COLOR_ORANGE);

    Serial.print(F("Connecting to: "));
    Serial.print(DEFAULT_WIFI_SSID);
    Serial.print(F("..."));

    WiFi.begin(DEFAULT_WIFI_SSID, DEFAULT_WIFI_PASS);

    ret = WiFi.waitForConnectResult();
    if ( ret != WL_CONNECTED) {
      LedRGBON(COLOR_RED);
      Serial.println(F("Connection failed!"));
    } else {
      LedRGBON(COLOR_GREEN);
      Serial.println(F("Connected"));
      Serial.print(F("IP address   : ")); Serial.println(WiFi.localIP());
      Serial.print(F("MAC address  : ")); Serial.println(WiFi.macAddress());

      MDNS.begin(DEFAULT_HOSTNAME);
      MDNS.addService("arduino", "tcp", DEFAULT_OTA_PORT);
      OTA.begin(DEFAULT_OTA_PORT);

      // just in case your sketch sucks, keep update OTA Available
      // Trust me, when coding and testing it happens, this could save
      // the need to connect FTDI to reflash
      // Usefull just after 1st connexion when called from setup() before
      // launching potentially bugging main()
      for (uint8_t i=0; i<= 10; i++) {
        LedRGBON(COLOR_MAGENTA);
        delay(100);
        LedRGBOFF();
        delay(200);
        CheckOTAUpdate();
      }
    }
  }

  // Handle OTA if we're connected
  if ( ret == WL_CONNECTED )
    CheckOTAUpdate();

  return ret;
}
#endif

/* ======================================================================
Function: timeAgo
Purpose : format total seconds to human readable text
Input   : second
Output  : pointer to string
Comments: -
====================================================================== */
char * timeAgo(unsigned long sec)
{
  static char buff[16];

  // Clear buffer
  buff[0] = '\0';

  if (sec < 2) {
    sprintf_P(buff,PSTR("just now"));
  } else if (sec < 60) {
    sprintf_P(buff,PSTR("%d seconds ago"), sec);
  } else if (sec < 120) {
    sprintf_P(buff,PSTR("1 minute ago"));
  } else if (sec < 3600) {
    sprintf_P(buff,PSTR("%d minutes ago"), sec/60);
  } else if (sec < 7200) {
    sprintf_P(buff,PSTR("1 hour ago"));
  } else if (sec < 86400) {
    sprintf_P(buff,PSTR("%d hours ago"), sec/3660);
  } else if (sec < 172800) {
    sprintf_P(buff,PSTR("yesterday"));
  } else if (sec < 604800) {
    sprintf_P(buff,PSTR("%d days ago"), sec/86400);
  }
  return buff;
}


/* ======================================================================
Function: setup
Purpose : prepare and init stuff, configuration, ..
Input   : -
Output  : -
Comments: -
====================================================================== */
void setup()
{
  uint8_t rf_version = 0;

  #ifdef SPARK
    bool start = false;
    long started ;

    // On prend le controle de la LED RGB pour faire
    // un heartbeat si Teleinfo ou OLED ou RFM69
    #if defined (MOD_TELEINFO) || defined (MOD_OLED) || defined (MOD_RF69)
    RGB.control(true);
    RGB.brightness(128);
    // En jaune nous ne sommes pas encore prêt
    LedRGBON(COLOR_YELLOW);
    #endif

    // nous sommes en GMT+1
    Time.zone(+1);

    // Rendre à dispo nos API, çà doit être fait
    // très rapidement depuis le dernier firmware
    spark_expose_cloud();

    Serial.begin(115200); // Port série USB

    // C'est parti
    started = millis();

    // Attendre que le core soit bien connecté à la serial
    // car en cas d'update le core perd l'USB Serial a
    // son reboot et sous windows faut reconnecter quand
    // on veut débugguer, et si on est pas synchro on rate
    // le debut du programme, donc petite pause le temps de
    // reconnecter le terminal série sous windows
    // Une fois en prod c'est plus necessaire, c'est vraiment
    // pour le développement (time out à 10s)
    while(!start)
    {
      // Il suffit du time out ou un caractère reçu
      // sur la liaison série USB pour démarrer
      if (Serial.available() || millis()-started >= 2000)
        start = true;

      // On clignote en jaune pour indiquer l'attente
      LedRGBON(COLOR_YELLOW);
      delay(50);

      // Jamais on ne bloque le firmware
      // sous perte de deconnexion du réseau
      _yield();

      // On clignote en rouge pour indiquer l'attente
      LedRGBOFF();
      delay(100);
    }

    // Et on affiche nos paramètres
    Serial.println("Core Network settings");
    Serial.print("IP   : "); Serial.println(WiFi.localIP());
    Serial.print("Mask : "); Serial.println(WiFi.subnetMask());
    Serial.print("GW   : "); Serial.println(WiFi.gatewayIP());
    Serial.print("SSDI : "); Serial.println(WiFi.SSID());
    Serial.print("RSSI : "); Serial.print(WiFi.RSSI());Serial.println("dB");

    //  WebServer / Command
    //server.setDefaultCommand(&handleRoot);
    //webserver.addCommand("json", &sendJSON);
    //webserver.addCommand("tinfojsontbl", &tinfoJSONTable);
    //webserver.setFailureCommand(&handleNotFound);

    // start the webserver
    //server.begin();

  #elif defined (ESP8266)
    // Init de la téléinformation
    Serial.begin(1200, SERIAL_7E1);

    // Connection au Wifi ou Vérification
    WifiHandleConn();
  #endif

  // Init bus I2C
  i2c_init();

  Serial.print("Compile avec les fonctions : ");

  #ifdef REMORA_BOARD_V12
    Serial.print("MCP23017 ");
  #endif
  #ifdef MOD_OLED
    Serial.print("OLED ");
  #endif
  #ifdef MOD_TELEINFO
    Serial.print("TELEINFO ");
  #endif
  #ifdef MOD_RF69
    Serial.print("RFM69 ");
  #endif

  Serial.println();

  // Init des fils pilotes
  if (pilotes_setup())
    status |= STATUS_MCP ;

  #ifdef MOD_OLED
    // Initialisation de l'afficheur
    if (display_setup())
    {
      status |= STATUS_OLED ;
      // Splash screen
      display_splash();
    }
  #endif

  #ifdef MOD_RF69
    // Initialisation RFM69 Module
    if ( rfm_setup())
      status |= STATUS_RFM ;
  #endif

  #ifdef MOD_TELEINFO
    // Initialiser la téléinfo et attente d'une trame valide
    // Le status est mis à jour dans les callback de la teleinfo
    tinfo_setup(true);
  #endif

  // Led verte durant le test
  LedRGBON(COLOR_GREEN);

  // Enclencher le relais 1 seconde
  // si dispo sur la carte
  #ifndef REMORA_BOARD_V10
    Serial.print("Relais=ON   ");
    relais("1");
    for (uint8_t i=0; i<20; i++)
    {
      delay(10);
      // Ne pas bloquer la reception et
      // la gestion de la téléinfo
      #ifdef MOD_TELEINFO
        tinfo_loop();
      #endif
    }
    Serial.println("Relais=OFF");
    relais("0");
  #endif

  // nous avons fini, led Jaune
  LedRGBON(COLOR_YELLOW);

  // Hors gel, désactivation des fils pilotes
  initFP();

  // On etteint la LED embarqué du core
  LedRGBOFF();

  Serial.println("Starting main loop");
}

/* ======================================================================
Function: loop
Purpose : boucle principale du programme
Input   : -
Output  : -
Comments: -
====================================================================== */
void loop()
{
  static bool refreshDisplay = false;
  static bool lastcloudstate;
  static unsigned long previousMillis = 0;  // last time update
  unsigned long currentMillis = millis();
  bool currentcloudstate ;

  // Gérer notre compteur de secondes
  if ( millis()-previousMillis > 1000) {
    // Ceci arrive toute les secondes écoulées
    previousMillis = currentMillis;
    uptime++;
    refreshDisplay = true ;
  }

  #ifdef MOD_TELEINFO
    // Vérification de la reception d'une 1ere trame téléinfo
    tinfo_loop();
    _yield();
  #endif

  #ifdef MOD_RF69
    // Vérification de la reception d'une trame RF
    if (status & STATUS_RFM)
      rfm_loop();
      _yield();
  #endif

  #ifdef MOD_OLED
    // pour le moment on se contente d'afficher la téléinfo
    screen_state = screen_teleinfo;

    // Modification d'affichage et afficheur présent ?
    if (refreshDisplay && (status & STATUS_OLED))
      display_loop();
      _yield();
  #endif

  // çà c'est fait
  refreshDisplay = false;

  #if defined (SPARK)
  // recupération de l'état de connexion au cloud SPARK
  currentcloudstate = Spark.connected();
  #elif defined (ESP8266)
  // recupération de l'état de connexion au Wifi
  currentcloudstate = WiFi.status()==WL_CONNECTED ? true:false;
  #endif

  // La connexion cloud vient de chager d'état ?
  if (lastcloudstate != currentcloudstate)
  {
    // Mise à jour de l'état
    lastcloudstate=currentcloudstate;

    // on vient de se reconnecter ?
    if (currentcloudstate)
    {
      // on pubie à nouveau nos affaires
      // Plus necessaire
      #ifdef SPARK
      // spark_expose_cloud();
      #endif

      // led verte
      LedRGBON(COLOR_GREEN);
    }
    else
    {
      // on compte la deconnexion led rouge
      my_cloud_disconnect++;
      Serial.print("Perte de conexion au cloud #");
      Serial.println(my_cloud_disconnect);
      LedRGBON(COLOR_RED);
    }
  }

  //#ifdef SPARK
  //char buff[64];
  //int len = 64;

  // process incoming connections one at a time forever
  //server.processConnection(buff, &len);
  //#endif


  // Connection au Wifi ou Vérification
  #ifdef ESP8266
  WifiHandleConn();
  #endif

}

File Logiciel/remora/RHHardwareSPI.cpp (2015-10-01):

// RHHardwareSPI.h
// Author: Mike McCauley (mikem@airspayce.com)
// Copyright (C) 2011 Mike McCauley
// Contributed by Joanna Rutkowska
// $Id: RHHardwareSPI.cpp,v 1.12 2015/07/01 00:46:05 mikem Exp $

#include "RHHardwareSPI.h"

// Declare a single default instance of the hardware SPI interface class
RHHardwareSPI hardware_spi;

#ifdef RH_HAVE_HARDWARE_SPI

#if (RH_PLATFORM == RH_PLATFORM_STM32) // Maple etc
// Declare an SPI interface to use
HardwareSPI SPI(1);
#elif (RH_PLATFORM == RH_PLATFORM_STM32STD) // STM32F4 Discovery
// Declare an SPI interface to use
HardwareSPI SPI(1);
#endif

// Arduino Due has default SPI pins on central SPI headers, and not on 10, 11, 12, 13
// as per otherArduinos
// http://21stdigitalhome.blogspot.com.au/2013/02/arduino-due-hardware-spi.html
#if defined (__arm__) && !defined(CORE_TEENSY) && !defined(SPARK)
 // Arduino Due in 1.5.5 has no definitions for SPI dividers
 // SPI clock divider is based on MCK of 84MHz
 #define SPI_CLOCK_DIV16 (VARIANT_MCK/84000000) // 1MHz
 #define SPI_CLOCK_DIV8  (VARIANT_MCK/42000000) // 2MHz
 #define SPI_CLOCK_DIV4  (VARIANT_MCK/21000000) // 4MHz
 #define SPI_CLOCK_DIV2  (VARIANT_MCK/10500000) // 8MHz
 #define SPI_CLOCK_DIV1  (VARIANT_MCK/5250000)  // 16MHz
#endif

RHHardwareSPI::RHHardwareSPI(Frequency frequency, BitOrder bitOrder, DataMode dataMode)
    :
    RHGenericSPI(frequency, bitOrder, dataMode)
{
}

uint8_t RHHardwareSPI::transfer(uint8_t data)
{
    return SPI.transfer(data);
}

void RHHardwareSPI::attachInterrupt()
{
#if (RH_PLATFORM == RH_PLATFORM_ARDUINO) || (RH_PLATFORM == RH_PLATFORM_PARTICLE)
  // Slave SPI does not exist on ESP8266
  #ifndef ESP8266
    SPI.attachInterrupt();
  #endif
#endif
}

void RHHardwareSPI::detachInterrupt()
{
#if (RH_PLATFORM == RH_PLATFORM_ARDUINO) || (RH_PLATFORM == RH_PLATFORM_PARTICLE)
  // Slave SPI does not exisi on ESP8266
  #ifndef ESP8266
    SPI.detachInterrupt();
  #endif
#endif
}

void RHHardwareSPI::begin()
{
    // Sigh: there are no common symbols for some of these SPI options across all platforms
#if (RH_PLATFORM == RH_PLATFORM_ARDUINO) || (RH_PLATFORM == RH_PLATFORM_UNO32) || (RH_PLATFORM == RH_PLATFORM_PARTICLE)
    uint8_t dataMode;
    if (_dataMode == DataMode0)
	dataMode = SPI_MODE0;
    else if (_dataMode == DataMode1)
	dataMode = SPI_MODE1;
    else if (_dataMode == DataMode2)
	dataMode = SPI_MODE2;
    else if (_dataMode == DataMode3)
	dataMode = SPI_MODE3;
    else
	dataMode = SPI_MODE0;
#if (RH_PLATFORM == RH_PLATFORM_ARDUINO) && defined(__arm__) && defined(CORE_TEENSY) && !defined(SPARK)
    // Temporary work-around due to problem where avr_emulation.h does not work properly for the setDataMode() cal
    SPCR &= ~SPI_MODE_MASK;
#else
    SPI.setDataMode(dataMode);
#endif

#if (RH_PLATFORM == RH_PLATFORM_ARDUINO) && defined (__arm__) && !defined(CORE_TEENSY) && !defined(SPARK)
    // Arduino Due in 1.5.5 has its own BitOrder :-(
    ::BitOrder bitOrder;
#else
    uint8_t bitOrder;
#endif
    if (_bitOrder == BitOrderLSBFirst)
	bitOrder = LSBFIRST;
    else
	bitOrder = MSBFIRST;
    SPI.setBitOrder(bitOrder);

    #ifdef ESP8266
    long divider;
    #else
    uint8_t divider;
    #endif
    switch (_frequency)
    {
	case Frequency1MHz:
	default:
#ifdef ESP8266
      divider = SPI_CLOCK_DIV16;
#elif F_CPU == 8000000
	    divider = SPI_CLOCK_DIV8;
#else
      #if (RH_PLATFORM == RH_PLATFORM_PARTICLE)
        #if PLATFORM_ID == 0 // Core 72MHz => 1.12MHz
        divider = SPI_CLOCK_DIV64;

        #elif PLATFORM_ID == 6 // Photon 120MHZ =3.6MHz
          divider = SPI_CLOCK_DIV128;
        #else
          #error "*** Particle PLATFORM_ID not supported by this library. Particle PLATFORM should be Core or Photon"
        #endif
      #else
	     divider = SPI_CLOCK_DIV16;
      #endif
#endif
	    break;

	case Frequency2MHz:
#ifdef ESP8266
      divider = SPI_CLOCK_DIV8;
#elif F_CPU == 8000000
	    divider = SPI_CLOCK_DIV4;
#else
    #if (RH_PLATFORM == RH_PLATFORM_PARTICLE)
      #if PLATFORM_ID == 0 // Core 72MHz => 2.25Mhz
        divider = SPI_CLOCK_DIV32;
      #elif PLATFORM_ID == 6 // Photon 120MHZ =>1.8Mhz
        divider = SPI_CLOCK_DIV64;
      #else
        #error "*** Particle PLATFORM_ID not supported by this library. Particle PLATFORM should be Core or Photon"
      #endif
    #else
      divider = SPI_CLOCK_DIV8;
    #endif
#endif
	    break;

	case Frequency4MHz:
#ifdef ESP8266
      divider = SPI_CLOCK_DIV4;
#elif F_CPU == 8000000
	    divider = SPI_CLOCK_DIV2;
#else
    #if (RH_PLATFORM == RH_PLATFORM_PARTICLE)
      #if PLATFORM_ID == 0 // Core 72MHz => 4.5Mhz
        divider = SPI_CLOCK_DIV16;
      #elif PLATFORM_ID == 6 // Photon 120MHZ =>3.75Mhz
        divider = SPI_CLOCK_DIV32;
      #else
        #error "*** Particle PLATFORM_ID not supported by this library. Particle PLATFORM should be Core or Photon"
      #endif
    #else
      divider = SPI_CLOCK_DIV4;
    #endif
#endif
	    break;
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

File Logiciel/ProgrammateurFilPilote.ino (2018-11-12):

/*
Programmateur Fil Pilote et Suivi Conso
Copyright (C) 2014 Thibault Ducret
Licence MIT
*/

// Includes
#include "TeleInfo.h"

// Defines
#define NB_FILS_PILOTES 7
#define ISOUSCRITE 30
#define DELESTAGE_RATIO 0.9 //ratio en % => 90%
#define IMAX 35

// ======== MAIN ============

// Fils pilotes
int SortiesFP[NB_FILS_PILOTES*2] = { D6,D7,D4,D5,D2,D3,A6,A7,A4,A5,A2,A3,A0,A1 };
int isousc = ISOUSCRITE;
float ratio_intensite = DELESTAGE_RATIO;

void initCdeFilsPilotes();
int fpControl(String command);
int setFP(String command);
void delestage();
int fpC(int i, char cOrdre);

unsigned int delestageEnCours = 1;
int nbDelestage = 0;

// Téléinfo
TeleInfo ti; // objet téléinfo
char c; // pour stocker un caractère reçu sur le port série
bool trameComplete = false;
int mypApp = TELEINFO_UINT_INVALIDE;
int myiInst = TELEINFO_UINT_INVALIDE;
int myindexHC = TELEINFO_UINT_INVALIDE;
int myindexHP = TELEINFO_UINT_INVALIDE;
unsigned int myisousc = TELEINFO_UINT_INVALIDE; // pour calculer la limite de délestage
float myDelestLimit = 0.0;
boolean init_teleinfo = false;
char etatFP[20] = "";


void setup()
{
  // == Fils pilotes ==
  initCdeFilsPilotes();
  Particle.function("fp", fpControl);
  Particle.function("setfp", setFP);
  Particle.variable("nbdelest", nbDelestage);
  Particle.variable("etatfp", etatFP);
   
  // == Téléinfo ==
  Particle.variable("papp", mypApp);
  Particle.variable("iinst", myiInst);
  Particle.variable("indexhc", myindexHC);
  Particle.variable("indexhp", myindexHP);
  
  Serial.begin(115200); // Port série USB
  Serial1.begin(1200);  // Port série RX/TX
}

void loop()
{
  updateTeleinfo();
	if (myiInst >= myDelestLimit) {
  
  
          if (delestageEnCours == 0)
          {
            //delestageEnCours ne passe jamais à 1 ???
			nbDelestage += 1; // on vient juste de passer en délestage
      	    delestage();
          }
	}
	else {
		delestageEnCours = 0; // Pas de délestage
	}
}

void updateTeleinfo() {

  while (Serial1.available())
  {
    c = (Serial1.read() & 0x7F);
    trameComplete = ti.decode(c);
    if (trameComplete)
    {
      mypApp=(int) ti.pApp();
      myiInst=(int) ti.iInst();
      myindexHC=(int) ti.indexHC();
      myindexHP=(int) ti.indexHP();
	  
	  if(!init_teleinfo) {
		myisousc = ti.iSousc();
		myDelestLimit = myisousc * ratio_intensite;
		init_teleinfo = true;
	  }
    }
  }

}

void initCdeFilsPilotes()
{
  unsigned int i;
  for (i=0;i<(NB_FILS_PILOTES*2);i+=1) // 2*nbFilPilotes car 2 pins pour commander 1 fil pilote
  {
        pinMode(SortiesFP[i], OUTPUT); // Chaque commande de fil pilote est une sortie
  }
  delay(1000);
  delestage(); // Hors gel
}

int fpControl(String command)
{
// C = Confort, A = Arrêt, E = Eco, H = Hors gel
// CCCCCCC => Commande tous les fils pilote en mode confort (ON)
// AAAAAAA => Commande tous les fils pilote en mode arrêt
// EEEEEEE => Commande tous les fils pilote en mode éco
// CAAAAAA => Tous OFF sauf le fil pilote 1

	unsigned int i;
	int returnValue = -1; // Init à -1 => Erreur
	
	command.trim();
	command.toUpperCase();
	
	if (command.length() == NB_FILS_PILOTES) // Vérifier que l'on a la commande de tous les fils pilotes
	{
		for (i=1; i<=NB_FILS_PILOTES; i+=1)
		{
			fpC(i, command.charAt(i-1)); //charAt(i-1) car l'index de "command" commence à 0
		}
		returnValue = 0; // OK
	}

   return returnValue;
}

int setFP(String command)
{
// C = Confort, A = Arrêt, E = Eco, H = Hors gel
// command = 1A => FP1 = Arrêt
	unsigned int i;
	
	int returnValue = -1; // Init à -1 => Erreur
	
	command.trim();
	command.toUpperCase();
	
	if (command.length() == 2) // Vérifier que l'on a la commande d'un seul fil pilote
	{
		i = command.charAt(0) - '0'; // numéro du fil pilote concerné, avec conversion ASCII > entier
		returnValue = fpC(i, command.charAt(1));
	}
	return returnValue;
}

int fpC(int i, char cOrdre)
{
// i => numéro du fil pilote (de 1 à NB_FILS_PILOTE)
// cOrdre => C = Confort, A = Arrêt, E = Eco, H = Hors gel

	int returnValue = -1; // Init à -1 => Erreur
	
	i = i-1; // On commence à 0
	
	if (i >= 0 && i < NB_FILS_PILOTES) // Vérifier que le numéro du fil pilote ne dépasse le MAX
	{		
		if (cOrdre == 'C') // Confort => Commande 0/0
		{
			digitalWrite(SortiesFP[2*i], LOW);
			digitalWrite(SortiesFP[(2*i)+1], LOW);
			etatFP[i]='C';
	 	}
		else if (cOrdre == 'E') // Eco => Commande 1/1
		{
			digitalWrite(SortiesFP[2*i], HIGH);
			digitalWrite(SortiesFP[(2*i)+1], HIGH);
			etatFP[i]='E';
		}
		else if (cOrdre == 'H') // Hors gel => Commande 1/0
		{
			digitalWrite(SortiesFP[2*i], HIGH);
			digitalWrite(SortiesFP[(2*i)+1], LOW);
			etatFP[i]='H';
		}
		else // Arrêt => Commande 0/1
		{
			digitalWrite(SortiesFP[2*i], LOW);
			digitalWrite(SortiesFP[(2*i)+1], HIGH);
			etatFP[i]='A';
	 	}
	 	returnValue = 0; // OK
	}
   return returnValue;
}

void delestage()
{
	unsigned int i;
	
	for (i=1; i<=NB_FILS_PILOTES; i+=1)
	{
		fpC(i,'H');
	}
	
	return;
}

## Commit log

2014-09-29 Ajout du schéma de principe
2014-09-29 Redimension de l'image
2014-10-26 Mise à jour des licences utilisées
2014-10-26 Ajout 1.0
    [ProgrammateurFilPilote_1.0.brd, ProgrammateurFilPilote_1.0.sch]
2014-10-26 Ajout de la librairie de l'optotriac TLP168J
    [ProgrammateurFilPilote_1.1.brd, ProgrammateurFilPilote_1.1.sch]
2014-10-27 Limite de delestage + optimisations
    Calcul automatique de la limite de délestage en fonction de l'intensité
    souscrite
    Suppression du duplicat de code fpControl / fpC
2014-10-29 Ajout de la version 1.1.1
    Ajout d’un fusible 1,25A retardé avant le Traco, et optimisation du
    routage
    [ProgrammateurFilPilote_1.1.1.brd, ProgrammateurFilPilote_1.1.1.sch]
2014-10-29 Ajout des captures OSHPark
2014-10-29 Ajout des schémas en PDF
2014-11-23 Ajout de la v1.2
    - Ajout d'une extension de ports I2C (16 I/O de plus) => MCP23017
    - Ajout d’un connecteur pour récepteur RF433 (pour le décodage de
    sondes Oregon)
    - Ajout des connexions pour souder une passerelle sans fil (RFM12B,
    RFM69CW ou RFM69HW) + connecteur Antenne U-FL ou fil à souder
    - Ajout connecteur I2C (OLED, ADC externe, … )
    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
    [ProgrammateurFilPilote_1.2.brd, ProgrammateurFilPilote_1.2.sch]
2014-12-07 Màj v1.2
    [ProgrammateurFilPilote_1.2.brd, ProgrammateurFilPilote_1.2.sch]
2014-12-08 Revert "Màj v1.2"
    This reverts commit 1069f649c9f2bcb6078a36c473411e82ae330c49.
    [ProgrammateurFilPilote_1.2.brd, ProgrammateurFilPilote_1.2.sch]
2014-12-08 Correction des liens
2014-12-08 Ajout des liens sur les nouveaux composants
2014-12-08 Ajout de la v1.2
    [ProgrammateurFilPilote_1.2.brd, ProgrammateurFilPilote_1.2.sch]
2015-01-07 Update README.md
    Ajout indication connecteur grove inverse sur le PCB
2015-01-23 Passage en Révision 1.2b
    Correction d'inversion du sens du connecteur Grove
    Correction d'inversion diode D14
    [ProgrammateurFilPilote_1.2.brd, ProgrammateurFilPilote_1.2.sch]
2015-01-23 Passage en révision 1.2b
    Correction des erreurs présentes en version 1.2
2015-01-24 Révision 1.2c
    [ProgrammateurFilPilote_1.2.brd, ProgrammateurFilPilote_1.2.sch]
2015-01-27 Passage des images à 50%
2015-01-27 Ajout contrôle de la checksum
2015-01-29 ajout pb de compilation si fichier README.md
2015-01-29 Correction Affichage Bareraph puissance
    [display.cpp]
2015-01-29 Passage du code lié à la téléinfo
    Passage du code lié à la téléinfo dans ce module spécifique pour
    conformité du setup() et loop()
2015-01-29 Correction bug commande dans fpcontrol
    [pilotes.cpp]
2015-01-29 Erreur de compil si MOD_TELEINFO pas défini
2015-02-14 Nom fonction = nom API exposé
    Renommage fonction fpControl -> fp
    Renommage fonction fsetFP -> setfp
    Afin d'avoir le nom des fonctions internes identiques aux fonctions
    exposées pour une meilleure lisibilité
2015-02-14 8 car max lus par loop
    Récupération que 8 caractères maximum sur la serial par loop, çà peut
    éviter des loop infinis au cas ou
2015-02-14 Gestion reconnexions Cloud
    Redéclaration des variables cloud exposées en cas de perte de connexion
    au cloud.
2015-02-15 Création de la fonction de délestage tournant
2015-02-15 Suppression du FP7 sur les cartes V1.0
2015-02-15 Suppression des Backup Eagle et Firmware
2015-02-17 Correction d'une regression
    Commande de la mauvaise zone suite à un problème d’index
    [pilotes.cpp]
2015-04-14 Utilisation de varibales Jeedom
2015-09-11 Creation pour compilation correcte
    [remora.ino]
2015-09-11 Revert "Creation pour compilation correcte"
    This reverts commit 39e56a132340877d6f0b19a521f7f4aca1e2624d.
    [remora.ino]
2015-09-22 Mise à jour de la licence pour le matériel
    Ajout du caractère non commercial (NC) pour que les ressources ne soient pas utilisées pour un but commercial
2015-09-30 ESP8266 / Cloud Variables & Function fix
    Compatibilité ESP8266,
    Intégration de la librairie universelle Téléinfo
    Correction du bug des variables et functions cloud plus exposées avec le
    nouveau firmware sur Spark/Photon
    Mise à plat de tous les fichiers dans le même dossier
    [MCP23017.cpp]
2015-09-30 Erreur de lien
2015-09-30 HeartBeat RBD LED avec la téléinfo
2015-09-30 Heartbeat si pas de Teleinfo
2015-09-30 Correction bug variables cloud
    [tinfo.cpp]
2015-10-06 Correction suite chg firmware
    [pilotes.cpp, remora.ino, route.cpp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]
2015-10-07 Création
    [ProgrammateurFilPilote_1.3.brd, ProgrammateurFilPilote_1.3.sch]
2015-10-21 Ajustements Finaux
    Résistances 390 Ohm pour nouveaux optos Sharp
    Commandes Opto/led via MCP par la masse
    Ajustement des borniers pour boitier rail DIN
    [ProgrammateurFilPilote_1.3.brd, ProgrammateurFilPilote_1.3.sch]
2015-11-17 Ajout d'une ébauche du tutoriel d'assemblage kit Remora v1.3
2015-12-02 Quelques màj suite au premier assemblage
2015-12-06 Mise à jour importante du tutoriel d'assemblage
2015-12-24 Ajout photos PCB
2015-12-24 Ajout lien passage optos en 3.3V

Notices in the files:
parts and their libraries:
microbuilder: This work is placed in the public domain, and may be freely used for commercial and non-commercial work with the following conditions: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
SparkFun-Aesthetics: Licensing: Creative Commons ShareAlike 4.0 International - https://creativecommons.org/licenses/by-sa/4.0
